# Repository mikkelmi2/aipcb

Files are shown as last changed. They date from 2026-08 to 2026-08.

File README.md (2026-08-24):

# aipcb

**A circuit board described as intent, compiled to KiCad.**

You write what the circuit *is* — in YAML. `aipcb` compiles it into real KiCad
schematics and boards, places, routes, pours, runs KiCad's own ERC and DRC on the
result, and can hand each pair to a field solver. Every problem points back at the
source line that caused it, and your KiCad edits survive the next build.

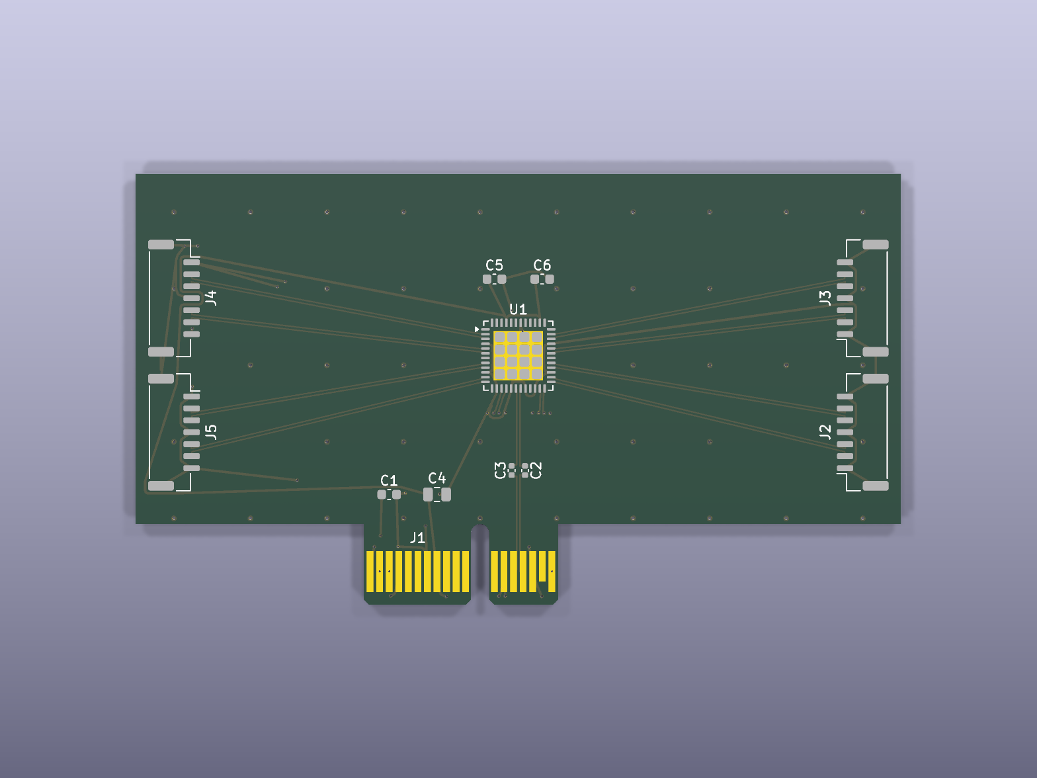
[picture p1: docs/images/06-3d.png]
examples/pcie-sata, rendered by KiCad from aipcb's own fabrication output


That is `examples/pcie-sata`, bundled here — a PCIe x1 card, four-port SATA, eleven
controlled-impedance pairs, four layers. Every image below is generated from it by
[`tools/make_images.py`](tools/make_images.py).

## What fifteen milestones hardened

**Deterministic compilation.** The same YAML gives byte-identical KiCad files —
rebuild unchanged and the file is not even rewritten. Every UUID is derived from
the source, which is what maps each element back to the line that asked for it.

**Verification you can trust.** ERC and DRC are run by KiCad itself, never
reimplemented, and come back as source-referenced diagnostics. Three invariants
guard the tool that produces them: `check` is a function of its source, no two
nets' copper may overlap, no simulation slice may be built with unbonded copper or
an unreachable reference plane. Each was learnt from a real defect, and
[`docs/reports/`](docs/reports/) tells the stories.

**Schematic generation.** Sheets drawn by convention from what the source already
knows — what serves what, which rails go up — proven identical to the source
netlist pin for pin, and ERC-clean.

**Manual layout is first-class.** `preserve` carries your KiCad edits across
rebuilds, `sync-placement` writes parts you moved back into the source,
`routing: manual` marks a net as yours, and the Freerouting bridge checks what
another router sends back.

## Maturity at a glance

| | | |
|---|---|---|
| Source format, compilation, `check`, schematics | **stable** | [`format.md`](docs/format.md) |
| Manual layout — preserve, `sync-placement`, `routing: manual` | **stable** | [`workflows.md`](docs/workflows.md) |
| Part placement | **basic** — shelf-packed clusters, unoptimised on purpose | [`roadmap.md`](docs/roadmap.md#placement) |
| Autorouting | **beta** — finishes this corpus, has never met a board it did not design | [`topology.md`](docs/topology.md) |
| SI simulation | **beta** — physically valid on ten of eleven links | [`m13.md`](docs/reports/m13.md) |
| Freerouting bridge | **new** — landed in M14e | [`external-routers.md`](docs/external-routers.md) |

## What beta means here

**The autorouter** finishes the corpus: `examples/pcie-sata` comes back **90 of 90
connections routed, 12 of 12 pairs coupled, 0 errors from KiCad's own DRC**, on
four layers. What it has not done is meet a board somebody else designed. The label
costs little: it **fails loudly**, naming each connection it could not finish
rather than leaving the board quietly short, and it is **optional** —
`routing: manual` and the Freerouting bridge take it out of the loop.

**SI simulation** extracts ten of the eleven flagship links physically; the
eleventh is reported unusable rather than plotted. It validates the layout you
declared, not the board a fabricator presses: it finds a pair routed too narrow, it
does not replace a test coupon, and it certifies compliance with nothing.

*Beta is a measurement, not a mood:* routing graduates once it has routed five
externally-contributed boards, passed a harder congestion stress example, and been
benchmarked against board size. The third of those is **done** — `aipcb bench`
records the whole corpus and CI diffs a subset on every change; routing cost grows
close to linearly in connections × triangulation size, and the numbers are in
[the M17 report](docs/reports/m17.md). The other two need a board this project did
not design. [The conditions in full](docs/roadmap.md#maturity-and-graduation).

## Source to fabrication, in six steps

### 1. Declare intent, not geometry

The width is *derived* from the impedance and the stackup — you never compute it:

```yaml
net_classes:
  pcie_tx:
    impedance_diff_ohm: 85    # the requirement; the trace width follows
    diff_pair_gap_mm: 0.15    # a manufacturing choice, so an input
    max_skew_mm: 0.127        # PCIe CEM r3.0 §4.7.7, for an add-in card
    reference: In1.Cu         # the plane the return current uses
```

### 2. It compiles to a schematic

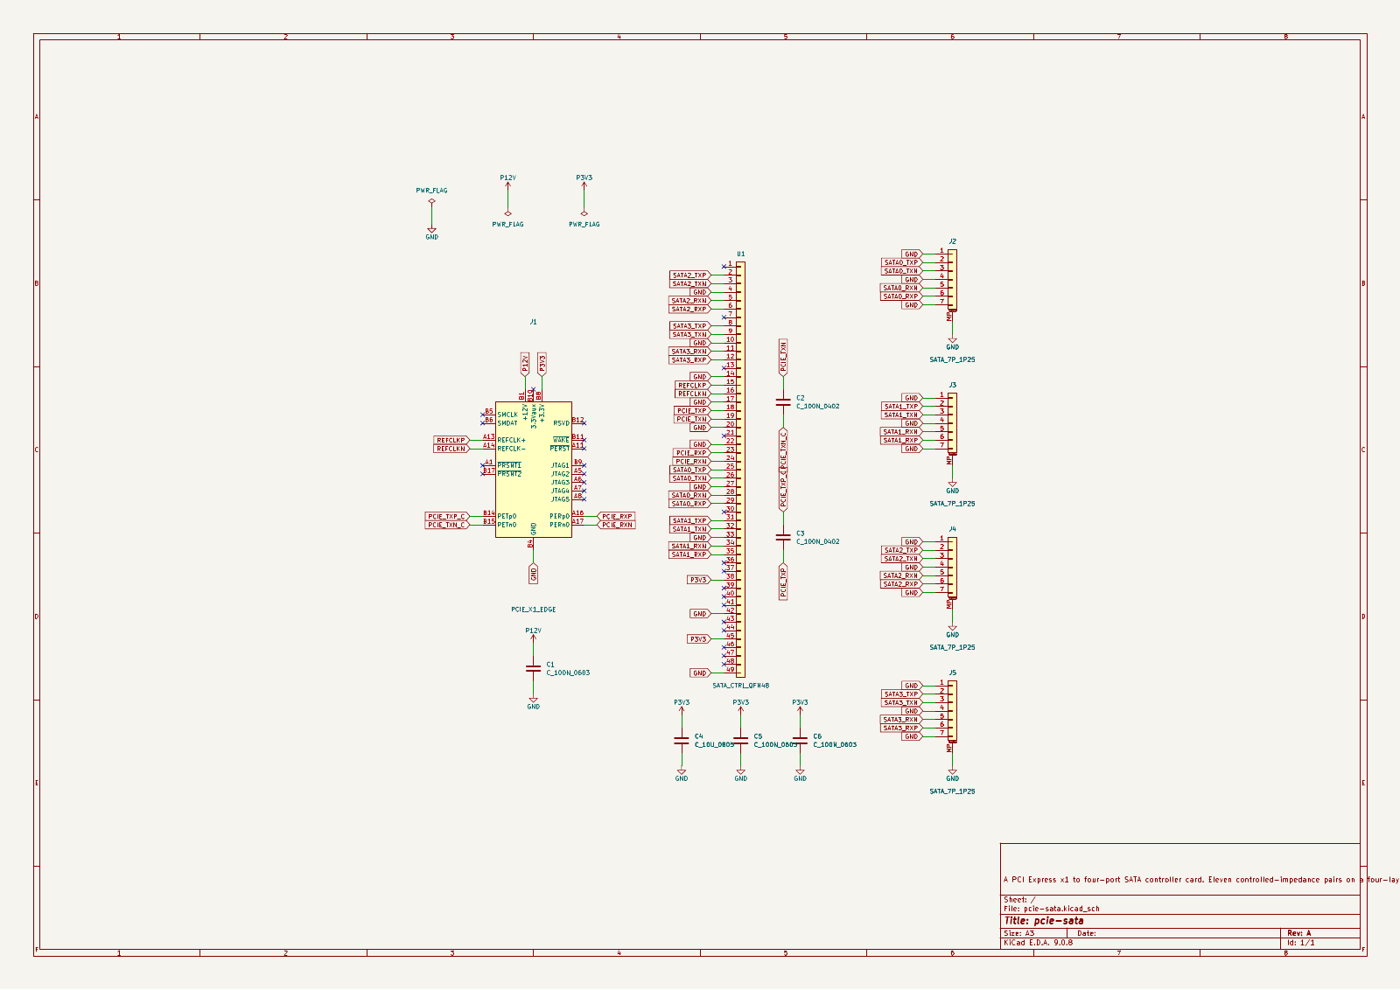
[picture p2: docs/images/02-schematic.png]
The pcie-sata schematic, rendered to A3


### 3. Parts are placed

Mechanically-fixed parts anchor the board, everything else is placed relative to
what it serves, and the outline is checked against the card-edge footprint's own
`Edge.Cuts` rather than drawn twice.

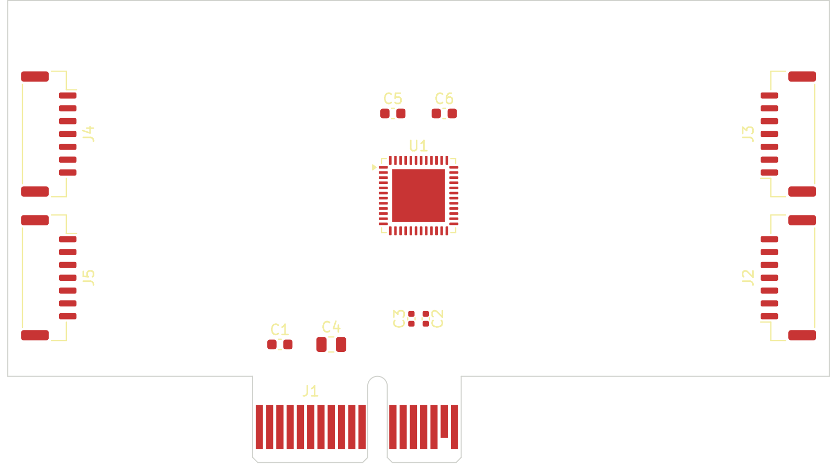
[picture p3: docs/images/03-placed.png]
The placed board, before any copper


### 4. And routed

A topological router negotiating congestion across four layers. Coupled pairs route
as one object — through the AC-coupling capacitors, across layer changes, at the
derived width.

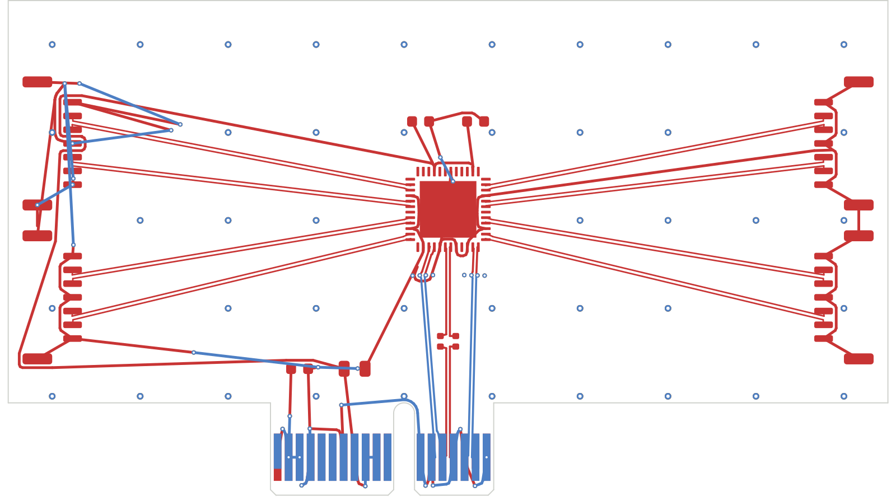
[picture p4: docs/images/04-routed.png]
The routed board, all eleven pairs coupled


### 5. The pairs are simulated

`aipcb simulate` slices each pair out of the routed board with its reference plane,
meshes it, runs openEMS.

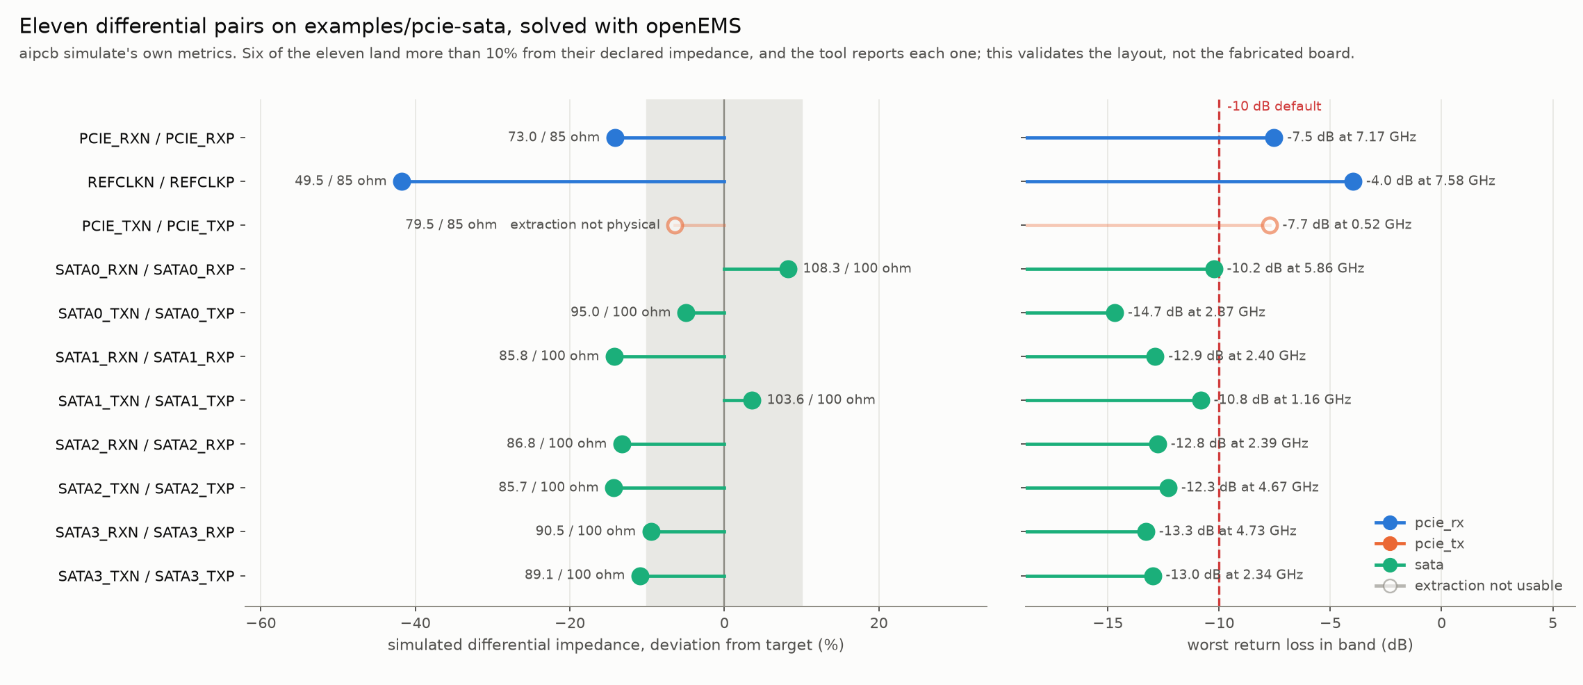
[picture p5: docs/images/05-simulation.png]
Simulated differential impedance and worst return loss, for each of the eleven pairs


The honest version of that picture: **six of the eleven pairs come back more than
10% from the impedance they declared**. That is the step doing its job: the
closed-form width says one thing, the field solver says how wrong it was.

### 6. And exported for fabrication — or for assembly

`aipcb export` writes Gerbers, drill files, a BOM and a placement file — the render
at the top of this page is KiCad's, from that output. `--assembly` adds what an
*assembler* needs on top of what a fabricator does: a bill of materials and a
centroid file in JLCPCB's or PCBWay's own columns, and a placement overlay drawn
from the centroid file itself, so the rotations can be looked at before anything is
ordered.

## You do the layout, if you want

| Mode | You do | aipcb does |
|---|---|---|
| **Full auto** | nothing | places, routes, pours, checks |
| **Hybrid** | draw the nets you care about, in KiCad | routes the rest *around* your copper, never through it, and checks all of it identically |
| **Fully manual** | all the copper | schematic, placement, pours, ERC/DRC, high-speed checks, export |

Hybrid is the one most people want. Mark a net or a whole class as yours:

```yaml
nets:
  PCIE_TXP: { class: pcie_tx, routing: manual }   # this one is mine
```

`aipcb check --json` then reports every net as `manual-routed`, `manual-pending`,
`auto-routed` or `handed-over`. `manual-pending` is the one that matters: a board
whose critical pairs are declared-and-not-yet-drawn looks finished to anything
counting unrouted connections, and this names it. Or hand the board to another
router — [Freerouting, headlessly](docs/external-routers.md).

## Quickstart

Python 3.12+ and **KiCad 9**, the backend rather than an optional extra: compiling
reads its stock libraries, and check, render and export shell out to `kicad-cli`.

```bash
git clone https://github.com/mikkelmi2/aipcb && cd aipcb
python3 -m venv .venv && .venv/bin/pip install -e .
.venv/bin/aipcb validate examples/usb-port/design.yaml
```

About 7 seconds on a warm pip cache, and out comes `ok: no problems found` with a
one-line summary. Now build it and open the result in KiCad:

```bash
.venv/bin/aipcb build examples/usb-port/design.yaml
kicad examples/usb-port/usb-port.kicad_pro
```

Then break it on purpose — change `diff_pair: USB_DP` to `USB_DPP` under
`nets: USB_DM:` — and validate again. Located, coded diagnostics rather than a
stack trace is what makes the loop work:

```
examples/usb-port/design.yaml:53:3: error[asymmetric-diff-pair]: net 'USB_DP'
names 'USB_DM' as its differential partner, but 'USB_DM' names USB_DPP
  at: nets.USB_DM.diff_pair
  hint: set `diff_pair: USB_DP` on 'USB_DM'
[... and error[unknown-diff-pair] for the net 'USB_DPP' that does not exist]

2 errors
```

`--json` gives the same thing machine-readably. [`docs/format.md`](docs/format.md)
is the reference for every key; [`docs/workflows.md`](docs/workflows.md) is how the
loop is used.

## What it does not do

**Not built.** Dense BGA escape, DDR fly-by topologies, HDI (blind and buried
vias), six or more layers, multi-sheet schematics, buses. Not "coming soon" —
absent, and a board needing them hands over rather than guesses. The class shown to
finish is the one above: small, high-speed-critical, two or four layers, and
[`docs/roadmap.md`](docs/roadmap.md) says which of the rest are wanted.

**No board from this repository has been fabricated yet.** When one has, this
paragraph will say so with pictures.

## Documentation

[`docs/README.md`](docs/README.md) is the map, and repeats the tiers above.

**This project was built milestone by milestone by AI agents, and the whole
engineering record is in the repository** — every specification, thirteen decision
records, and a delivery report per milestone measuring what actually landed. Start
at [`docs/reports/`](docs/reports/): written for someone who was not there, and
candid about what did not work.

Contributions are welcome — [`CONTRIBUTING.md`](CONTRIBUTING.md) says how. A board
this did not design is the most useful thing you can bring.

Apache-2.0. See [`LICENSE`](LICENSE) and [`NOTICE`](NOTICE).

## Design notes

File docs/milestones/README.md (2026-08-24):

# Milestones

The milestone specifications this project is built from, in execution order, each
paired with its delivery report in [`docs/reports/`](../reports/). A milestone file
is the *prompt* — what was asked for; the report is what was actually delivered,
with the numbers.

> **These files describe planned or historical work.** They are only relevant when a
> milestone is explicitly being executed. If you are doing ordinary development
> work, do not read a future milestone file as a description of existing
> functionality — nothing beyond the executed rows below is built. For what the project *does*
> today, read [`README.md`](../../README.md), [`docs/format.md`](../format.md) and
> the ADRs in [`docs/decisions/`](../decisions/).

| File | Milestones | Status |
|---|---|---|
| [`m1-m7-base.md`](m1-m7-base.md) | M1–M7 — source format, KiCad emission, check loop, query layer, incremental builds, topological routing | executed |
| [`m8-multilayer.md`](m8-multilayer.md) | M8 — layered triangulations, negotiated congestion, differential pairs | executed |
| [`m9-mech-placement.md`](m9-mech-placement.md) | M9 — board outline, mechanical placement, fanout, honest failure | executed |
| [`m10-pours.md`](m10-pours.md) | M10 — copper pours, stitching vias, plane integrity | **blocked** — see [`m10.md`](../reports/m10.md) |
| [`m11-highspeed.md`](m11-highspeed.md) | M11 — controlled impedance, edge connectors, via transitions | pending |
| [`m12-simulation.md`](m12-simulation.md) | M12 — SI simulation integration (openEMS/gerber2ems) | pending |
| [`orchestrator-m10-m12.md`](orchestrator-m10-m12.md) | runs M10 → M11 → M12 unattended, with gates between them | pending |
| M13 | routing correctness, the impedance model, the skew verdict | executed — [`m13.md`](../reports/m13.md) |
| M14 | readable schematics, optional routing, the external-router bridge | executed — [`m14.md`](../reports/m14.md) |
| [`m15-public.md`](m15-public.md) | M15 — hygiene sweep, licence package, the public README, contributor surface, CI | executed — [`m15.md`](../reports/m15.md) |
| M16 | toporouter lessons, part 1 — the capacity check's honesty, the exposure guards, the benchmark harness | executed — [`m16.md`](../reports/m16.md) |
| [`m17-measured-improvements.md`](m17-measured-improvements.md) | M17 — router improvements, part 2: via minimisation, retrace elimination, stretcher performance | executed — [`m17.md`](../reports/m17.md) |
| [`m18-literature-survey.md`](m18-literature-survey.md) | M18 — the routing literature survey (documentation only) | executed — [`m18.md`](../reports/m18.md) |
| [`m19-incremental-geometry.md`](m19-incremental-geometry.md) | M19 — router improvements, part 3: the congestion stress board, and the geometry that gets rebuilt | executed — [`m19.md`](../reports/m19.md). M19s and M19a landed, **M19b was rejected on its own numbers**, M19c's gate is open and sequenced after the fab round, M19d published. The review that turned M18's draft into this is [`m19-review.md`](../reports/m19-review.md) |
| [`m20-placement-quality.md`](m20-placement-quality.md) | M20 — placement quality: rotation, routability-estimated packing, and the zero-router-change experiment | **approved** 2026-08-24 — nothing started; sequenced after the `pcie-sata` fab round |
| [`m21-assembly-outputs.md`](m21-assembly-outputs.md) | M21 — assembly outputs: BOM and pick-and-place export, for an assembled order | executed — [`m21.md`](../reports/m21.md). The files are built and reviewed; **the acceptance criterion is not met and the reason is the design rather than the tooling** — `examples/pcie-sata`'s controller is a stand-in with an invented pinout and cannot be given a part number |

**Drafting a chain of candidates?** Budgets re-anchor after every landed one — see
[CLAUDE.md](../../CLAUDE.md#budgets-re-anchor-after-every-landed-candidate). A budget
quoted as a percentage of a corpus the same milestone is allowed to change, or priced
off a profile an earlier candidate has already invalidated, is how M19 lost two
candidates that had both done real work.

The delivery report requirement was introduced with M10, so the earlier
milestones ran without one. [`m8.md`](../reports/m8.md) was reconstructed after the
fact from the repository's own history and says so at the top;
[`m9.md`](../reports/m9.md) was written from that milestone's own measurements
immediately after it landed. There is no report for M1–M7.

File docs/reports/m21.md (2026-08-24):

# M21 — assembly outputs: BOM and pick-and-place

The fab round wanted two files an assembler accepts. They exist now, in three
formats, with the research behind each column recorded in
[ADR 0015](../decisions/0015-assembly-outputs.md) and a placement overlay to check
them against.

**And the milestone's own acceptance criterion is not met, for a reason that is not
about the tooling.** `examples/pcie-sata` cannot produce a package with zero
missing-part-number warnings, because seven of its eleven placed parts have no
manufacturer part number and one of them cannot be given one: the SATA controller is
a stand-in with an invented pinout. §6 is that finding in full, and it is the part of
this report worth reading first if the next session is the order.

Measured on 2026-08-24, KiCad 9.0.8, on the development machine.

---

## The scoreboard

| | Asked for | Delivered |
|---|---|---|
| **research** | current JLCPCB and PCBWay requirements, in an ADR with sources | [ADR 0015](../decisions/0015-assembly-outputs.md) §2, both fabs, fetched from their own documentation |
| **M21a** procurement fields | `mpn`, `manufacturer`, `supplier_refs`, `assembly`, backward compatible | done; `assembly` **measured rather than defaulted**, and a fourth value added — §2 |
| **M21b** BOM export | `--bom [--format …]`, grouped, deterministic | done, three formats |
| **M21c** CPL export | `--cpl [--format …]`, rotation mapped, overlay, back-side guard | done; **no rotation-correction table ships, deliberately** — §4 |
| **M21d** the bundle | `--assembly`, zipped, committed acceptance artifact | done; artifact at `tests/golden/pcie-sata/assembly/`, checklist in §5 |
| **acceptance** | pcie-sata exports with zero missing-mpn warnings | **not met** — seven parts block it, §6 |

---

## 1. The audit: what already existed, and why none of it was an assembly file

M21's brief carried a correction — `aipcb export` advertises "a BOM and a placement
file", so this might be hardening rather than building. It was worth checking and the
answer was no. What shipped before M21:

* **`bom.csv`**, from `kicad-cli sch export bom`, columns
  `Reference,Value,Footprint,QUANTITY,Description`. No part number, no manufacturer,
  no fab id — because none of those was ever written into the schematic. The
  `Supplier` model has carried `manufacturer` and `mpn` since the beginning and
  **only `datasheet` was ever emitted anywhere**; the other two were dead fields.
* **`pcie-sata-all-pos.csv`**, from `kicad-cli pcb export pos`, columns
  `Ref,Val,Package,PosX,PosY,Rot,Side`, sides spelled `top`/`bottom`, rotations
  signed.
* Designators compressed to ranges (`J2-J5`) by KiCad's grouping — and neither fab
  documents range notation, while JLCPCB matches designators between the two files
  literally.

Both files are correct KiCad output. Neither is a file an assembler takes. They are
kept exactly as they were — byte-identical, still in the fabrication package — and
the assembly files are additive and off unless asked for.

The full gap table is [ADR 0015](../decisions/0015-assembly-outputs.md) §1.

---

## 2. M21a — the schema, and the one place the brief was not followed

`mpn`, `manufacturer` and `supplier_refs` are as specified. `assembly` is where this
deviates, and it is worth stating plainly because it was a deliberate refusal of the
brief's default.

> **Brief:** `assembly: smt | tht | dnp | none` (default smt)
> **Built:** the same four values, plus a fifth state — *unset* — which is
> **measured off the footprint** rather than defaulted.

The reason is a measurement on this repository's own corpus. Four bundled examples
are built around through-hole parts: the breakout headers in `congestion`, the DIP-8
in `mcu-4layer` whose two rows of pins are the obstacle that board exists to route
around, the pin headers in `backplane`, the power header in `ldo-supply`. PCBWay's
centroid file is documented as **surface-mount only**. A default of `smt` would have
put every one of those into a file that must not contain them, and it would have done
it silently, in exactly the file whose job is to be checked.

So an undeclared `assembly` is read off the footprint KiCad actually placed — its
`(attr …)` flags, then its pad types — and a declaration always wins. Verified live:

```
mcu-4layer, generic BOM        →  J2 (PinHeader_1x06)  tht
                                  U1 (DIP-8_W7.62mm)   tht
mcu-4layer, PCBWay centroid    →  J2, U1 absent; C1-C3, J1, R1-R3, U2 present
```

**A fourth value the brief did not have, which the corpus needed: `none`.** A
card-edge finger field and a mounting hole are on the board, are on a net, and are
neither bought nor placed. Before it existed, `examples/pcie-sata`'s gold fingers
appeared on the bill of materials as a line no assembler could source, and
`examples/enclosure`'s two M3 holes with them. `PCIE_X1_EDGE` and `MOUNT_M3_PAD` now
declare `assembly: none` and are absent from both files.

**Backward compatibility** is not asserted, it is exercised: `supplier: {mpn: …}`
predates this milestone and `ATTINY85_DIP8` and `AMS1117_3V3` still use it.
`Part.procurement()` folds the two spellings, declaring both with different values is
an error, and `mcu-4layer` exports with those two part numbers filled in from the old
spelling. Every one of the twelve examples exports.

---

## 3. M21b and M21c — the files

`aipcb export --bom --cpl --assembly --format jlcpcb|pcbway|generic` (repeatable).
Columns and per-fab rules come from each fab's published requirements; sources in
ADR 0015 §2. Three rules are worth repeating here because they are decisions rather
than transcription:

* **PCBWay's centroid holds surface-mount parts only** — their words. A format is
  therefore not a rename, it carries rules.
* **Designators are listed, never ranged.** `J2,J3,J4,J5`, not `J2-J5`.
* **DNP is said in words**, in the BOM's `Comment` column, because neither fab
  documents a machine-readable way to say it, and the part never reaches the
  centroid. A silent DNP is a fitted part.
* **JLCPCB's documented limits are checked too**, not only its column names: a BOM
  line carrying more than 200 designators is a rejected upload, so it warns and
  names the line. No bundled example reaches it — `backplane`'s sixteen terminator
  resistors are the longest line in the corpus.

**The coordinates are not computed twice.** The centroid is a transcription of the
placement CSV `kicad-cli` already writes for the Gerber package, which is exported
with the same `--use-drill-file-origin`. Measured on `pcie-sata`: `aux_axis_origin`
`(100, 145)`, `U1` at `(140, 119)` in KiCad's frame, `(40, 26)` in the file — origin
subtracted, Y inverted. A test asserts every centroid coordinate equals the placement
file's, so the assembler's file and the fabricator's are one measurement rather than
two that agree today.

**The bill is driven by the netlist, not by the placement file** — a bug found while
building, and worth recording. Deriving the BOM from placement rows meant that any
footprint KiCad excludes from position files silently vanished from the order. That
is right for a card edge and catastrophic for a battery holder, and only the design
knows which is which. Parts with no placement row are now on the bill and off the
centroid.

---

## 4. Rotation — the convention is implemented, the correction is not

This is the trap the brief named, and the answer is narrower than "implement the
mapping".

**The convention needs no transform.** Both fabs document degrees, counter-clockwise
positive. JLCPCB: *"The rotation of the component given in degrees. Positive values
are counter clockwise."* KiCad writes degrees, counter-clockwise positive. The only
difference is range — KiCad signs them, the fabs' samples run 0–360 — so the value is
folded into `[0, 360)`. **No part turns.** `-90` becomes `270`, which is the same
orientation said differently, and eight parametrised cases pin it.

**The correction is a different thing and no table ships.** What breaks boards is not
the convention but the zero reference: a fab whose parts library holds a package at a
different orientation from the KiCad footprint needs a per-package offset. Three
things were established about it:

1. **Neither fab publishes it.** JLCPCB documents the convention and not the offsets.
   There is no authoritative table to verify against — and M21's guardrail says the
   mapping must be verified against the fab's documented convention rather than
   inferred.
2. **It is not algorithmic.** The community tooling that solves this — KiBot's
   `rot_footprint`, `kicad-jlcpcb-tools`' rotation database — is a hand-maintained
   lookup of regular expressions over footprint names.
3. **It is not even a function of the footprint.** KiBot's own documentation:
   *"you can have two components with the same footprint and different rotations in
   the same project."*

A table keyed by footprint is a heuristic by construction, and a wrong offset looks
exactly like a right one until the board comes back. Copying one out of a GPL project
would also be the same act as copying its code.

**So the verification is a picture.** `--assembly` renders a placement overlay per
populated side, drawn from the centroid file's own rows — not from the board, because
the board is not what gets sent. Every part where the file puts it, turned the way the
file turns it, with a dot marking where pin one lands after that rotation, and the
bottom side mirrored as it is inspected in the real world.

the placement overlay

---

## 5. M21d — the acceptance artifact, and the checklist against it

`tests/golden/pcie-sata/assembly/` holds the package: the JLCPCB BOM and centroid,
the complete generic pair, and the top-side overlay. `python -m tests.regenerate_golden`
rewrites it and a test compares against it, so a change to a column, a part or a
rotation shows up as a diff — the diff an assembler would have received.

**The manual review, once, line by line:**

| Check | Result |
|---|---|
| every placed part has a part number | **no** — 7 of 11: `C1, C2, C3, C4, C5, C6, U1`. §6 |
| designators on the centroid all appear on the bill | yes — JLCPCB rejects a mismatch, and a test asserts the containment |
| designator case consistent between the files | yes — one source, one spelling |
| units millimetres, `Layer` = `Top`/`Bottom` | yes |
| rotations within [0, 360) | yes — `0`, `90`, `270` only on this board |
| rotations eyeballed against the overlay | yes — `J2`/`J3` on the east edge at 90°, `J4`/`J5` on the west at 270°, facing inward; `C2`/`C3` at 270°/90° either side of the transmit pair; `U1` at 0°. All agree with the routed board plot |
| non-components off both files | yes — `J1`, the card-edge finger field, appears on neither |
| DNP handling | **not exercised by this board** — it has no DNP parts. Unit tests cover it, and §5.1 exercises it end to end on a derived design |
| polarity | **not exercised by this board** — every part on it is non-polarised, so the overlay's main value, catching a backwards diode, is untested against a real design |
| byte-stable across runs | yes — asserted by a test over every file in the package |

Two entries in that table are honest gaps rather than passes, and they are why the
overlay is documented as the thing to look at rather than a formality: the first
design with a diode or an electrolytic is the one that tests it.

### 5.1 DNP, exercised on a real design rather than only in fixtures

No bundled example marks a part do-not-populate, so the acceptance clause "DNP flows
correctly through both files" was checked against a copy of `ldo-supply` with
`dnp: true` added to `J2` — one of its two identical 2-pin power headers, chosen
because it makes the harder claim as well as the easy one:

```
BOM   PWR_IN,J1,Connector_PinHeader_2.54mm:PinHeader_1x02_P2.54mm_Vertical,
      PWR_IN (DNP - DO NOT POPULATE),J2,Connector_PinHeader_2.54mm:PinHeader_1x02_P2.54mm_Vertical,
CPL   C1 C2 C3 C4 J1 U1                     ← J2 absent
```

`J2` is marked on the bill and off the centroid, which is the clause. **And `J1` and
`J2` did not merge**, though they are the same part with the same footprint and the
same value — which is the defect a unit test caught while this was being built: with
the part number alone as the grouping key, a do-not-populate instance and a fitted
one became one line, and that line was marked whichever it met first. Half the
board's headers would have been fitted or not according to alphabetical order.

---

## 6. What would block a real order

**Seven of eleven placed parts on `examples/pcie-sata` have no manufacturer part
number.** The tool names them rather than failing silently:

```
warning[assembly-missing-mpn]: 7 placed parts have no manufacturer part number:
  C1, C2, C3, C4, C5, C6, U1
```

They divide into two cases and only one of them is data entry.

**The six capacitors are a procurement decision nobody has made.** The library
specifies each of them completely enough to buy — "100 nF X7R ceramic capacitor,
0603, 50 V" — but choosing *which manufacturer's* 100 nF, and which LCSC code, is a
decision with a stock level and a price attached. This milestone did not make it up.
An invented LCSC code is not a missing part, it is **the wrong component soldered to
the board**, and that failure is silent until the board does not work. The one part
number added here, JST's `SM07B-GHS-TB` on the SATA connectors, was added because
KiCad's own footprint is a binding to exactly that part — the part number is in the
footprint's name — and not because it was looked up.

**`U1` cannot be given a part number at all, and this is the finding.**
`examples/library/highspeed.yaml` says so in its own header, and the audit for this
milestone is what made it matter:

* the symbol is a **borrowed 49-pin generic connector**, chosen because KiCad ships
  no symbol for an ASM1064-class bridge;
* the **pinout is this board's own invention** — the signal assignments are plausible
  and they are not any real part's;
* the **power architecture is explicitly scenery**: the library says a real bridge of
  this function has a core rail, separate analog and PLL supplies and an I/O supply,
  and carries 15–25 capacitors. This board declares two supply pins on one 3.3 V rail
  and carries six.

So there is no manufacturer part whose pins are wired the way this design wires them.
A part number written there would be a number an assembler could order and a
component that could not work — and, worse, a board that assembles cleanly and is
dead.

**What this means for the fab round, stated plainly.** M21's premise was that the
assembly files were the last tooling blocker before ordering `pcie-sata` assembled.
The tooling blocker is gone. **The blocker that remains is the design**: `pcie-sata`
is a routing demonstration with a stand-in controller, and it is not a board that can
be populated and work, whatever files are generated for it. That is a decision for
the owner and not something this milestone should have quietly resolved by inventing
data. Three ways forward, in the order they seem sensible:

1. **Order it bare.** Every fabrication file has been correct since M10 and the
   assembly files are not needed. The board demonstrates routing, impedance and
   pours, and none of that requires it to be populated.
2. **Give the flagship a real controller** — a real MPN, its real pinout, its real
   power tree — which is a design milestone with a schematic review in it, and would
   also give the SI work a part whose reference design exists.
3. **Assemble a different board.** `ldo-supply` and `mcu-4layer` are made of real,
   orderable parts and need only their part numbers filled in; both already carry
   two.

---

## 7. What is not built

* **Supplier API integration** — out of scope by the brief, and §6 is the argument
  for putting it on the roadmap: the thing that blocks an order is a part number
  nobody has looked up, and looking one up is exactly what an API does.
* **Panelization** — still fab-level, still out.
* **Two-sided assembly** — refused rather than approximated. `side: back` validates,
  warns and places on the front (M9), so an assembly export on a board with a
  back-side part errors with `assembly-back-side-unsupported` and names the parts.
  The guard stays until `side: back` is implemented.
* **Any router or placement work.** None was touched; every board hash is unchanged.

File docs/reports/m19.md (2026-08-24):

# M19 — router improvements, part 3: the stress board, and the geometry that gets rebuilt

M18 found that the function three milestones had called the hot spot costs 0.039
profiled seconds, and that what the `tighten` *stage* actually spends its time on is
building — and discarding — the free space, the triangulation and the via sites that
tightening is done against. This milestone acts on that, in the order the survey
recommended and the owner approved: build the board the work should be measured on,
then take the two cheap candidates, then decide whether the expensive one is still
worth its risk.

Everything below was measured on 2026-08-24 on the development machine (16 cores,
30 GB RAM, Linux 7.0.0-29-generic), CPython 3.14.4, Shapely 2.1.2 / GEOS 3.13.1,
KiCad 9.0.8 — the same machine and the same versions the M16, M17 and M18 figures
were taken on, which is the only reason the wall-clock comparisons mean anything.

---

## The scoreboard

| Candidate | Budget, stated before | Measured | Verdict |
|---|---|---|---|
| **M19s** the congestion stress board | more nets than channels on ≥ 1 cut, from the tool; routes or hands over cleanly; byte-stable; no runtime budget | 168 connections, **110 routed / 58 handed over**; the capacity arbiter fires **132 times**, worst cut 3.77 mm against 4.95 mm of demand; **5 negotiation iterations, not converged**; byte-stable; 137.3 s | **landed** |
| **M19a** vectorise the point-location tail | ≥ **10 %** corpus `router_seconds`, **every board hash byte-identical** | **−2.9 %** corpus, −8.3 % on the eleven original boards, −20.8 % on the board it helps most; **every hash byte-identical**; tie-break tested | **misses its budget — kept, §2.3 flags the call** |
| **M19b** bound the private repair field | ≥ **25 %** further, completion and copper unchanged | **−1.0 %** corpus, −9.7 % on the eleven; completion unchanged; **copper +12.5 mm on `pcie-sata`** | **rejected**, reverted, numbers in §3 and in the survey note §5 |
| **M19c** incremental free-space mesh | conditional on M19a + M19b landing ≤ half the corpus routing time | gate **opens** (2.9 % landed), and the stress board's profile says **64 % of its routing time is `triangulate_free`** | **not started** — the fab round comes first, §4.2 |
| **M19d** re-fit the extrapolation | publish the new exponents against M16's and M17's | eleven boards **1.67 / 2.55 / 1.09**, unmoved again; twelve boards **1.87 / 2.00 / 1.03**; 900 connections **9.3 → 22.5 min** | **published** |

---

## 0. Before writing code — the profile re-taken at this HEAD

[CLAUDE.md](../../CLAUDE.md)'s rule, and the milestone's own "Before writing code"
section, both demand that M18's table be re-measured rather than assumed. It was, at
this milestone's HEAD (`c6c67b5`, whose `src/` is byte-identical to the baseline
commit `3b59a52`), from a scratch script outside the repository. No timer went into
`src/`.

### 0.1 The table reproduces

| | M18 (`4a41546`) | M19 (`c6c67b5`) |
|---|---:|---:|
| `pcie-sata` unprofiled wall | 19.3 s | **19.314 s** |
| `pcie-sata` profiled wall | 37.4 s | **30.625 s** |
| `_retry` → `_repair` cumulative | 16.30 s | **16.340 s** |
| `field.py::_via_sites` | 12.35 s | **12.367 s** |
| `geometry.py::geometry_for` | 10.71 s | **10.687 s** |
| `triangulate.py::locate_many` (tottime) | 2.80 s | **2.808 s** |
| `shapely::constrained_delaunay_triangles` | 4.30 s | **4.309 s** |
| `triangulate.py::_inside` calls | 3 140 252 | **3 140 252** |
| `triangulate.py::_sign` calls | 9 426 354 | **9 426 354** |
| `funnel.py::tighten` | 0.039 s | **0.039 s** |

The one number that moved is the profiled wall clock, 37.4 s → 30.6 s, which is the
instrument and not the router: the call counts are identical to the unit and every
cumulative figure agrees to three decimal places. **M18's profile stands.**

### 0.2 The split M19c's value depends on

The milestone asks for `geometry_for`'s cost to be split between the GEOS set
operations and the triangulation, because *"an incremental mesh replaces only the
second unless the set operations go too"*. Measured by wrapping the real functions
from outside, in a separately-timed third run so the wrappers never contaminate the
unprofiled figure:

| `pcie-sata`, wall seconds under wrappers | seconds | calls |
|---|---:|---:|
| `geometry_for` total | 7.527 | 176 |
| ├ `free_space` — the GEOS set operations | **1.767** | 244 |
| │  └ of which `union_all` | 1.255 | 244 |
| └ `triangulate_free` — the triangulation | **6.900** | 244 |
| &nbsp;&nbsp;&nbsp;└ of which `constrained_delaunay_triangles` | 4.294 | 244 |

(`free_space` and `triangulate_free` are called 244 times against `geometry_for`'s
176 because `build_field` calls them too; the split is over all of them, which is
the number an incremental mesh would have to displace.)

**The answer is roughly 20 : 80.** Of the geometry construction, the set operations
are 1.77 s and the triangulation 6.90 s, of a 16.6 s instrumented run. So an
incremental mesh addresses the larger share — but the `free` polygon itself cannot
go, because `_via_clears` and `_covered` ask it distance-to-boundary questions a
triangulation answers badly. **L1's ceiling on this board is therefore the 6.9 s of
`triangulate_free`, not the 8.7 s of both**, and 4.3 s of that 6.9 s is inside GEOS
already. That figure is what §4 weighs the gate against.

The same measurement on `mcu-4layer`: `geometry_for` 1.764 s, `free_space` 0.476 s,
`triangulate_free` 2.247 s, `constrained_delaunay_triangles` 1.418 s, of a 5.2 s
instrumented run. Same shape, same ratio.

---

## 1. M19s — the congestion stress board

### 1.1 What it is

[`examples/backplane`](../../examples/backplane/design.yaml) is a six-slot passive
backplane for a card cage: a 20-way ribbon from the host at the west end, six card
positions on a 22 mm pitch, sixteen pull-ups terminating the bus at the east end, on
a four-layer stackup with a ground plane on In1 and a power plane on In2. 30
components, 18 nets, 168 connections attempted, 190 × 56 mm.

The difficulty is mechanical and it is arithmetic. The cage's card guides sit
between adjacent card positions, they are bolted through the board, and nothing may
pass under one — so each guide leaves a single **4.0 mm channel** across the middle
of the board, and everything on the bus has to use it, seven times over.

* Sixteen signals at 0.25 mm wide with 0.2 mm clearance want **0.45 mm** of any cut
  they cross. VCC and GND want **0.6 mm** each. **Demand at each channel: 8.4 mm.**
* The channel is 4.0 mm. With the guide's own clearance off both sides, the shared
  field scores the cut across it at about **3.8 mm per signal layer — 7.6 mm** across
  the two of them.

Eight point four against seven point six, seven times. It does not fit, and it is
not meant to.

### 1.2 More nets than channels, from the tool

The milestone asks for this to be shown by the capacity model rather than asserted
in prose. The router's own arbiter — `_blocking_cuts` in
[`plan.py`](../../src/aipcb/route/plan.py), charging the same cuts against the same
`LayerField` capacities that
[`check_capacity`](../../src/aipcb/route/check.py) charges declared sketches
against — reports it on every handed-over connection, under `blocked_at` in
`aipcb route all --json`:

```json
{"layer": "B.Cu", "at": [145.0, 128.0], "width_mm": 3.767, "demand_mm": 4.95,
 "over_subscribed": true,
 "nets": ["D1","D10","D11","D2","D3","D7","D8","D9","IRQ","RESET","STROBE"]}
```

**Eleven nets wanting 4.95 mm of a corridor that is 3.767 mm wide.** Across the run
the arbiter marks a cut over-subscribed **132 times**, and `aipcb bench` counts
**130 over-subscribed cuts** on the finished board. Both are the same capacity model
`check_capacity` implements; the difference is only that the arbiter charges the
router's own legs and `check_capacity` charges sketches from `layout.routes`, of
which this design deliberately declares none — declaring them would take the nets
out of the negotiation, which is the one thing this board exists to exercise.

**This is the first time the capacity arbiter has ever refused anything.** M17a
built it against M16a's special-cut model and found *not one* span on the whole
corpus rejected on capacity; length was binding everywhere. It is not binding here.

### 1.3 The honest outcome: it hands over, and says why

| | |
|---|---:|
| connections attempted | 168 |
| routed | **110** (65.5 %) |
| handed over | **58** |
| negotiation iterations | **5** |
| converged | **no** |
| crossings / self-crossings | 0 / 0 |
| copper | 2 690.150 mm |
| vias | 33 |
| DRC | clean on everything it did route |

Every one of the 58 is a `route-handed-over` warning naming the connection, the cut
that stopped it, that cut's width, the demand on it and the nets contending for it.
Nothing is silently dropped.

**Which nets lose is the interesting part, and it is what the design predicted.**
`CLK` is `rip_up: protected` at priority 90; it is routed end to end. Four of the
fifteen ordinary bus lines — `D0`, `D9`, `RESET`, `STROBE` — complete not one hop of
seven. The protection did exactly what the class docstring says it does, on the only
board in this repository with enough pressure to make it matter.

`backplane` is registered in `tests/conftest.py`'s `UNROUTABLE_EXAMPLES` alongside
`overconstrained`, with the reason written out there: it was built to be over
capacity, and a version of it that routed cleanly would have failed at its job.
Everything it *does* route is still DRC-clean, and
`test_routing_is_byte_stable`'s guarantee holds — two consecutive runs produce the
identical board, SHA-256 `ebc7d8a5…`.

### 1.4 The anchor point, published as a miss

M17d fitted `router_seconds` against connections attempted over the eleven boards
and extrapolated 11.3 minutes for a 900-connection board. The whole reason to build
a board at the top of the range is to find out whether that fit means anything out
there. Running M17d's method verbatim over the *eleven original boards* and asking
it to predict this one:

> **Predicted 38.6 s for 168 connections. Measured 137.3 s. A factor of 3.6.**

The fit under-predicts, badly, and the direction is worth naming: **the eleven-board
corpus contained no board that failed to converge in one negotiation iteration**, so
the fit had no way to see the cost of the other four. A power law in connections
alone cannot model a board that routes its connections five times over. §5 re-fits
with this point included and reports what it does to the exponent.

### 1.5 The corpus grows from eleven boards to twelve

The baseline is refreshed in its own commit, per
[`bench/results/README.md`](../../bench/results/README.md)'s rule. Both sets of
totals, so the step is visible and is not mistaken for a regression:

| | eleven boards (`3b59a52`) | twelve boards (`be400c8`) | of which `backplane` |
|---|---:|---:|---:|
| connections attempted | 278 | 446 | 168 |
| routed | 275 | 385 | 110 |
| copper | 3 897.150 mm | 6 587.300 mm | 2 690.150 mm |
| vias | 81 | 114 | 33 |
| layer changes | 86 | 120 | 34 |
| corpus `router_seconds` | 29.476 | **167.036** | 137.342 |

**The eleven original boards are byte-identical.** `bench --compare` against the old
baseline reports exactly one line — `backplane: not in the baseline` — and no change
to any other board's hash, copper, vias or completion. The new board is 82 % of the
corpus's routing time, which is what a stress board is for and is why **every
percentage in §2 and §3 below is quoted against 167.036 s, not against 29.476 s.**

### 1.6 The multi-sheet linkage, noted and not built

[Multi-sheet schematic output is blocked on a design, not on machinery](../roadmap.md#schematics):
M14a was not built because the largest bundled example had 12 components and the
median 7. `backplane` has 30 components in eight blocks — `slot1` … `slot6` are six
instances of one `bus_slot` module, `term` is a `bus_termination`, and the host
connector and cage supply are the top level. **That is one sheet per block the day
the feature exists, and nothing in the source has to change for it.** This milestone
does not build multi-sheet output and must not; the design it was waiting for now
exists, which is the whole of the note.

---

## 2. M19a — the point-location tail, vectorised

### 2.1 What changed

`Triangulation.locate_many` batched the R-tree query at M17c and then ran a scalar
Python loop over the candidates it came back with, calling `_inside` — three
`_sign` calls each — once per candidate. M18 counted them: **`_inside` 3 140 252
times and `_sign` 9 426 354 times** on one board.

The three orientations are now computed over whole numpy arrays. The arithmetic is
the same three products subtracted the same way, in the same order, on the same
float64 values, so the signs are bit-identical to the scalar version's and the
verdict is the same verdict; what goes is the interpreter overhead of nine million
two-line function calls.

**The tie-break is the whole risk and it was written to, not hoped for.** Candidates
are tried in ascending triangle index so that a point on a shared edge lands in the
lower-numbered triangle, and a boolean mask does not reproduce that: it says which
candidates contain the point, not which of them has the lowest index. It is a stable
`lexsort` by (point, triangle) and a take-the-first-of-each-run.

`tests/test_routing.py::TestPointLocation` tests it explicitly: a point exactly on
the shared diagonal of two triangles; the same two triangles with their indices
swapped, which must answer the other way; both shared vertices; a point 1e-15 either
side of the diagonal; and — the case that would catch a subtler error — `locate_many`
against the scalar loop it replaced, over every incentre, edge midpoint and vertex of
`mcu-4layer`'s real triangulation. A scratch run outside the repository put 25 500
probes over six jittered meshes through both implementations and `locate`: no
mismatches.

### 2.2 What it bought

| `pcie-sata`, profiled | before | after |
|---|---:|---:|
| `triangulate.py::locate_many` cumulative | 7.976 s | *out of the top sixteen* |
| `triangulate.py::_inside` | 3.588 s / 3 140 252 calls | — |
| `triangulate.py::_sign` | 1.076 s / 9 426 354 calls | — |
| `field.py::_via_sites` | 12.367 s | **5.222 s** |
| `plan.py::_repair` | 16.340 s | **9.759 s** |
| wall clock, unprofiled | 19.314 s | **18.024 s** |

And on the corpus, against the twelve-board baseline at `be400c8`:

| board | baseline | M19a | change | hash |
|---|---:|---:|---:|---|
| backplane | 137.342 | 134.880 | −1.8 % | unchanged |
| congestion | 0.116 | 0.113 | −2.8 % | unchanged |
| diff-pair | 0.288 | 0.265 | −8.0 % | unchanged |
| enclosure | 2.089 | 1.972 | −5.6 % | unchanged |
| ldo-supply | 0.227 | 0.218 | −4.1 % | unchanged |
| led-blinker | 0.373 | 0.507 | **+35.9 %** | unchanged |
| mcu-4layer | 5.101 | 4.526 | **−11.3 %** | unchanged |
| overconstrained | 0.087 | 0.083 | −4.6 % | unchanged |
| pcie-sata | 16.381 | 15.085 | −7.9 % | unchanged |
| qfn-fanout | 3.039 | 2.868 | −5.6 % | unchanged |
| routing-demo | 0.287 | 0.253 | −12.0 % | unchanged |
| usb-port | 1.704 | 1.349 | **−20.8 %** | unchanged |
| **corpus, twelve boards** | **167.036** | **162.120** | **−2.9 %** | |
| **the eleven original boards** | **29.695** | **27.239** | **−8.3 %** | |

(The committed baseline was then re-measured at M19a's own commit and records
161.798 s. The 162.120 s above is the comparison run; the gap between the two is a
third of a per cent of one board's wall clock, which is why the corpus figures here
are quoted to one decimal place of percentage and no further.)

**Every board hash is byte-identical**, which was the hard requirement and the
criterion the milestone said not to argue with. Copper, vias, layer changes and
completion are identical to the digit.

**`led-blinker`'s +35.9 % is real, reproducible and not understood.** Measured on
its own it is 0.347–0.352 s, faster than its 0.373 s baseline; measured immediately
after `backplane` it is 0.347 s; measured inside the full twelve-board run it is
0.503–0.507 s, twice. So it is not run-to-run noise and it is not the board that
precedes it — it is something about the accumulated state of a whole corpus run, and
the one thing M19a adds to that state is an `(n, 3, 2)` array cached on every
`Triangulation` for as long as the triangulation lives. It is 0.13 s on a 162-second
corpus and the board's output is unchanged, so it is recorded here rather than
chased.

### 2.3 It misses its budget, and the reason is the corpus and not the change

**Asked: ≥ 10 % of corpus `router_seconds`. Delivered: 2.9 %.** On the eleven boards
the budget was drafted against, 8.3 % — still short. There is no denominator on
which this candidate clears 10 %.

The reason is visible in the per-board column the milestone asked for. `backplane`
is 82 % of the corpus and improves by 1.8 %, because **point location was never its
cost**: §4.1 has its profile, and 64 % of its routing time is `triangulate_free`.
The boards where point location *was* the cost improve by 8–21 %. M19s landing
first — which the owner's review moved it to the front to achieve — is what put a
board in the corpus whose bottleneck is somewhere else.

Under the [rejection rule](../milestones/m19-incremental-geometry.md#rejection-rule)
a candidate that misses its budget is rejected and its numbers are written into the
survey note's §5, which they have been. **The code is kept, and that is an owner
decision rather than a rule-following one, so it is flagged here rather than
buried.** The case for keeping it: it is forty lines inside one function, it is
strictly faster on eleven of twelve boards and within noise on the twelfth, its
output is byte-identical everywhere, and it removes 12.6 million Python-level calls
from a single predicate. The case against is the rule as written. §6 puts the
question to the owner.

> **Owner decision, 2026-08-24: kept, and the precedent is fenced here so that it
> cannot widen.** The exception applies only to a candidate that is *cost-free on
> every board* — byte-identical output, no runtime regression anywhere — and whose
> miss is attributable to the corpus being re-weighted underneath it rather than to
> its own numbers. **A candidate carrying any runtime cost gets no equivalent
> grace**, whatever else it can show: the rejection rule exists to stop
> runtime-costing quality techniques landing unpaid, and M19a is the opposite case.
> For everything else the rule stands exactly as written, and §3 is what it looks
> like applied.

---

## 3. M19b — bound the private repair field: **rejected**

### 3.1 What was built

`_repair` builds an entire whole-board `LayeredField` for one connection, sixteen
times on `pcie-sata`. Two versions were built and measured.

**The first bounded the free space itself** — clipping the board to the two pads'
bounding box inflated by a fraction of the board's diagonal, with a ladder of
widening attempts ending in the whole board, so that completion could not change by
construction. It is the version the milestone describes.

**The second bounded only the via sites**, keeping the free space and the
triangulation whole-board and re-deriving *only* the candidate site set when the
first attempt failed. This is strictly better on every axis that matters: the
expensive half of the field is paid for once whatever happens; reachability,
components and cut capacities stay whole-board, so a bounded attempt cannot decide a
pad is unreachable when it is not; and the sites it offers are a strict subset of
the whole board's, at the same positions.

The second version needed one clause the milestone does not anticipate, and it is
worth recording because the failure mode is the opposite of the expected one.
**A box that excludes the via a connection wanted does not make the search fail — it
makes it succeed with something absurd.** On `pcie-sata`, `GND/J5.1>J5.MP` went from
29.96 mm with two vias to **158.03 mm with none**: denied the pocket it wanted to hop
through, the search walked the long way round the board on one layer, and because it
*succeeded* nothing ever widened the box. The fix is that a bounded answer is
accepted only if it stays inside the box it was found in; one that wanders outside
is evidence that the bound shaped it, and the bound is lifted. That took
`pcie-sata`'s copper from +124.1 mm to +12.5 mm.

### 3.2 What it measured

Against the twelve-board baseline, with M19a already in:

| | baseline | M19a | M19b (sites, guarded) | vs M19a |
|---|---:|---:|---:|---:|
| backplane | 137.342 | 134.520 | 135.577 | +0.8 % |
| enclosure | 2.089 | 1.959 | 1.786 | −8.8 % |
| mcu-4layer | 5.101 | 4.515 | 4.030 | −10.7 % |
| pcie-sata | 16.381 | 14.999 | 13.199 | **−12.0 %** |
| qfn-fanout | 3.039 | 2.853 | 2.963 | +3.9 % |
| usb-port | 1.704 | 1.340 | 1.214 | −9.4 % |
| **corpus, twelve boards** | 167.036 | 161.618 | **160.049** | **−1.0 %** |
| **the eleven original boards** | 29.695 | 27.098 | **24.471** | **−9.7 %** |

Completion unchanged (385/446). Copper **+12.468 mm**, all of it on `pcie-sata`
(1 077.807 → 1 090.275 mm, +1.16 %), in one connection: `GND/U1.17>U1.49` goes from
3.52 mm with no vias to 15.99 mm with two. Ten of twelve board hashes hold;
`enclosure` and `pcie-sata` move.

The free-space-bounding version is worse and is recorded for completeness: corpus
+9.6 % against M19a — because on a board where most repairs *fail*, a ladder that
cannot lose a route pays for the whole-board field anyway and pays for the bounded
one on top. It also lost three connections on `backplane`, since a bounded repair
that succeeds differently changes the board for everything after it.

### 3.3 Why it is rejected

**Asked: ≥ 25 % further, at unchanged completion and unchanged copper.
Delivered: 1.0 % on the corpus, 9.7 % on the eleven boards, and copper moved.**

Three findings, in the order they matter:

1. **M19a and M19b were sized independently against the same profile, and they
   overlap.** *(This is now a standing rule —
   [CLAUDE.md, "Budgets re-anchor after every landed candidate"](../../CLAUDE.md#budgets-re-anchor-after-every-landed-candidate)
   — and it was applied retroactively in reading both results here: M19a is reported
   against the twelve-board corpus it actually ran on as well as the eleven-board one
   its budget was drafted against, and M19b's shortfall is attributed to the profile
   M19a left behind rather than to a failure of the technique.)* M19b's 25 % was
   priced off `_repair` at 16.30 s of 29.8 s profiled, of
   which `_via_sites` was 12.35 s. M19a took `_via_sites` to 5.22 s *before* M19b
   ran. Most of M19b's prize had already been collected by the candidate scheduled
   ahead of it. Additive budgets against one profile is the mistake, and it is worth
   carrying forward: **the second candidate's budget should be re-priced from the
   profile the first one leaves behind, not from the one that ranked them.**
2. **The corpus's cost has moved somewhere M19b does not reach.** `backplane` spends
   22.9 s of 199 profiled in `_via_sites` and **127.6 s in `triangulate_free`**.
   Bounding via sites cannot touch that, and bounding the triangulation makes it
   worse for the reason in §3.2.
3. **It moves copper, and that is what disqualifies it now rather than merely
   failing it.** The [sequencing rule](../milestones/m19-incremental-geometry.md#sequencing-and-the-fab-round)
   put M19b before the fab round *because* it "keeps completion and copper by
   construction". It does not. A candidate that moves `pcie-sata`'s copper belongs
   after the board is ordered, alongside M19c and M20 — which is where the same rule
   sends everything else that moves copper.

The code is reverted rather than left in the tree. The design is recorded above and
the numbers in the survey note's §5, so that the next person to propose bounding the
repair field meets this measurement rather than re-deriving it. **If it is revived,
revive the site-bounding version with the stays-inside-the-box guard, after the fab
round, and re-price it against the profile of the day.**

---

## 4. M19c — the gate: **open on the measurement, closed on the sequencing**

### 4.1 The evidence the gate did not have

The gate says: *do not start it if M19a and M19b together land more than half of the
corpus routing time.* They land **2.9 %** — M19a alone, since M19b is rejected.
**On its stated criterion the gate opens, and it opens wider than the survey
expected**, because the board M19s built has a profile the survey never saw.

`examples/backplane`, profiled at this HEAD (199.0 s profiled, 136.5 s unprofiled,
135.6 s under wrappers):

| | cumulative | tottime | calls |
|---|---:|---:|---:|
| `triangulate.py::triangulate_free` | **127.630 s** | 5.908 | 703 |
| `plan.py::_repair` | 123.953 s | 0.053 | 94 |
| `field.py::build_field` | 105.137 s | 0.458 | 95 |
| `geometry.py::geometry_for` | 71.569 s | 0.122 | 323 |
| `shapely::constrained_delaunay_triangles` | **53.508 s** | 53.508 | 703 |
| `field.py::_via_sites` | 22.916 s | 1.805 | 95 |
| `triangulate.py::free_space` | 21.199 s | 0.152 | 703 |
| `shapely::union_all` | 12.984 s | 12.966 | 765 |
| `triangulate.py::_link` | 12.485 s | 6.257 | 703 |
| `graph.py::search_path` (the whole multilayer A\*) | 13.876 s | 3.218 | 578 |

And the §0.2 split, on this board, in instrumented wall seconds of a 135.6 s run:

| | seconds | calls |
|---|---:|---:|
| `triangulate_free` | **87.073** | 703 |
| └ of which `constrained_delaunay_triangles` | 53.474 | 703 |
| `free_space` (the GEOS set operations) | 17.092 | 703 |
| └ of which `union_all` | 12.901 | 703 |

**Sixty-four per cent of the stress board's routing time is rebuilding the
triangulation, and thirty-nine per cent is one GEOS call inside it.** That is
exactly and only what an incremental mesh replaces. On `pcie-sata` the same split is
6.90 s of 16.6 s; on the board that now dominates the corpus it is 87.1 s of 135.6 s.
**L1's prize is larger than the survey priced it, and the reason it is larger is that
the corpus finally contains a board big enough to show it.**

The 20 : 80 ratio from §0.2 holds here too and matters the same way: the GEOS set
operations are 17.1 s and do not go away — `_via_clears` and `_covered` ask the free
polygon distance-to-boundary questions a mesh answers badly — so the ceiling is the
87 s, not the 104 s of both.

### 4.2 Why it is not started here anyway

The [sequencing the owner settled](../milestones/m19-incremental-geometry.md#sequencing-and-the-fab-round)
is not conditional on the gate:

> 1. **M19s, M19a, M19b** — this milestone's hash-preserving work.
> 2. **A BOM/CPL export milestone, then the fab round.** The board gets ordered.
> 3. **M19c, and any placement implementation from M20, after the board is ordered.**

Step 2 has not happened. M19c can move copper on `pcie-sata` and the rule exists so
that the copper measured and the copper produced are the same copper. **So the gate
is recorded as open and M19c is not started**, which is the same answer the
sequencing gave before the measurement and is now supported by it.

**And the larger prize strengthens the sequencing rather than pressing against it.**
The expected value of M19c went *up* between the survey and this measurement — from
"at most ~10 s of 30 on `pcie-sata`" to 87 s of 136 on the board that now dominates
the corpus. A prize that grew is a prize that keeps: waiting for the fab round costs
it nothing, and the board in flight is the one thing that cannot be re-run.
Confirmed by the owner on 2026-08-24.

Two things are worth carrying into the milestone that does build it, beyond what the
prompt already says:

* **Re-price it against `backplane`, not against `pcie-sata`.** A 30 % corpus budget
  now means roughly 48 s, and essentially all of it has to come off one board. That
  is a *more* achievable budget than the survey's framing suggested, not a less
  achievable one.
* **The deletion half is not optional here either.** M18 measured 84 obstacle
  disappearances on `pcie-sata`'s F.Cu alone; `backplane` rebuilds 703 triangulations
  against 244, over a repair pass that runs 94 times and fails 58 of them, so the
  sequence of obstacle sets is at least as non-monotone. Either constraint removal
  exists or the rebuild is the documented fallback, and which one must be stated up
  front.

Neither of M19c's two hard conditions — property-based testing of the hand-owned
predicate against shapely including the degenerate classes, and a kill-switch config
with the rebuild path retained and the predicate opt-in — has been touched, because
the candidate has not been started. `hypothesis` is still not a dependency.

---

## 5. M19d — the extrapolation, re-fitted twice

M17d's method verbatim: **log-log least squares of `router_seconds` against
connections attempted, against total cuts, and against connections × cuts.** Run
from a scratch script outside the repository over committed results files, so the
next re-fit is comparable to this one and not to a remembered number.

**Over the eleven original boards**, which is the line-for-line comparison with M16
and M17:

| Model | M16 | M17 | **M19** |
|---|---:|---:|---:|
| routing seconds vs **connections** | 1.72 (R² 0.94) | 1.70 (0.94) | **1.67 (0.95)** |
| routing seconds vs total cuts | 2.61 (0.82) | 2.57 (0.81) | **2.55 (0.84)** |
| routing seconds vs **connections × cuts** | **1.12 (0.97)** | **1.10 (0.96)** | **1.09 (0.97)** |
| 900 connections, extrapolated | 23.7 min | 11.3 min | **9.3 min** |

**The exponents did not move. Again.** M17c removed constant factors and left the
shape where it was; M19a removed more constant factors and left it where it was.
Routing cost on these eleven boards is still very close to linear in connections
times triangulation size, which is what "tighten every connection against a
triangulation of the whole board" predicts, and three milestones of constant-factor
work have not touched that. **That is the finding M19c exists to change**, because
changing rebuild-per-connection into update-per-connection is a change to the shape
and not to the constant.

**Over all twelve boards**, which is the better fit and the one to carry forward:

| Model | eleven boards | **twelve boards** |
|---|---:|---:|
| routing seconds vs **connections** | 1.67 (R² 0.95) | **1.87 (0.95)** |
| routing seconds vs total cuts | 2.55 (0.84) | **2.00 (0.88)** |
| routing seconds vs **connections × cuts** | 1.09 (0.97) | **1.03 (0.98)** |
| 900 connections, extrapolated | 9.3 min | **22.5 min** |

Three things fall out of the twelfth point, and they are why the milestone asked for
the fit to be published twice.

1. **The eleven-board fit under-predicts the new board by a factor of 3.9.** It
   expects 34.1 s for 168 connections; the board takes 134.7 s. An extrapolation
   from eleven boards spanning 4 to 90 connections had no way to know that.
2. **The connection exponent rises from 1.67 to 1.87 and the capability-ladder
   number more than doubles, from 9.3 to 22.5 minutes.** The honest reading is not
   that the router got slower — nothing about the eleven boards changed — but that
   the old number was fitted entirely below the range it was being used to predict.
   **22.5 minutes is the figure to carry forward**, and it is still an extrapolation
   from a corpus whose largest board is 168 connections. **Carry the caveat with the
   number, every time it is cited: it is fitted through exactly one board above the
   example class, and it is provisional until the curve has more points in the gap
   between 90 and 900 connections.** The old figure acquired a confidence it had not
   earned by being repeated without one; this one should not.
3. **The connections × cuts model gets *better*, not worse: R² 0.97 → 0.98, exponent
   1.09 → 1.03.** The twelfth board is the one point most able to break that model
   and it does not break it. Connections times triangulation size remains the thing
   routing cost is close to linear in, and the new board is expensive for exactly
   that reason: 168 connections against 11 776 cuts, re-triangulated 703 times.

One caveat on the connection fit, stated because it is the difference between a
number and a stopwatch reading: **`backplane` does not converge in one negotiation
iteration and every one of the eleven original boards effectively does.** It routes
its connections five times over. A power law in connections alone cannot see that,
so some of the exponent's rise from 1.67 to 1.87 is the corpus acquiring a second
kind of board rather than a bigger one. The connections × cuts fit, which is the
better model on both corpora, is much less disturbed by it.

---

## 6. What this leaves the owner

Three decisions, and one of them is not urgent.

**1. M19a missed its budget and the code is in the tree.** §2.3 makes the case both
ways. The rejection rule as written says reject; the change is forty lines, is
byte-identical on every board, and is faster on eleven of twelve. Reverting it is a
one-commit operation if the rule is to be applied literally, and the tie-break tests
are worth keeping either way. **This report keeps it and says so out loud rather
than quietly re-reading the rule.**

**2. The budgets in part 3 were priced additively off one profile, and that is why
two candidates missed.** M19b's 25 % was priced off a `_via_sites` that M19a had
already made less than half the size. Whatever milestone builds M19c should re-take
the profile and re-price *after* the candidate before it lands, not before it starts.
§3.3 finding 1.

**3. M19c's prize is bigger than the survey thought, and its budget should be
re-stated against `backplane`.** §4.1. Thirty per cent of the corpus is now about
48 seconds and nearly all of it lives in one function on one board. Nothing about
the risk assessment changes — it is still a hand-owned predicate against ADR 0006
and against the toporouter's cause of death, still conditional on the two hard
conditions the owner added, and still after the fab round.

And one thing that is not a decision: **`examples/backplane` is now the corpus's
centre of gravity, at 83 % of its routing time.** Every future runtime measurement is
mostly a measurement of that board, which is what a stress board is for and is also
a reason to keep quoting per-board numbers next to the corpus percentage. The
milestone asked for that and it is what caught both misses.

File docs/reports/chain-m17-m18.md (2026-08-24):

# Chain report — M17 → M18

An unattended run of two prepared milestones, 2026-08-24, in the pattern the M10–M12
chain established: a fresh subagent per milestone with no conversational memory, the
repository as the only thing carried between them, and every gate re-run by the
orchestrator rather than taken from the subagent's word. The
[orchestrator log](orchestrator-log.md#orchestrator-log--m17--m18) has the gate
detail; this is the summary.

Starting point `6b6a963`, ending point `7baf3f9` plus this report. Nothing halted.

**Both milestones passed every gate. The chain ends after M18 by design** — M18's
second deliverable is a *draft* milestone, and implementing unreviewed research
candidates is exactly the improvisation this project does not do. What the owner
needs to review is at the bottom.

---

## M17 — the measured candidates

Three candidates landed, none rejected. **Corpus routing time fell from 61.863 s to
29.476 s (−52 %)**, and it did so with **ten of eleven board hashes byte-identical to
M16** — the speed cost nothing in what the router decided. On the two slowest boards
the tightening stage fell **−55.6 %** (`pcie-sata`, 33.883 → 15.035 s) and **−52.5 %**
(`mcu-4layer`, 8.553 → 4.063 s) against a budget of ≥ 25 %. The via pass gave back
**4 vias and 30.285 mm of copper** for **+1.7 %** runtime against a +10 % budget, and
the E2 retrace on `pcie-sata` — the defect M16's own guard found on the day it
landed — is **gone**, verified here by routing the board through the CLI and
confirming `route-doubles-back` is absent from its fourteen diagnostic codes, for
**+1.3 %** against a +5 % budget. The guard stayed in the suite, inverted to assert
zero rather than deleted. The new capability-ladder number is **11.3 minutes for a
900-connection board**, down from 23.7 — and the honest note attached to it is that
the previously cited "≈ 31 min" does not reproduce from the committed baseline by
M16's own stated method, so the comparison published is the pair that does.

Two findings outlived the numbers. **M16's "37 of 90 layer changes made where no
corridor was half full" overstated the opportunity by an order of magnitude**: of 55
candidate spans corpus-wide, 2 collapsed — 21 rejected because the on-layer route is
*longer*, 32 because the free space is split, and **zero on capacity**. This router's
vias are, with four exceptions, load bearing, and the capacity arbiter built to
adjudicate them **never fired**, which the report states rather than dressing up as a
win. And the profile that produced the −52 % found the time was not where the stage
name said: two thirds of "tightening" was the congestion field being rebuilt per
repaired connection, 1.9 M Shapely `Point` constructions on one board. **No algorithm
changed** — the log-log exponents moved 1.72 → 1.70 and 1.12 → 1.10, which is the
evidence that M17 did not answer the question M18 was for.

*Deviations flagged:* M17a and M17b turned out to be **one mechanism** (every retrace
in the corpus *is* a via pair returning to its own layer), so no separate trimmer was
written; the controlled-impedance exclusion is **by class**, since the corpus cannot
verify it and the test hands the guard a synthetic candidate to refuse; one board
hash moved and no golden did. The orchestrator corrected one scoreboard cell that
read +1.6 % where the report's own §2.4 derives +1.3 % — inside budget either way,
but two statements of one measurement disagreeing is the failure mode these reports
exist to prevent.

## M18 — the literature survey

Research only: `git diff` over `src/`, `tests/` and `examples/` across its three
commits is **empty**, and 1 885 lines landed under `docs/`.

**The survey's headline is that the question three milestones have been asking was
aimed at the wrong function.** `funnel.py::tighten` — the tightening algorithm
itself, the thing the part-2 plan called the hot spot — costs **0.039 profiled
seconds of a 37.4-second route, 0.13 %**. This orchestrator reproduced that from a
freshly written profile script and got it to the millisecond. The `tighten` *stage*
genuinely is 93 % of routing and M16 was not wrong; almost none of that stage is
tightening. It is building the free space, the triangulation and the via sites that
tightening happens against, and discarding them for the next connection. On
`pcie-sata`'s F.Cu a thousand-triangle triangulation is rebuilt **137 times because a
median of two obstacles out of five hundred changed**.

So **M17c's open question is answered (b)** — but with the noun corrected. There is
nothing worth making incremental about tightening; what must stop being rebuilt is
the geometry. **(a) algorithm replacement is rejected on measurement**:
Hershberger–Snoeyink is worst-case optimal for this problem, it is what `funnel.py`
already implements, and it costs 0.13 %. **(c) a compiled kernel is rejected as
posed** — the largest single cost is already C — while one narrow piece of it
survives, because `_inside` runs 3 140 252 times and `_sign` 9 426 354 times in a
scalar Python loop that M17c stopped one function short of. Constant-factor work is
**not** exhausted, which is the opposite of what this chain expected to hear.

**Dayan's 1997 thesis was obtained in full, 161 pages** — the toporouter note's
largest gap, closed. Not by access: every live route is still shut, and it came from
a 2017 Internet Archive snapshot of a PDF the live site no longer serves. The note
says plainly that the second attempt succeeded by archaeology and that the copy could
vanish again. Reading it made the project's own backlog **smaller**: candidate C3's
detour pass, carried at 7–16 % on a second-hand two-board figure, is re-priced to
**~3.4 %** by Dayan's own ROAR measurement over ten bins and 427 branches — while
gaining the one structural argument it lacked, his §6.1 proof that some topologies
are unreachable by *any* net ordering. C5 lost ground twice over.

*Gaps, marked as gaps.* Six sources stayed closed and none is summarised from its
title. **NCTU-GR**, whose two-stage cost function is exactly what §2 set out to mine,
was unreachable — so §2 names what it could not get instead of padding. **No
algorithmic account of TopoR exists in any language that could be found**, and the
vendor claim that does exist ("25–40 % less wire length, 2–3× fewer vias") is filed
as a claim carrying no benchmark, baseline or method. §2 is also honestly blocked at
the other end: every negotiated-congestion candidate needs a board that does not
converge in one iteration, and **no such board exists in this corpus**.

---

## What the owner needs to review

> **Reviewed 2026-08-24. Everything in this section is answered**, and the answers
> — with what changed between draft and milestone and why — are in
> [`m19-review.md`](m19-review.md). The draft became
> [`m19-incremental-geometry.md`](../milestones/m19-incremental-geometry.md) and
> [`m20-placement-quality.md`](../milestones/m20-placement-quality.md). This section
> is left as the chain wrote it, because what the chain handed over is part of its
> record.

**The deliverable of this chain is a decision, not a merge.**
`docs/milestones/m19-DRAFT.md` is a draft and is marked as one in its filename, its
title and its first paragraph. It proposes, in order:
**M19a** vectorise the point-location tail (−10 % corpus routing, all eleven hashes
byte-identical), **M19b** bound the private repair field (−25 % further), **M19c** an
incremental free-space mesh (−30 % further, **conditional**), **M19d** re-fit the
extrapolation and see whether the exponents finally move.

Five decisions, and the first is the one that matters:

1. **Is M19c in or out?** It is the only item in this project's history that would
   partially reverse an ADR and put a **hand-owned geometric predicate into the
   router** — the exact failure mode that killed the gEDA toporouter this project
   wrote an autopsy of. The survey recommends gating it on M19a's and M19b's measured
   results rather than deciding now. The measurement that makes it arguable at all
   (137 rebuilds for a median of two changed obstacles) comes with two caveats a
   candidate must survive: the obstacle sequence is **not monotone**, so
   insertion-only incrementality is insufficient, and the geometry differs per rule
   pair, so it is six maintained structures per layer rather than one.
2. **Does the congestion stress board come first?** Every §2 candidate is blocked on
   it and it is already a graduation condition. If it goes first, M19 shrinks to
   M19a/M19b.
3. **Does the `pcie-sata` fab round gate this?** M19a is hash-preserving by its own
   acceptance criterion and is arguably exempt; M19b and M19c are not.
4. **Does C3 survive its re-pricing?** ~3.4 % copper for a +30 % runtime budget, now
   measured from a primary source instead of estimated from a secondary one.
5. **Is a second attempt worth making on the three closed sources?** Only Lu's 1991
   thesis would change M19c's design, and only marginally.

Three smaller items M17 left open, none of which blocked M18:

- `ROUTER_STAGES` gained `reclaim` and `route all --json` gained
  `routing.reclaimed` — deliberate **public interface additions** that want
  confirming as permanent.
- `docs/images/*` are stale by four vias on the flagship board. Left alone:
  regenerating them is large binary churn for an invisible difference, and when to
  spend it is the owner's call.
- **The capacity arbiter has no real-board evidence.** It is built and unit-tested
  and the corpus never gave it a span to reject. If a denser example is ever added,
  it is the first thing to re-measure.

## Verification, by the orchestrator

| Check | Result |
|---|---|
| `pytest -q` | exit 0 — 1 332 tests, 2 `AIPCB_FULL_CORPUS` skips |
| `ruff check .` | clean |
| `mypy --strict src` | clean, 96 source files |
| `bench --compare` vs the M16 baseline | exit 0, no regressions; every landed candidate inside its stated budget |
| E2 on `examples/pcie-sata` | `route-doubles-back` absent from a CLI route run here; guard retained and inverted |
| M18 code diff | empty over `src/`, `tests/`, `examples/` |
| `funnel.py::tighten` = 0.13 % | reproduced from an independently written profile script |

All six commits are pushed to `origin/master`.

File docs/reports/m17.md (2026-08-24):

# M17 — router improvements, part 2: the measured candidates

M16 built the instrument and deliberately spent nothing on quality. This milestone
spends the evidence that instrument produced, and nothing else: three candidates the
baseline had already ranked, each with a runtime budget stated before it was built,
each landed against `bench --compare` on the whole corpus. No literature, no new
ideas — those are [M18](../roadmap.md#m18--the-literature-survey).

Everything below was measured on 2026-08-24 on the development machine (16 cores,
30 GB RAM, Linux 7.0.0-29-generic), CPython 3.14.4, Shapely 2.1.2 / GEOS 3.13.1,
KiCad 9.0.8 — the same machine and the same versions the M16 baseline was taken on,
which is the only reason the wall-clock comparisons below mean anything. Nothing
else was running during a timing run.

---

## The scoreboard

| Candidate | Budget, stated before | Measured | Verdict |
|---|---|---|---|
| **M17a** via minimisation | runtime ≤ **+10%** on the baseline corpus; a measurable via-count reduction | **+1.7%** (the `reclaim` stage costs 1.038 s against a 61.863 s baseline); **4 vias and 30.285 mm of copper** back, on one board | **landed** |
| **M17b** retrace elimination | the E2 case on `pcie-sata` resolves, no example regresses, ≤ **+5%** runtime | E2 **gone** — `route-doubles-back` no longer fires anywhere; +1.3% on that board (0.450 s of `reclaim` against its 35.87 s M16 routing time, §2.4); every other board byte-identical | **landed** |
| **M17c** stretcher performance | **≥ 25%** stretcher-time reduction on the slowest boards, no quality metric regressing | **−55.5%** on `pcie-sata`, **−52.3%** on `mcu-4layer`, −54.3% corpus-wide, **every board's hash unchanged** | **landed** |
| **M17d** update the extrapolation | publish the new number | 900 connections: **23.7 min → 11.3 min**, exponent 1.72 → 1.70 | **published** |

Nothing was rejected. Three measurements came back *negative* and are recorded as
such — in [the postmortem note's new §"Measured results"](../notes/toporouter-postmortem.md#measured-results-as-the-closure-rule-requires),
per the part-2 closure rule — because a negative result nobody writes down gets
proposed again.

---

## Deviations, stated loudly

| Acceptance clause | What happened |
|---|---|
| *"M17a … the special-cuts-corrected capacity check from M16a is the arbiter"* | **Built, wired in, tested — and it never fired.** Not one span on the corpus was rejected on capacity; length is the binding constraint everywhere here. The arbiter is exercised by two unit tests rather than by the corpus, and §1.4 says so rather than claiming a win it did not earn. |
| *"M17a … Controlled-impedance nets: excluded unless their class's rules still hold after collapse (verify, don't assume)"* | **Excluded by class, and the exclusion is the verification.** Re-deriving M11d's standoff and M11e's audit inside a post-pass is a milestone of its own; skipping the class is the fail-safe reading. The corpus alone cannot verify it — no controlled-impedance connection here is even a candidate — so the test builds the guard one to refuse as well. §1.5. |
| *"M17b … Detect and eliminate self-retracing and trivial out-and-back excursions"* | **One mechanism, not two.** Every retrace in the corpus *is* a via pair returning to its own layer, so the fix for M17a is the fix for M17b. The retrace detector is still wired in — it decides whether a collapse is *reported* as a retrace — and no separate trimmer was written, because there was nothing left for one to trim. §2. |
| *"M17c … the 900-connection ≈ 31 min extrapolation"* | **The old number reproduces as 23.7 min, not 31.** M16's own report says "roughly half an hour" without a figure; re-running its stated method (log-log least squares of `router_seconds` against connections, over the same eleven boards) on the committed baseline gives 1 419 s. §4 states the method so the next re-fit is comparable to this one rather than to a remembered number. |
| *"add finer-grained profiling temporarily, remove before commit"* | **Held.** `cProfile` was driven from a scratch script outside the repository; nothing under `src/` gained a timer. `route/timing.py` is unchanged; the one new stage boundary (`reclaim`) is a pipeline stage in `plan.py`, not an instrument inside one. |
| *"rejection documented like the evolution candidate"* (the M18 brief) | **No such candidate exists in this repository.** Nothing in `docs/roadmap.md`, `docs/decisions/` or `docs/notes/` records an "evolution" candidate, rejected or otherwise. The instruction's intent — write the rejection down with its reason so it is not relitigated — is discharged by pointing at the pattern that *does* exist: the roadmap's "Rejected, not deferred" entry on external autorouters, which names the three properties they break. |
| *"byte-stable goldens (or updated with the diff explained)"* | **One board moved and no golden file did.** `examples/pcie-sata`'s board hash changes because four vias and 30 mm of copper came off it; the diff is explained in §1.2 and §2. The other ten boards are byte-identical to M16. |

---

## 1. M17a — the vias the finished board did not need

### 1.1 What was built, and why it is one thing rather than two

`src/aipcb/route/tidy.py`, a post-pass over the routed board, running after
tightening and before the escape settling and the hole merging (both of those reason
about which vias are load bearing, so they should reason about the ones this leaves).

The unit of work is a **span**: legs *i* through *j* of one connection with the same
layer at both ends and vias in between. If that span tightens as a single leg on that
layer, the vias in it were bought and not used. Two shapes of candidate are offered:

* a span in the middle of a connection — the route left a layer and came back;
* the **whole connection**, once per copper layer both its pads can be reached on —
  because a connection whose two pads share a layer never *had* to change layer at
  all. (This is the complement of the baseline's `via_lower_bound`, which counts the
  connections where no such layer exists.)

A span is collapsed only when it is **strictly better on both axes**: at least one
via fewer, and not one micron more copper. There is no threshold to tune and no way
for the pass to make a board worse; the worst case is that nothing moves.

### 1.2 What it found, per board

| Board | spans considered | collapsed | vias removed | copper back | layer changes 16 → 17 | vias 16 → 17 |
|---|---:|---:|---:|---:|---:|---:|
| congestion | 2 | 0 | 0 | — | 1 → 1 | 1 → 1 |
| diff-pair | 0 | 0 | 0 | — | 0 → 0 | 0 → 0 |
| enclosure | 7 | 0 | 0 | — | 7 → 7 | 7 → 7 |
| ldo-supply | 0 | 0 | 0 | — | 0 → 0 | 0 → 0 |
| led-blinker | 1 | 0 | 0 | — | 1 → 1 | 1 → 1 |
| mcu-4layer | 7 | 0 | 0 | — | 5 → 5 | 5 → 5 |
| overconstrained | 0 | 0 | 0 | — | 0 → 0 | 0 → 0 |
| **pcie-sata** | **18** | **2** | **4** | **30.285 mm** | **42 → 38** | **39 → 35** |
| qfn-fanout | 16 | 0 | 0 | — | 30 → 30 | 28 → 28 |
| routing-demo | 0 | 0 | 0 | — | 0 → 0 | 0 → 0 |
| usb-port | 4 | 0 | 0 | — | 4 → 4 | 4 → 4 |
| **total** | **55** | **2** | **4** | **30.285 mm** | **90 → 86** | **85 → 81** |

The two collapses, both on GND:

```
GND U1.17>U1.49 gave back a retrace, 2 vias and 17.116 mm of copper on F.Cu
GND U1.49>U1.42 gave back 2 vias and 13.169 mm of copper on F.Cu
```

Corpus copper: **3 927.435 mm → 3 897.150 mm** (−0.77%). Every board except
`pcie-sata` is byte-identical.

### 1.3 The finding that matters more than the four vias

The baseline's headline was *37 of 90 layer changes were made where no corridor was
half full*, and the roadmap flagged in advance that this was a proxy: half capacity
is a stated convention, and "no pressure anywhere on the connection" is not "no
pressure at the via". **M17a is the sharpening the roadmap asked for, and the proxy
was overstating the opportunity by an order of magnitude.**

Of the 55 candidate spans, 53 are rejected and the reasons are geometry rather than
policy:

| Why a span was rejected | Count |
|---|---:|
| the single-layer route exists and is **longer** — the via bought something | 21 |
| the free space on the target layer is **split in two**: there is no on-layer route at any price | 32 |
| **capacity** — the collapsed leg would over-subscribe a cut | **0** |

So the honest statement about this router's vias is not "a third of them are waste".
It is: **four of ninety are, and the rest are load bearing**, tested against the
geometry rather than against a congestion proxy. That number is also the most useful
thing this milestone can hand [C3, the detour pass](../notes/toporouter-postmortem.md#c3-a-detour-pass--rejected-at-m19),
whose expected yield was 7–16% less copper on historical boards.

### 1.4 The capacity arbiter, and the fact that it never fired

M16a implemented special cuts — the second diagonal of every convex adjacent triangle
pair — and ADR 0014 Decision 2 deliberately left them out of the router's cost model.
This pass runs downstream of every routing decision, so it can have the tighter cut
set for free, and it does: the occupancy it reasons about is built by charging every
finished leg to **both** cut families, and a collapse is refused when it would leave
a cut both fuller than it is now and past what its width carries.

The test is deliberately *relative* rather than absolute. A corridor already
over-subscribed on a built board is the shared approximate field disagreeing with the
exact per-net stretcher that laid the copper — `pcie-sata` reports 43 such cuts while
being DRC-clean and crossing-free — so demanding absolute headroom would refuse every
collapse on precisely the boards that have vias to give back.

**And on this corpus it refused nothing.** Length rejected 21 spans, geometry 32,
capacity 0. The arbiter is exercised by
`TestViaReclaim::test_a_swap_that_would_over_subscribe_a_cut_is_refused` and its
positive twin — a synthetic one-layer field whose cuts are given a third of a
millimetre of capacity — rather than by any real board. That is a gap in the
*evidence*, not in the code, and it is stated here rather than left to be inferred
from a green suite.

### 1.5 Controlled impedance: excluded, and the exclusion is tested

The milestone says *excluded unless their class's rules still hold after collapse
(verify, don't assume — a via removal changes the geometry M11e audited)*. The
fail-safe reading is taken: a connection is skipped when its net class declares a
differential impedance, or when any of its legs is a coupled pair run. Re-deriving
M11d's standoff rule and M11e's audit inside a post-pass is a milestone of its own,
and a pass that got it subtly wrong would move copper the SI report has already
characterised.

`test_a_controlled_impedance_net_is_left_alone` routes `pcie-sata` for real, collects
every net whose class returns `controlled_impedance`, asserts the set is non-empty —
so the test cannot pass vacuously — and asserts no collapse touched any of them.

**And that half of the test passes for the wrong reason, which is worth saying.** On
this corpus the class guard is never *reached*: every controlled-impedance connection
on `pcie-sata` carries either three coupled legs and no via of its own, or one via and
no legs at all — the holes belong to the declared pair transition (M11c), which is
pattern-generated copper this pass does not look at. `skipped_controlled` is therefore
**0** on every example. So the test also builds the guard a candidate it has to
refuse: a synthetic connection on a controlled-impedance net with a 0.02 mm excursion
to B.Cu and straight back on open board, which any ordinary net would give up
instantly. The guard refuses it, and its two vias are still there afterwards.

### 1.6 Determinism, order stability, idempotence

* **Deterministic.** Connections are visited in canonical order (net, then the two
  endpoint names), spans left to right, and every decision is arithmetic over
  geometry that is already fixed. `test_routing_is_byte_stable` and
  `test_stretching_is_deterministic` pass unchanged.
* **Idempotent.** `test_the_via_pass_is_idempotent` routes `pcie-sata`, rebuilds the
  field and the obstacle set, and runs the pass a second time over the connections it
  already collapsed: **zero collapses, zero vias**. Asserted rather than argued,
  because the pass mutates what it is given, so convergence is a property of the code
  and not of the shape of the problem.
* **The pads it re-tightens against are recorded, not guessed.** `RoutedConnection`
  gained an `open_pads` field. A route normally treats even its own net's other pads
  as things to go round; a connection the repair pass rescued was given every pad of
  its own net, because running through one beats not connecting at all. Guessing the
  strict set made eight spans on `pcie-sata` report "the free area is split in two"
  for a route the board is carrying straight through it. With the real set recorded,
  those eight resolve into six honest "longer" answers and two real splits.

---

## 2. M17b — the retrace, and the case that was its acceptance test

### 2.1 The defect, restated

M16b's E2 guard was expected to find nothing on the corpus — "which is the point",
said the note — and found this on `examples/pcie-sata`: GND's `U1.17>U1.49`, joining
two pads 3.519 mm apart, laid **20.635 mm** of copper in three legs.

```
leg 0  F.Cu   9.833 mm   U1.17            -> via#0
leg 1  B.Cu   0.555 mm   via#0            -> via#1
leg 2  F.Cu  10.247 mm   via#1            -> U1.49
```

Legs 0 and 2 run back through the same vertices in reverse. The B.Cu excursion is
half a millimetre. Roughly eight millimetres of copper and two vias buy nothing at
all.

### 2.2 The fix, and why it is not a separate mechanism

A retrace between two legs on one layer *is* a span returning to its own layer. There
is no other way for one connection's copper to meet itself: a single funnel output is
simple by construction, so the only way two pieces of one connection can coincide is
for the route to have left the layer and come back. Every `legs-meet` finding is
therefore a candidate for §1's collapse, and the collapse is what removes it.

So M17b is not a second pass. It is the same pass, plus the M16b detector used as an
*input*: `self_crossings` runs before anything moves, and a span whose layer it names
is reported as a retrace rather than merely as a via nobody needed. That is how the
diagnostic above knows to say "gave back a retrace, 2 vias and 17.116 mm".

**Result on the acceptance case:** `U1.17>U1.49` is now one F.Cu leg of **3.519 mm**
— which is the straight line between the two pads, so there is nothing left to take.
`done.routed.self_crossings` is empty, `route-doubles-back` does not fire on any
example, and the connection is 17.116 mm shorter with two fewer vias.

### 2.3 The guard stays, inverted rather than deleted

* `TestSelfCrossingInvariant::test_the_corpus_carries_exactly_one_known_doubling`
  became `test_the_corpus_carries_no_doubling`. It still routes `pcie-sata` for real,
  and it now asserts the count is **zero** and that no `route-doubles-back`
  diagnostic was emitted. A fix with no guard on it is a fix until somebody changes
  the cost model.
* `tests/test_check_loop.py`'s `KNOWN_ISSUES` **lost** `route-doubles-back` for
  `pcie-sata`. It is removed rather than silenced, and the comment in its place says
  what happened, so the entry cannot be re-added by habit.
* The seven unit tests that pin what the detector considers a finding are untouched.

### 2.4 Budget

The whole `reclaim` stage on `pcie-sata` is **0.450 s** against that board's M16
routing time of 35.87 s: **+1.3%**, against a budget of +5%. No other board's metrics
moved at all, so nothing regressed anywhere.

---

## 3. M17c — where 83–94% of the time lived, and where it actually was

### 3.1 The profile, and the surprise in it

The baseline said tightening dominates: 94% of `pcie-sata`'s routing time in the
`tighten` stage. `cProfile` over one un-instrumented run of that board said something
more specific, and it was not what the stage name implies.

| What | cumulative, of 87 s profiled |
|---|---:|
| `_retry` → `_repair` → `build_field` | **57.5 s** |
| of which `field.py::_via_sites` | **54.7 s** |
| `geometry_for` (free space + CDT, per leg) | 13.9 s |
| `constrained_delaunay_triangles` (247 calls) | 4.4 s |

**Two thirds of the "tightening" time was the field builder, rebuilt from scratch for
each of the sixteen connections the shared field could not place** — and inside it, a
scalar loop. Per candidate via site, per layer, `_via_sites` built a fresh
`shapely.Point`, called `free.covers`, called `triangulation.locate` (which built
another Point and made a Python-level R-tree query), and asked GEOS for
`free.boundary` **again** before measuring a distance to it. On `pcie-sata` that was
1.9 million Point constructions, 1.05 million `covers` calls and 854 000 boundary
derivations.

That is the answer to the milestone's question — *is the stretcher asymptotically
optimal or constant-slow?* — for the part M17c was allowed to touch. It was neither
mysterious nor algorithmic. It was trips across the Python/GEOS boundary.

### 3.2 The three changes

None of them changes an answer; all of them change how many times it is asked.

1. **`_via_sites` is vectorised.** One `shapely.covers` and one `shapely.distance`
   per *layer* over the whole candidate array, against a boundary derived once, plus
   a new `Triangulation.locate_many` that batches the R-tree query for every point at
   once. The tie-break is preserved exactly — candidates are still tried in ascending
   triangle index — so a point on a shared edge still lands where it did.
2. **`inflate` is memoised.** It is a pure function of a hashable polygon and a
   margin, and the router asks for the same answer 45 000 times on `pcie-sata` with
   fewer than a thousand distinct arguments. `lru_cache`, 65 536 entries.
3. **The STRtree over the triangles is built in one call** (`shapely.polygons` on an
   array, not a comprehension of `Polygon(t)`), and **`_realize` builds each layer's
   geometry once per connection instead of once per leg** — a route that goes F.Cu,
   B.Cu, F.Cu was unioning, differencing and triangulating F.Cu's free space twice
   for the same answer.

### 3.3 The measurement

`tighten` seconds, M16 baseline against M17c alone (i.e. before M17a/b landed, so
that the two effects are not mixed):

| Board | M16 | M17c | Δ |
|---|---:|---:|---:|
| **pcie-sata** | 33.883 | **15.083** | **−55.5%** |
| **mcu-4layer** | 8.553 | **4.080** | **−52.3%** |
| enclosure | 4.079 | 1.870 | −54.2% |
| qfn-fanout | 5.013 | 2.459 | −50.9% |
| usb-port | 2.341 | 1.175 | −49.8% |
| overconstrained | 0.141 | 0.067 | −52.5% |
| congestion | 0.099 | 0.066 | −33.5% |
| routing-demo | 0.152 | 0.129 | −15.3% |
| led-blinker | 0.246 | 0.210 | −14.8% |
| diff-pair | 0.217 | 0.185 | −14.7% |
| ldo-supply | 0.188 | 0.163 | −13.0% |
| **corpus `router_seconds`** | **61.863** | **28.290** | **−54.3%** |

The two slowest boards are at −55.5% and −52.3% against a target of −25%. The small
boards move least, which is the expected shape: they have no repairs, so they never
paid for the second, third and sixteenth field.

**And the quality side of the acceptance condition is the strong half:** at this
point **all eleven board hashes were byte-identical to the M16 baseline** — same
copper, same vias, same completion, same crossings, same over-subscription counts.
`bench --compare` reported improvements on runtime and nothing else. A performance
change that moves a single coordinate is a quality change wearing a disguise; this
one moved none.

### 3.4 What was *not* done, and what it hands M18

No algorithm was replaced, as the milestone required. The profile does not scream for
one — it screamed for a batch call, and got it — but it does leave a question the
constant factors have now uncovered:

> With the per-point Shapely traffic gone, the largest single remaining cost is
> `geometry_for`: union the obstacles, difference them from the board, triangulate
> the result — **once per connection per layer**, from scratch, on a free space that
> differs from the previous connection's by one route's worth of copper. Nothing in
> this project knows whether that is avoidable. An incremental CDT would answer it;
> so might a different decomposition.

That is written into [the M18 brief](../roadmap.md#m18--the-literature-survey) as the
question the tightening-theory reading has to answer.

---

## 4. M17d — the extrapolation, re-fitted

Method, stated so the next re-fit is comparable to this one and not to a remembered
number: **log-log least squares of `router_seconds` against connections attempted,
over all eleven bundled examples.** The same three models M16 reported:

| Model | M16 exponent | M16 R² | M17 exponent | M17 R² |
|---|---:|---:|---:|---:|
| routing seconds vs **connections** | 1.72 | 0.94 | **1.70** | **0.94** |
| routing seconds vs total cuts | 2.61 | 0.82 | 2.57 | 0.81 |
| routing seconds vs **connections × cuts** | **1.12** | **0.97** | **1.10** | **0.96** |

**The exponents did not move, and that is the finding.** M17c harvested constant
factors and left the shape of the curve exactly where it was — routing cost is still
close to linear in connections times triangulation size, which is still what "tighten
each connection against a triangulation of the whole board" predicts. Whether that
shape is the right one is M18's question, and this table is the evidence that M17
did not answer it.

**The new capability-ladder number.** Extrapolating the connection fit past the
measured range — and it is an extrapolation, from eleven boards spanning 4 to 90
connections —

> a 900-connection board would take roughly **11.3 minutes** to route
> (675 s), where the same method on the M16 baseline gives **23.7 minutes** (1 419 s).

Both figures are computed from committed results files by the script above. The
extrapolation's own precision is worth naming: three full corpus runs of this code on
this machine put the same number between 675 and 691 s, so it is a *scale*, not a
stopwatch reading — an eleven-to-twelve minute board, not an eleven-point-three
minute one.

One caveat, recorded because a number that quietly changes meaning is worse than a
wrong one: **the M17 milestone brief cites the old figure as "≈ 31 min" and the M16
report says "roughly half an hour"; neither is reproducible from the committed
baseline by the method above, which gives 23.7 min.** The honest comparison is
therefore 23.7 → 11.3 min, both computed here, both from committed results files.
The roadmap's graduation section cites no figure and needed no edit.

---

## 5. The baseline moves, deliberately

`bench/results/baseline.json` is refreshed at this milestone's commit, per
[`bench/results/README.md`](../../bench/results/README.md)'s rule that the baseline
moves deliberately and the report says why the new numbers are better. The old file
stays identifiable in git history at commit `6b6a963` ("bench: the baseline, measured
at M16's own commit"), and this report carries every M16 figure it is compared
against.

**Why the new numbers are better**, metric by metric:

| Metric | M16 | M17 | Why |
|---|---:|---:|---|
| corpus copper | 3 927.435 mm | 3 897.150 mm | 30.285 mm of retraced and doubled copper came off `pcie-sata` (§1.2) |
| vias | 85 | 81 | four holes the finished board did not need (§1.2) |
| layer changes | 90 | 86 | same four |
| self-crossings | 1 | **0** | the E2 finding is fixed (§2) |
| corpus `router_seconds` | 61.863 | 29.476 | §3 |
| completion | 275/278 | 275/278 | unchanged — `overconstrained` still routes one of four by design |
| over-subscribed cuts | 58 | 56 | `pcie-sata` 43 → 41: two fewer routes crossing the corridors the collapse left |
| board hashes | — | ten of eleven unchanged | only `pcie-sata` moved, and §1.2 says by exactly what |

---

## 6. Verification

| | |
|---|---|
| Suite | **1 332 tests: 1 330 passed, 2 skipped, 0 failed.** The two skips are the `AIPCB_FULL_CORPUS` opt-in. Five are new — `TestViaReclaim` — and one existing assertion is inverted rather than deleted (§2.3). |
| `ruff check .` | clean |
| `mypy --strict src` | clean, 96 source files |
| Byte stability | `test_routing_is_byte_stable`, `test_stretching_is_deterministic` pass |
| DRC | `test_routed_board_has_no_drc_violations` passes on every example |
| Golden files | **none moved** |
| Invariants | `check_no_crossings` and `check_no_self_crossings` both empty on every example — the second for the first time |
| `bench --compare bench/results/baseline.json` | improvements only; one reported *change*, `pcie-sata`'s board hash, explained in §1.2 |

Two interface additions, both deliberate rather than incidental:

* `route all --json` gains `routing.reclaimed` — what the via pass took back, what it
  looked at, and what it rejected and why. `TestBetaNotice::ROUTING_KEYS` was extended
  on purpose, which is the established pattern for a schema addition here.
* `aipcb bench` gains a `reclaim` stage in `ROUTER_STAGES`, so the pass's cost is a
  column rather than hidden inside `tighten`. A results file written before this
  milestone simply has no `reclaim` key; `render_stages` derives its columns from the
  data, so old files still render.

---

## 7. What this milestone did not do

**No literature.** The guardrail was explicit and it held: every technique here comes
from a number the M16 baseline already measured. The reading list is
[M18](../roadmap.md#m18--the-literature-survey), which is documentation only.

**No algorithm replacement in the stretcher.** M17c is engineering — batch calls, a
memo table, one duplicated computation removed. The question of whether the funnel
per connection against a whole-board triangulation is the right *shape* is untouched
and is now the first thing M18 has to answer, with §3.4's profile as its input.

**No regenerated README images.** `tools/make_images.py` renders the README's
pipeline pictures from `examples/pcie-sata`, and that board moved — so
`docs/images/04-routed.png` and `docs/images/_check.json` show 42 vias and
1 108.092 mm where the board now has 38 and 1 077.807. They are left alone on
purpose: regenerating means a 3D render and four PNG rebuilds, which is a large
binary diff for a four-via difference nobody can see at README scale, and the images
document the *pipeline* rather than a measurement. The next milestone that changes
what the board looks like visibly should run the tool.

**No detour pass.** C3 keeps its general case and has lost its named customer. The 53
rejected spans in §1.3 are the first real evidence about how much copper is left on
this corpus for a more ambitious post-pass to find, and the answer looks like "less
than the historical 7–16% suggests" — which is worth knowing before spending 30% of
the runtime budget to find out.

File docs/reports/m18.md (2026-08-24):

# M18 — the literature survey

A research-only milestone. **No code moved**: nothing under `src/`, `tests/` or
`examples/` was touched, and `git diff` over those trees across this milestone's
commits is empty.

Deliverables: [`docs/notes/routing-literature.md`](../notes/routing-literature.md)
(the survey), `docs/milestones/m19-DRAFT.md` (a drafted proposal, for the owner's
review, **not** an approved milestone), the roadmap's M18 entry closed with the
candidates in, and this report.

> *Since this report was written, the draft was reviewed and approved. It is now
> [`m19-incremental-geometry.md`](../milestones/m19-incremental-geometry.md) plus
> [`m20-placement-quality.md`](../milestones/m20-placement-quality.md), and
> [`m19-review.md`](m19-review.md) records what changed. §4 below is left as it was
> written — it is the question this milestone asked, and the answers are in the
> review.*

Everything measured below was measured on 2026-08-24 at HEAD `4a41546`, on the
development machine (16 cores, 30 GB RAM, Linux 7.0.0-29-generic), CPython 3.14.4,
Shapely 2.1.2 / GEOS 3.13.1 — the same machine the M16 and M17 baselines were taken
on. Profiling was driven from scratch scripts **outside** the repository, per M17's
precedent; no timer went into `src/`.

---

## 1. What was learned

### 1.1 The headline: the question three milestones have been asking was aimed at the wrong function

M16 measured that 83–94 % of routing time is in the `tighten` stage. Everything
since has reasoned from it — M17c's whole brief, and M18's own. The stage figure is
correct. The inference drawn from it was not.

> **`funnel.py::tighten` costs 0.039 profiled seconds of a 30-second route.**
> 0.13 %. The whole sketch-to-geometry path — `portal_path`, `reduce_crossings`,
> `orient_portals`, `tighten`, `_dedupe`, `stretch_guided` — is under one second.

The `tighten` *stage* is 15.035 s of `pcie-sata`'s 16.196 s of routing, and almost
none of it is tightening. It is building, and then discarding, the free space, the
triangulation and the via sites that tightening is performed against.

### 1.2 The answer to M17c's open question

The brief asked for (a) algorithm replacement with a named algorithm, (b) an
incremental or lazy re-tightening architecture, or (c) a compiled kernel. The answer
is **(b), with a correction to its noun, and with the order of work inverted from
what the framing implied.**

**(a) is rejected, on measurement rather than on argument.** Hershberger &
Snoeyink's paper — obtained in full text from the author's own copy — proves
Theorem 3.2: the Euclidean shortest path homotopic to a given path α is computable
in *O*(*C*<sub>α</sub> + Δ<sub>α</sub>) time, linear in the sleeve. Bespamyatnikh
(2003, also read in full) records that bound as worst-case optimal. That is exactly
what `funnel.py` implements and claims. There is no better algorithm, and §1.1 says
there would be nothing to win if there were.

**(c) is rejected as posed — and the profile says constant-factor work is not
exhausted after all.** "Compile the current algorithm" is the wrong shape: the
largest single cost is `constrained_delaunay_triangles` at 4.30 s, which is GEOS,
which is C already. But the profile found something M17c missed. `locate_many`
batches the R-tree query and then runs a **scalar Python loop**: `_inside` executes
**3 140 252 times** and `_sign` **9 426 354 times** on one board. M17c vectorised
everything around this function and stopped one function short of it.

**(b) is accepted as the structural direction, and four independent sources agree
on it.** Hershberger & Snoeyink's Theorem 3.4 (the funnel can be *maintained*
on-line in the same bound); Shewchuk & Brown 2015 (segment insertion in expected
time linear in the edges crossed); Kallmann, Bieri & Thalmann 2003 (fully dynamic
CDT with insertion *and* removal, measured at roughly 540:1 rebuild-to-update on
their largest data set); and **Dayan's own thesis, §2.2.1**, which says SURF
maintained a per-layer mesh with an incremental CDT, and says why.

**But "incremental re-tightening" is the wrong noun.** Nothing needs to re-tighten;
tightening is free. What needs to stop being rebuilt is the free space, its
triangulation and the via sites — and the largest single cumulative cost in the
profile is not `geometry_for` at all. It is `_repair`, at **16.30 s for sixteen
connections**, building a whole-board field so that one connection can find a
corridor between two pads millimetres apart. That is ordinary engineering with no
new geometry, and it comes before the incremental mesh.

### 1.3 Dayan's 1997 thesis, obtained

The toporouter postmortem's largest gap is closed. **161 pages, in full** — from an
Internet Archive snapshot dated 2017-07-18 of a Semantic Scholar PDF the live site
no longer serves. Every live route is still shut: ProQuest wants an institution,
Semantic Scholar returns an empty page, Google Books has metadata only. The second
attempt succeeded by archaeology rather than by access, and the copy could disappear
again.

Five findings, four of which change something:

1. **The shortest-path algorithm is *O*((*T*+*S*)² log(*T*+*S*)), and the one that
   shipped is not shortest.** SURF used a reduced graph at
   *O*((*T*+*S*) log(*T*+*S*)) that "is guaranteed to find a planar path if one
   exists but the path found may be not a shortest path". This sharpens rather than
   contradicts the postmortem's reading of the proof-versus-heuristic gap.
2. **SURF maintained an incremental CDT per layer** (§2.2.1), explicitly "to improve
   the efficiency of rubber-band updating". This is M17c's open question, answered
   by the original system, in one sentence, in 1997.
3. **C3, the detour pass, is re-priced downward from a primary source.** The roadmap
   cited Blake's 7–16 % on two boards. Dayan measures the same mechanism (his ROAR
   optimiser) on ten two-layer bins and 427 branches: detour **8.84 % → 5.18 %**,
   "the wire length was reduced by about 3.4 %". Combined with M17's finding that 53
   of 55 collapsible spans on this corpus were unimprovable, 3.4 % for a +30 %
   runtime budget no longer looks like a good trade — and that is now the owner's
   call rather than a silent assumption.
4. **C3 gains a structural argument it did not have.** §6.1's *triangle problem*:
   three symmetrical branches whose optimal embedding cannot be produced by routing
   one at a time along shortest paths, **in any order**. A post-pass is therefore
   necessary rather than merely nice.
5. **C5, pairwise-conflict ordering, loses further ground.** Dayan formulates the
   identical mechanism, claims for it only that it beats *shortest-first* (which
   aipcb does not do), and leaves its complexity an open question. And the triangle
   problem says ordering cannot fix what ordering cannot fix.
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

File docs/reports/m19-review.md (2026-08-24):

# M19 review — what the owner changed between draft and milestone

M18's second deliverable was a *draft* milestone with five open decisions at the
bottom, and the [M17→M18 chain](chain-m17-m18.md) halted there by design: the
deliverable of that chain was a decision, not a merge. This is the record of the
review. **No implementation code moved in this session** — `git diff` over `src/`,
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

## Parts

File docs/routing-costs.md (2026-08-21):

# What the router is trying to minimise

Every choice the multilayer router makes comes out of one number: the cost of a
path. This document lists the terms that number is made of, what each one defaults
to, and why.

All of them are in **millimetres of track**, because that is the only unit the
search actually has. "A via costs 5" means "a via is worth taking if it saves more
than 5 mm of copper". Reading them that way is what makes them arguable rather than
magic.

They live in [`aipcb/route/costs.py`](../src/aipcb/route/costs.py) as one frozen
dataclass, `CostModel`, so a board that wants different numbers overrides fields
rather than editing the search.

## The cost of a move

```
cost = length
     + via_cost × n_vias                 # a layer change
     + layer_penalty(layer, net class)   # ∞ for a plane
     + congestion(cut)                   # → very large as a cut fills up
     + direction_penalty                 # soft H/V preference from the stackup
```

The search is an A\* over one graph spanning every signal layer, joined at candidate
via sites; the details are in [ADR 0007](decisions/0007-multilayer.md) and the code
is [`aipcb/route/graph.py`](../src/aipcb/route/graph.py).

## The parameters

| Parameter | Default | What it means |
|---|---|---|
| `via_cost_mm` | 5.0 | What one via is worth in millimetres of track. |
| `non_preferred_layer_mm` | 8.0 | Cost of using a layer the net class did not ask for. |
| `plane_layer_mm` | ∞ | Cost of routing on a layer the stackup gave over to a plane. |
| `direction_penalty_mm_per_mm` | 0.25 | Extra cost per millimetre travelled against a layer's grain. |
| `congestion_present` | 0.8 | How steeply the *first* pass charges for sharing a corridor. |
| `congestion_growth` | 1.9 | How much that rises each negotiation pass. |
| `congestion_history` | 4.0 mm | Added to a cut's price for each pass it stays over-subscribed. |
| `congestion_cap` | 1e6 | The price of a cut that is already full. |
| `rip_up_protected` | ×12 | How much harder a `rip_up: protected` net is to move. |
| `rip_up_never` | ×10⁴ | The same for `rip_up: never`. |
| `iterations` | 12 | Negotiation passes before giving up. |

### `via_cost_mm` — 5.0

A via is a drilled hole, an impedance discontinuity, a stub, and a blocked spot on
every layer it passes through. The brief's range is 3–10 mm. Five sits where a via
is worth taking to escape a fine-pitch part or to cross a busy corridor, and not to
shave a corner off a short run — which is exactly the behaviour the bundled examples
show: `ldo-supply` takes none, `led-blinker` takes one to escape the DIP, and
`usb-port` takes four to get out of the Micro-B's fan-out.

### `non_preferred_layer_mm` — 8.0

Large enough that a class saying `prefer_layers: [F.Cu]` stays on F.Cu wherever
F.Cu works. Small enough that "stay on F.Cu" never becomes "fail rather than move",
which is what an infinite penalty would mean and is almost never what a designer
wants. A class that really does mean *never* says `layer_forbid`.

### `plane_layer_mm` — infinite

Not tuned: chosen. A plane with a signal cut through it is not a plane, and the
reference it gives every other layer is the reason the stackup has one. A net class
opts in by naming the layer in `prefer_layers`, which takes the layer out of the
plane set *for that class* rather than discounting the penalty — so opting in is a
decision, not an accident of arithmetic.

### `direction_penalty_mm_per_mm` — 0.25

Preferred directions (`stackup.preferred_direction`) make a dense board tractable by
keeping crossings on separate layers. A router that obeys them absolutely produces
staircases where a diagonal would do, so the hint is soft: going the wrong way costs
25% more per millimetre, charged on the component of the move that runs across the
grain. A diagonal therefore pays about half of what a right-angle turn does. Layers
the stackup says nothing about pay nothing.

### The congestion terms

These are PathFinder's, and they are the reason the router converges at all.

`congestion` is charged per cut crossed, as a multiplier on the length of the move
into it:

```
occupancy = (already_used + this_net_demand) / capacity
congestion = step_length × present × occupancy       (occupancy ≤ 1)
           = congestion_cap                          (occupancy > 1)
```

with `history` added on top. Three consequences worth knowing:

* **Narrow corridors cost more even when empty.** A cut that barely fits one track
  has occupancy near 1 from the first net that crosses it; a wide one has occupancy
  near zero. So the search spends open space first and saves tight gaps for the
  routes that have no alternative — which is M7's measured `--congestion` behaviour,
  arriving here as a consequence rather than as a separate term.
* **`present` rises each pass** (`congestion_present × congestion_growth^pass`), so
  early passes let nets find their natural paths and later ones force the argument.
* **`history` is permanent.** It is what resolves the second-order congestion two
  nets fall into when each looks free only because the other has just left. Four
  millimetres per pass is comparable to a via, so a corridor that stays contested
  becomes worth going round or under — but only after `present` has had its chance.

`congestion_cap` is large but finite on purpose: the whole point of negotiation is
that a net may sit on a contested cut *for now* and be persuaded off it later.

### The rip-up multipliers

`rip_up` is a net class field. On each over-subscribed cut the net that is hardest
to rip up keeps its place and the rest re-route, where "hardest" is
`priority × multiplier`:

| `rip_up` | multiplier | effect |
|---|---|---|
| `normal` | ×1 | Moves like anything else of its priority. |
| `protected` | ×12 | Disturbed only when the alternative is failing to route something else — about a dozen ordinary nets' worth of resistance. |
| `never` | ×10⁴ | Ripped only as the last thing tried before declaring the board unroutable. |

`never` is not infinite. Reporting "this board cannot be routed" without having
tried is worse than trying; what matters is that the failure report *names* the
`never` net that was holding the corridor, which it does.

### `iterations` — 12

PathFinder converges on realistic boards in far fewer. The limit exists so that a
genuinely over-constrained board fails in seconds with a report rather than
spinning. The negotiation also stops early when three passes in a row fail to reduce
the number of over-subscribed cuts, because a board that has not improved in three
passes is over-subscribed rather than unlucky. Every pass is logged, and
`aipcb route all --json` reports how many ran and whether they converged.

## Priority, and where it comes from

`priority` is a net class field, 0–100. It decides the order nets are routed in and
who keeps a contested corridor. When a class does not state one it gets a default
from its name:

| class | default priority |
|---|---|
| `diff_pair`, `usb` | 80 |
| `high_speed`, `clock` | 75 |
| `analog` | 65 |
| `power` | 60 |
| `ground` | 55 |
| `signal`, anything else | 50 |
| any differential pair, whatever its class | 80 |

These are M7's measured ordering re-expressed as priorities, so the heuristic and
the source field are one mechanism rather than two.

Within a priority, nets are ordered by **difficulty**: the straight-line length
times the demand, divided by the narrowest cut a route leaving either pad has to get
through. A pair escaping a 0.65 mm-pitch receptacle scores enormously and chooses
first; a ground hop between two capacitors in open board scores near nothing and
goes last.

## Two knobs on the command line

```bash
aipcb route all design.yaml --congestion 1.0 --layers F.Cu,B.Cu
```

`--congestion` scales the whole congestion term: `0` routes purely for length and
via cost, ignoring how full a corridor is. It is worth trying on a board that fails
to converge, to see whether congestion or geometry is the problem. `--layers` limits
the run to named copper layers, which is how you ask "would this board route on one
layer?" — and on `examples/congestion` the answer is no.

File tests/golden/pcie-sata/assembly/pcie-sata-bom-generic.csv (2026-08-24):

Designators | Quantity | Value | Footprint | Package | Assembly | Manufacturer | MPN | Supplier Refs | Description
C1,C5,C6 | 3 | 100n | Capacitor_SMD:C_0603_1608Metric | C_0603_1608Metric | smt |  |  |  | 100 nF X7R ceramic capacitor, 0603, 50 V
C2,C3 | 2 | 100n | Capacitor_SMD:C_0402_1005Metric | C_0402_1005Metric | smt |  |  |  | 100 nF X7R ceramic capacitor, 0402, 16 V -- the AC-coupling part for a PCIe transmit pair, small enough that the pair barely notices it.
C4 | 1 | 10u | Capacitor_SMD:C_0805_2012Metric | C_0805_2012Metric | smt |  |  |  | 10 uF X5R ceramic capacitor, 0805, 16 V
J2,J3,J4,J5 | 4 | SATA data | Connector_JST:JST_GH_SM07B-GHS-TB_1x07-1MP_P1.25mm_Horizontal | JST_GH_SM07B-GHS-TB_1x07-1MP_P1.25mm_Horizontal | smt | JST | SM07B-GHS-TB |  | 7-way 1.25 mm side-entry connector standing in for a SATA data receptacle -- same contact count and very nearly the same pitch. Two shell pads, both numbered MP, which is the same shared-pad-number case as a USB receptacle's shield tabs.
U1 | 1 | SATA-CTRL-48 | Package_DFN_QFN:QFN-48-1EP_7x7mm_P0.5mm_EP5.15x5.15mm | QFN-48-1EP_7x7mm_P0.5mm_EP5.15x5.15mm | smt |  |  |  | A PCIe x1 to 4-port SATA bridge controller, ASM1064 class, in a 48-pin QFN with an exposed pad. See the note at the top of this file about the symbol.

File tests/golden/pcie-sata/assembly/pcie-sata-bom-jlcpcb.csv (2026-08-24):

Comment | Designator | Footprint | JLCPCB Part #
100n | C1,C5,C6 | Capacitor_SMD:C_0603_1608Metric
100n | C2,C3 | Capacitor_SMD:C_0402_1005Metric
10u | C4 | Capacitor_SMD:C_0805_2012Metric
SATA data | J2,J3,J4,J5 | Connector_JST:JST_GH_SM07B-GHS-TB_1x07-1MP_P1.25mm_Horizontal
SATA-CTRL-48 | U1 | Package_DFN_QFN:QFN-48-1EP_7x7mm_P0.5mm_EP5.15x5.15mm

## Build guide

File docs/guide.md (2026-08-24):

# The long tour

This was the README until M15, when the front page was cut down to a shop window.
Nothing here was thrown away: this is the full walk through what the tool does,
command by command, with the output it actually produces.

It overlaps [`format.md`](format.md) (which is the *reference* for every key in a
design file) and [`workflows.md`](workflows.md) (which is the *task*-shaped guide).
Read this one if you want a single continuous read-through.

---

## Why

The primary author of this format is an AI agent working in a loop: edit source,
compile, run checks, read structured feedback, fix. That loop needs things a
schematic editor's native format cannot offer.

**Intent is stored, not inferred.** A capacitor is not just a capacitor; it is
`role: decoupling, for: U1` with a `reason:` attached. Nothing has to guess why it
is there — not the placement engine, not the reviewer, not the agent that picks the
design up six months later.

**Feedback is structured and source-referenced.** Every problem comes back as a
diagnostic naming a file, a line, a stable error code, and where possible a fix:

```
examples/usb-port/design.yaml:53:3: error[asymmetric-diff-pair]: net 'USB_DP'
names 'USB_DM' as its differential partner, but 'USB_DM' names USB_DPP
  at: nets.USB_DM.diff_pair
  hint: set `diff_pair: USB_DP` on 'USB_DM'
```

**Output is deterministic.** Every element's UUID is a hash of its path in the
source, never of generation order or time. The same source produces byte-identical
files, so `git diff` shows only what actually changed — and a violation reported by
`kicad-cli` against a UUID maps straight back to the line that owns it. The
guarantee is about **build output**: copper pours are emitted unfilled, and the
fill is a derived artefact regenerated at check and export time by KiCad's own
engine ([the stability policy](format.md#the-stability-policy)).

**Reads can be partial.** `aipcb query` extracts one module, one net class, or a
one-line status per block, so an agent can look at the part of a design it is
working on without paying for the whole thing in context.

**What is checked is separated from what is not.** A net class can state an
impedance and let the stackup derive the trace geometry, and `aipcb check` will
project every controlled-impedance track onto the plane its class declares and
report where the plane under it stops or changes net. That is **rule-based
geometry, not electromagnetic simulation**: it says the return path has somewhere
to go, not that it goes there. A gigabit board that passes every one of those
checks still wants a human and an SI tool before anybody signs it off, and the
report says so in its own output rather than leaving it to be assumed.

## The layer model

| Layer | What it holds | Where it lives |
|---|---|---|
| 1. Semantic schematic | components, nets, intent, hierarchical parameterised modules | `design.yaml`, [`aipcb.model.design`](../src/aipcb/model/design.py) |
| 2. Layout intent | stackup, placement rules, per-class routing rules, routing sketches | `layout:`, [`aipcb.model.layout`](../src/aipcb/model/layout.py) |
| 2. Mechanical | board outline, cutouts, edge clearance, fixed placement, fanout | `board:`, `placement:`, `fanout:`, [`aipcb.model.board`](../src/aipcb/model/board.py) |
| 3. Compiler / sync | elaboration, KiCad emission, check-loop feedback | [`aipcb.elaborate`](../src/aipcb/elaborate.py), `aipcb.kicad` |
| 4. Component database | parts, pinouts, limits, KiCad symbol/footprint bindings | `library/*.yaml`, [`aipcb.model.parts`](../src/aipcb/model/parts.py) |

No layer stores what a lower one can derive. Layer 1 has no coordinates; layer 2
has intent, not geometry.

## Quickstart

Requires **Python 3.12+** and **KiCad 9**. KiCad is the backend, not an optional
extra: compiling a design reads its stock symbol and footprint libraries, and
checking, rendering and exporting shell out to `kicad-cli`. Only `validate`,
`summary`, `query` and `schema` run without it.

> This page said "KiCad 8 or 9 is needed for the check and export commands;
> everything else runs without it" until M15, when running the quickstart in a
> clean container showed that `aipcb build` needs the libraries too. The Python
> floor moved to 3.12 in the same milestone, for a measured reason —
> [ADR 0013](decisions/0013-ci.md) Finding 4.

```bash
git clone <this repo> && cd aipcb
python3 -m venv .venv && .venv/bin/pip install -e '.[dev]'
.venv/bin/aipcb version
```

Validate one of the bundled examples:

```bash
.venv/bin/aipcb validate examples/usb-port/design.yaml
```

```
ok: no problems found
usb-port rev A: 7 components, 7 nets, 20 connections
```

Now break it on purpose — change `diff_pair: USB_DP` to `diff_pair: USB_DPP` under
`nets: USB_DM:` — and run it again. You get a located, coded diagnostic rather than
a stack trace. Add `--json` and you get the same thing in machine-readable form,
which is what the agent loop consumes:

```bash
.venv/bin/aipcb validate examples/usb-port/design.yaml --json
```

### Compiling

```bash
.venv/bin/aipcb build examples/usb-port/design.yaml --out build/
kicad-cli sch erc --severity-all build/usb-port.kicad_sch
kicad-cli pcb drc --severity-all --schematic-parity build/usb-port.kicad_pcb
```

```
Found 0 violations
Found 18 unconnected items
Found 0 schematic parity issues
```

The build writes a `.kicad_sch`, a `.kicad_pcb`, a `.kicad_pro` carrying the net
classes as KiCad design rules, and project-local `sym-lib-table` / `fp-lib-table`
files. Open either file in KiCad and it renders, checks, and plots like any other.

The unconnected items are the ratlines: `aipcb build` stops at footprints and an
outline, and `aipcb route all` is what turns those into copper. Everything else is
clean — in particular *schematic parity*, which is KiCad checking that every
footprint is tied to its symbol and every pad sits on the net the source says it
does.

Footprint placement comes from the design's intent rather than from a layout file.
Components joined by a `group` or `max_distance` constraint, or by a `for:`
reference, are clustered and packed together; the clusters are then shelf-packed
into the board outline. If they do not fit, the diagnostic says what size would:

```
warning[placement-overflow]: the components do not fit inside the board outline:
they need about 33.3 x 35.6 mm, and the outline gives 22.0 x 16.0 mm
```

Connectivity is expressed with net labels on pin stubs rather than routed wires,
and symbols are laid out on a grid grouped by module instance. That is deliberate:
placement is naive, connectivity is exact. The test suite does not take ERC's word
for it either — it exports KiCad's own netlist and asserts it matches the source
net for net, pin for pin.

Rebuild without changing anything and the output is byte-identical, so the file is
not even rewritten.

### The check loop

`aipcb check` builds the design, routes it, runs KiCad's ERC and DRC, and reports
what they found *against the source*:

```bash
.venv/bin/aipcb check examples/usb-port/design.yaml
```

Set an impossible clearance on the `usb` net class and KiCad's complaint comes back
pointing at the line that caused it:

```
examples/usb-port/design.yaml:69:3: error[kicad-clearance]: Clearance violation
(netclass 'usb' clearance 2,5000 mm; actual 0,2500 mm) [pad J1 pad 1, pad J1 pad 2]
  at: components.J1.pins.1
  hint: widen the clearance for this net class under `net_classes:`, or move the
        parts apart with a `keep_apart` constraint
```

The mapping is exact, not heuristic. Every item in a KiCad report carries a UUID,
and every UUID we emit is a hash of a source path, so recovering the owner is a
dictionary lookup — no matching on coordinates, no parsing of description strings.
A test asserts that *every* UUID appearing in a generated file maps back, so the
index cannot silently fall behind the emitters.

A UUID that does not map is reported too, and says what it means: the board
contains something `aipcb` did not generate, so a human added it in KiCad and that
is where the fix belongs. That case becomes load-bearing in M6.

Routing before checking is deliberate: a DRC pass over a board with no copper on it
has checked almost nothing. Connections the router will not deliver legally are
handed over rather than squeezed in, so `--json` carries both a DRC result that means
something and an explicit list of what is not routed. `--no-route` gets the old
behaviour where only the build matters.

### Your edits survive a rebuild

`aipcb build` is incremental. Open the generated board in KiCad, move a connector,
route a pair by hand, pour a zone — then rebuild:

```
info[preserved-edits]: kept manual work from the existing board: 7 hand-placed
footprints; 1 segment, 1 zone
  hint: run `aipcb build --fresh` to regenerate from source instead
```

The rule is one sentence: **the source owns what it declares; everything else
belongs to the person who drew it.** Every generated footprint records a
fingerprint of the source facts that determine it — its part, its connections, its
side, the constraints naming it. If that fingerprint still matches, your position
stands. If the source changed its mind, the source wins and says so:

```
info[placement-regenerated]: 1 footprint moved because the source changed: R1
```

Editing a `reason:` does not count as changing your mind, so improving a comment
never shoves a hand-placed part back onto the grid.

Copper belonging to a net the design no longer has *is* removed, with a warning —
an orphaned track is a short waiting to happen. And a board file that cannot be
parsed is never silently overwritten; it might be hours of somebody's routing.

### Fabrication output

```bash
.venv/bin/aipcb export examples/usb-port/design.yaml --out fab/
```

```
exported 16 files to fab/ (fill (1/1 zones), gerbers, drill, position, bom)
```

Gerbers for every copper and technical layer, Excellon drill files split by plating
with a drill map, a `.gbrjob`, a grouped BOM carrying the descriptions from your
component database, and a placement file. That is the whole path: source → fab data,
with no step that required opening a GUI.

Every coordinate in the package is measured from the board's own bottom-left corner
rather than from a corner of the A4 sheet KiCad happened to put it on. That sounds
like a detail and is not: consumers that parse unsigned coordinates *silently drop*
what lands outside their frame, so a package in page coordinates is not rejected, it
is quietly misread. Two of aipcb's own exports had that shape until M12 read the
files back.

### Simulating the pairs

Rule-based checks say a differential pair *should* be 100 Ω. A field solver says what
it is.

```bash
.venv/bin/aipcb simulate examples/pcie-sata/design.yaml
```

```
simulating pcie-sata into examples/pcie-sata/out/si
  PCIE_TXN+PCIE_TXP        simulated   128.2 s  Zdiff   80.0 ohm  (target 85, -5.8%)
  PCIE_RXN+PCIE_RXP        simulated   220.9 s  Zdiff   72.8 ohm  (target 85, -14.4%)
  REFCLKN+REFCLKP          simulated   473.6 s  Zdiff   49.8 ohm  (target 85, -41.4%)
  ...
```

Those deviations used to be much larger — 66.6, 61.5 and 50.9 ohm on the same three
links — and they were a finding about the *width solver*, not about the router. Both
closed forms aipcb derived a width from modelled a **bare** microstrip, and every one
of these pairs has a ground pour within a class clearance of it. M13b gave the
derivation a coplanar model, which reads the `pours:` block, solves the pair against
the ground beside it as well as the plane under it, and says in `check`'s output
which of the two models each class used.

What did not come free is the mesh. A coplanar-derived pair is narrower, and the cell
size M12 calibrated on a wider one returns **12 ohm for an 85 ohm line** — converged,
exit code zero, no warning. The mesh now follows the geometry.
[ADR 0012](decisions/0012-coplanar-impedance.md) and
[`docs/reports/m13.md`](reports/m13.md) carry both measurements, and the honest
state of the third link: `REFCLK`'s slice traps energy and its number is not one to
act on.

Each pair is cut out of the routed board as a **slice** — a small self-contained
`.kicad_pcb` carrying that pair, the copper near it, the planes it is referenced to
and four simulation ports — and handed to openEMS through Antmicro's gerber2ems in a
pinned container. What comes back is S-parameters; what you get is the same
source-referenced findings as `check`, plus the raw Touchstone file if you would
rather work in scikit-rf.

Three things the source knows that a geometric slicer could not:

* a pair split by `role: ac_coupling` capacitors is **one link**, not two stubs, so
  the capacitors become copper and the ports go where the link really ends;
* the reference plane comes from `layout.stackup.planes`, not from guessing which
  copper is nearest;
* each port is terminated in half the class's declared `impedance_diff_ohm`, so the
  measurement is of the line rather than of the mismatch.

It is a separate command and stays one. A pair costs one to thirteen minutes where
the whole of `check` costs seconds — and, more to the point, an impedance eight
percent off target is a number to think about, not a correctness failure. Re-running
an unchanged pair costs nothing: the cache key is a hash of what the solver actually
reads.

The honest limit, in the same place as the feature: **this validates the layout, not
the board.** Every number comes from the stackup the source declares. A fabricator
who presses a different prepreg builds a different impedance and nothing here will
know. It finds a pair routed too narrow or a reference that is not where the class
said; it does not replace an impedance coupon.

Running it needs a container runtime and a locally built gerber2ems image — the only
part of aipcb that needs either. [ADR 0011](decisions/0011-si-simulation.md)
records the pinned commits and how the image was built.

### Routing

Routes are stored as **topology**, not geometry — which obstacles a wire passes and
on which side:

```yaml
layout:
  routes:
    - net: CROSS
      from: J1.1
      to: J2.1
      passes:
        - obstacle: U1.2
          side: left      # looking along the direction of travel
          reason: Going over the MCU leaves the lower half of the board for SENSE.
```

Nothing there is a coordinate, which is the point: move a part and the sketch is
still true, so only the tightening re-runs. Flip `side` to `right` and the same
sketch produces a different board.

```bash
.venv/bin/aipcb route check examples/routing-demo/design.yaml   # is it buildable?
.venv/bin/aipcb route all   examples/routing-demo/design.yaml   # build it
```

Geometry comes from rubber-band tightening: obstacles are inflated by the clearance
the net needs, the remaining free space is triangulated, the sketch picks a homotopy
class, and the funnel algorithm pulls the wire taut inside it. Because the obstacles
were inflated *first*, the shortest path through what is left is automatically a
legal one — clearance holds by construction rather than being checked and patched.

Connections without a sketch are routed automatically, across every signal layer
the stackup allows. Layer, via position and corridor come out of one search rather
than three sequential decisions, and the corridors are settled by **negotiation**:
every net is routed as though it had the board to itself, the corridors that end up
over-subscribed get more expensive, the nets that lost the argument are ripped up
and re-routed, and it repeats until every cut across the free space carries no more
copper than it has room for. Ripping up costs nothing, because a route at that stage
is a set of subscriptions rather than a piece of copper.

```bash
.venv/bin/aipcb route all examples/mcu-4layer/design.yaml
```

```
routed 36 connections (0 unrouted) on B.Cu, F.Cu, 140 track segments and 5 vias,
547.86 mm of copper
```

The source gets a say in the outcome. A net class can state a `priority` and a
`rip_up` policy, and on each contested corridor the net that is hardest to rip up
keeps its place while the rest go round:

```yaml
net_classes:
  clk_sys:
    priority: 90
    rip_up: protected
```

The stackup gets a say too. A layer listed under `stackup.planes` is closed to
signal routing — enforced, not advisory — and a via is modelled as a *column*, so it
blocks every layer its barrel passes through and not only the two it connects. What
each of those choices costs is one file: [`docs/routing-costs.md`](routing-costs.md).

Every routed board in `examples/` passes `kicad-cli pcb drc`, and **all seven route
completely** — including `led-blinker` and `usb-port`, which cannot be routed on one
layer at all: a DIP-8's pin rows and a Micro-B receptacle's 0.65 mm pitch leave no
corridor at 0.25 mm tracks and 0.2 mm clearance. The second layer is the answer, and
the router finds it. Where a connection genuinely cannot be made, it is reported with
a reason rather than silently skipped.

A differential pair is tightened *once*, as a single centre-line wide enough for
both traces and the gap, then offset to either side — so the gap is right
everywhere by construction and the halves come out the same length. Where they do
not, the shorter half is meandered in its own corridor until they do:

```
info[diff-pair-length-matched]: USB_DM+USB_DP: 1.591 mm of meander added to USB_DM
to meet its 0.150 mm skew budget
```

Where a pair cannot honestly be coupled, it says so and routes the halves separately
rather than shipping something that only looks like a pair:

```
warning[diff-pair-not-coupled]: DEV_DM+DEV_DP could not be fanned out to its pads:
pair fan-out DEV_DP: the end is not in the routable area
```

The algorithm, the prior work behind it, and the several ways it can be got subtly
wrong are in [`docs/topology.md`](topology.md),
[ADR 0006](decisions/0006-routing-approach.md) (one layer) and
[ADR 0007](decisions/0007-multilayer.md) (all of them).

### The board is a shape, not a rectangle

Real boards go inside things. `board:` is where the mechanical boundary lives — an
outline that may have arcs, cutouts that pierce every layer, and the edge clearance
copper must keep:

```yaml
board:
  origin: bottom_left          # the source frame is Y up
  outline:
    polygon:
      - [0, 0]
      - [42, 0]
      - { arc_to: [48, 6], center: [42, 6] }
      - [48, 26]
      - [36, 26]
      - [36, 34]
      - [0, 34]
  cutouts:
    - rect: [[16, 10], [22, 18]]
      reason: The display's flex tail passes through here.
  edge_clearance: 0.3
```

That is not just an `Edge.Cuts` export. The placer packs into the real polygon, so
nothing lands in the missing corner or over the hole; the validator checks
courtyards against it; and the router sees the outline and every cutout as
obstacles in each layer's triangulation, so two points either side of a slot are
genuinely in different homotopy classes.

`placement:` says where the enclosure puts a part, in three levels:

```yaml
placement:
  J1:
    fixed: { x: 4.0, y: 17.0, rot: 270 }
    reason: The receptacle lines up with the port in the enclosure's west wall.
  H1:
    fixed: { x: 4.0, y: 28.5 }
    role: mounting_hole
  SW1:
    edge: { side: north, offset_range: [12, 30] }
    reason: Under the moulded cap in the lid.
  D1:
    region: { rect: [[28, 27], [34, 32]] }
    reason: Under the light pipe.
```

`fixed` outranks everything: a group that names a fixed part deforms around it, and
the anchor does not move. Conflicts are caught by `aipcb validate` against geometry
alone — two fixed courtyards overlapping, a part off the polygon, a courtyard over a
cutout, an `edge` span with nowhere to go, a `max_distance` the anchors already make
impossible.

If somebody nudges a fixed part in KiCad, `aipcb build` puts it back and says so.
When the board is right and the source is stale, `aipcb sync-placement` goes the
other way and rewrites the YAML in place, comments and all.

[`examples/enclosure`](../examples/enclosure/design.yaml) is the worked example: a
shaped board with an arc and a cutout, a fixed connector and two fixed mounting
holes, an edge-constrained button and a region-constrained LED. It builds, places,
routes completely, and passes KiCad's DRC with zero violations.

### Escaping a fine-pitch package

A QFN-32 on a 0.5 mm pitch leaves nothing to route out through. That is not a
routing problem, it is a pattern, and `fanout:` asks for it:

```yaml
fanout:
  U1:
    style: auto
    escape_layers: [B.Cu]
    via: { drill: 0.2, diameter: 0.4 }
```

A deterministic generator runs *before* routing, lays a stub from each pad to a via
just clear of the part — staggered into two rows, because a single row at pad pitch
would be one piece of copper — and publishes those vias as the terminals the router
sees in place of the package's pads. The rubber-band router that follows has no idea
a fanout happened.

[`examples/qfn-fanout`](../examples/qfn-fanout/design.yaml) routes an ATmega328P in a
32-pin QFN to completion, with zero DRC violations.

### Copper pours, and who fills them

Nearly every real board wants ground on its outer layers, and many want a plane
split between two supplies. `pours:` says which net owns which copper:

```yaml
pours:
  - net: VCC
    layer: In2.Cu
    scope: board
  - net: GND
    layer: In2.Cu        # a split plane: ground takes this corner back
    region: { rect: [[42, 2], [54, 16]] }
    priority: 1          # higher priority keeps the copper where zones overlap

stitching:
  - net: GND
    between: [F.Cu, B.Cu]
    pattern: grid        # grid | edge | ring
    pitch: 5.0
```

`aipcb` emits the zone — its boundary and its rules — and **never a filled
polygon**. KiCad's own filler produces the copper, because KiCad's fill is what DRC
checks against; a second implementation would differ, and the difference would be a
bug on every board ([ADR 0009](decisions/0009-pours.md)). `aipcb build` stays a
byte-stable pure function of the source with its zones unfilled; `aipcb check` and
`aipcb export` fill a staged copy first, because KiCad plots whatever fill data is
in the file and an unfilled pour exports as *no copper at all*, silently.

Stitching vias are generated the same way fanout escapes are: a deterministic
pattern, laid after routing and before the fill, dropping positions that would foul
a track, a pad, another hole or the board edge — silently, but with the counts in
the report.

After the fill, `aipcb check` reads the filled polygons back and says what the
copper actually came out as:

```
examples/qfn-fanout/design.yaml:243:5: warning[plane-fragmented]: the GND pour on
B.Cu is in 5 pieces; its largest holds 86.2% of the copper, below the 90.0% this
pour asks for
  hint: a track crossing the plane is the usual cause; move it, give it a layer of
  its own, or stitch the pieces together
```

That is feedback, not a gate — fragmented-but-functional is common, and the warning
only fires when the source sets `min_contiguous:`.

Filling needs KiCad's Python module (the `kicad` package, not only `kicad-cli`), and
only for designs that declare `pours:`.

### When the board cannot be routed

The router does not deliver marginal geometry. When a connection cannot be made
DRC-clean, it is *handed over*: everything else is routed, and the refusal comes back
machine-readable.

```console
$ aipcb route all examples/overconstrained/design.yaml --json | jq '.routing.handed_over[0]'
{
  "net": "SWAP_B",
  "from": "J1.2",
  "to": "J2.3",
  "unrouted": "over_complexity",
  "reason": "the free area is split in two by other parts' clearances",
  "blocked_at": [
    { "layer": "F.Cu", "at": [108.075, 110.0], "width_mm": 4.15,
      "demand_mm": 1.8, "over_subscribed": false,
      "nets": ["SWAP_A", "SWAP_B", "SWAP_C", "SWAP_D"] }
  ]
}
```

An agent can act on that — add a layer, move a part, drop a priority. A human can
route those nets by hand in KiCad, and the incremental build then preserves that
copper and treats it as law. What the toolchain will never do is ship a board with
DRC violations and call it routed.

### What the via pass took back — `routing.reclaimed` *(beta)*

After negotiation converges, M17's via pass re-tightens every span where a route
leaves a layer and comes back, and every connection whose two pads share a layer,
keeping the single-layer result only when it costs fewer vias and no more copper.
What it took back is reported:

```console
$ aipcb route all examples/pcie-sata/design.yaml --json | jq '.routing.reclaimed'
{
  "spans_considered": 18,
  "spans_collapsed": 2,
  "vias_removed": 4,
  "retraces_removed": 1,
  "copper_saved_mm": 30.285,
  "rejected": { "longer": 10, "capacity": 0, "unrealizable": 6 },
  "skipped_controlled_impedance": 0,
  "collapsed": [
    "GND U1.17>U1.49 gave back a retrace, 2 vias and 17.116 mm of copper on F.Cu",
    "GND U1.49>U1.42 gave back 2 vias and 13.169 mm of copper on F.Cu"
  ]
}
```

`rejected.capacity` is zero there, and it is zero on every bundled example: across
the whole corpus **not one span was rejected on capacity**, because length is the
binding constraint everywhere in it. The arbiter is built and unit-tested and has
never fired on real data — which is a fact about the corpus rather than about the
arbiter, and the first thing to re-measure when a denser board exists.

It is a **permanent part of the public interface**, alongside the `reclaim` stage
that `aipcb bench` records in its per-stage timings — both are things a caller may
depend on, not implementation detail that happened to leak. Both are **beta**: the
key is stable, its *shape* may still gain fields, and a bench result from before
M17 simply has no `reclaim` key, which `--compare` handles by deriving its columns
from the data rather than from a fixed list.

The measured effect on the bundled corpus is small and honest about it: **four vias
and 30.3 mm of copper, on one board**, from 55 candidate spans. The other 53 are
rejected because the single-layer route is longer or the free space on that layer is
split. This router's vias are, with four exceptions, load bearing —
[the M17 report](reports/m17.md) has the per-board table.

### Reading part of a design

An agent working on one corner of a board should not have to hold the whole thing
in context. `aipcb summary` is meant to be the first thing read about an unfamiliar
design, and small enough that reading it is never the expensive choice:

```bash
.venv/bin/aipcb summary examples/ldo-supply/design.yaml
```

```
ldo-supply rev A
  Unregulated DC in, 3.3 V out, using an AMS1117 LDO.
  7 components, 3 nets, 15 connections, 2 constraints
  net classes: ground x1, power x2

blocks:
  (top level)   2 parts  J1, J2  [connector]
  rail_3v3      5 parts  C1, C2, C3, C4, U1  [bulk, bypass, regulator]

constraints:
  max_distance: rail_3v3.CIN, rail_3v3.U
    Input capacitor loop inductance sets how well the LDO rejects supply transients.
```

`aipcb query module` then zooms in on one block — including the parts on the *other*
side of its ports, since a module read in isolation says nothing about what it
drives:

```
module rail_3v3
  components:
    C1    C_100N_0603  role=bypass  for=U
    ...
  ports (nets crossing the boundary):
    VIN [power]  inside C3.1, U1.3  ->  J1.1
    VOUT [power]  inside C1.1, C2.1, C4.1, U1.2  ->  J2.1
  neighbours:
    J1    CONN_PWR_1X02  role=connector
    J2    CONN_PWR_1X02  role=connector
```

`query component`, `query net`, `query net-class` and `query role` narrow further.
Every one of them takes `--json`, and text and JSON are two renderings of one
structure, so they cannot disagree about what a design contains.

### A minimal design

```yaml
name: divider
libraries: [../library/passives.yaml]

nets:
  VIN:  { class: power, voltage: 3.3 }
  MID:  { class: analog }
  GND:  { class: ground }

components:
  R1:
    part: R_10K_0603
    role: divider
    reason: Upper leg. Ratio sets the ADC's full-scale point.
    pins: { "1": VIN, "2": MID }
  R2:
    part: R_10K_0603
    role: divider
    for: R1
    pins: { "1": MID, "2": GND }
```

The three bundled examples build up from there:

* [`examples/led-blinker`](../examples/led-blinker/design.yaml) — an ATtiny85, an ISP
  header, and a parameterised `indicator` module.
* [`examples/ldo-supply`](../examples/ldo-supply/design.yaml) — a `regulated_rail`
  module instantiated like a function, with `count:` stamping out bypass caps.
* [`examples/usb-port`](../examples/usb-port/design.yaml) — a differential pair with
  an impedance target, skew budget, and routing intent.
* [`examples/routing-demo`](../examples/routing-demo/design.yaml) — exists for the
  routing: a signal crossing the board past an MCU that is squarely in the way.
* [`examples/diff-pair`](../examples/diff-pair/design.yaml) — a 100 Ω pair carried
  across a board, routed as a coupled pair with zero skew.
* [`examples/mcu-4layer`](../examples/mcu-4layer/design.yaml) — signal / ground /
  power / signal, with a DIP-8 the ISP bus has to get *under* and two planes the
  router will not put a signal on.
* [`examples/congestion`](../examples/congestion/design.yaml) — four wires reversed
  across a channel. Not routable on one layer; routable on two, and the negotiation
  works out which ones dive.

## Routing is optional

You do not have to trust an unknown autorouter to get value out of this. Routing is
one step of the pipeline, it is declared in the source, and there are three ways to
run it. Everything else — validation, placement, pours, ERC, DRC, the high-speed
checks, Gerbers — works identically in all three.

### Full auto

```bash
aipcb route all design.yaml     # topological router, DRC-clean or handed over
aipcb check design.yaml
```

The router refuses to deliver marginal geometry. What it cannot make legally it
*hands over*, naming the connection, the corridor that ran out of room, and the nets
contesting it.

### Hybrid — you own the critical nets, aipcb routes the rest

This is the mode most people want first. Declare which nets are yours:

```yaml
net_classes:
  rf:
    trace_width_mm: 0.4
    routing: manual        # every net in this class is yours
nets:
  SENSE:
    class: analog
    routing: manual        # or just this one
  CLK_OUT:
    class: rf
    routing: auto          # ...and this one opts back out of its class
```

```bash
aipcb route all design.yaml     # your nets are left untouched and listed as pending
# ...draw them in KiCad...
aipcb check design.yaml         # checks all copper identically, whoever drew it
```

### Fully manual

```bash
aipcb build design.yaml         # footprints placed, no copper
# ...draw all of it in KiCad...
aipcb check design.yaml --no-route
```

Whichever mode, `aipcb check --json` puts every net in one of four states:

| State | Meaning |
|---|---|
| `manual-routed` | declared manual, and copper for it is on the board |
| `manual-pending` | declared manual, and **there is no copper yet** |
| `auto-routed` | aipcb's router laid it |
| `handed-over` | the router tried and refused, with the reason and the blocking corridor |

`manual-pending` is the one to watch: it is where a board sits between "these pairs
are mine" and "I have drawn them", and to anything counting unrouted connections it
looks exactly like a finished board. `aipcb check` warns about it by name.

Hand-drawn copper is preserved by every later build and routed *around*, never
through. The full loop is in [`docs/workflows.md`](workflows.md); routing
declared-manual nets with an external router such as Freerouting, headlessly, is in
[`docs/external-routers.md`](external-routers.md).

## Commands

| Command | What it does |
|---|---|
| `aipcb validate DESIGN` | schema and semantic checks, with source-referenced diagnostics |
| `aipcb build DESIGN` | compile to `.kicad_sch`, `.kicad_pcb`, `.kicad_pro` and the project library tables; `--render` also plots the schematic to `review/` |
| `aipcb check DESIGN` | build, route, run KiCad's ERC and DRC, report violations against the source |
| `aipcb sync-placement DESIGN` | report parts moved in KiCad, and write their positions back into the source |
| `aipcb export DESIGN` | Gerbers, drill files, BOM and placement file into `out/`; `--dsn` writes a Specctra DSN for an external router instead |
| `aipcb import DESIGN --ses FILE` | import an external router's session file, splice it in, verify it against the source, and check the result |
| `aipcb route check DESIGN` | verify route topologies are realizable, and that they fit alongside each other |
| `aipcb route all DESIGN` | route the board across every signal layer and write tracks and vias |
| `aipcb simulate DESIGN` | solve each differential pair with openEMS and report impedance, return and insertion loss |
| `aipcb bench` | route every bundled example and record what it cost and what it was worth; `--compare` diffs against a baseline |
| `aipcb summary DESIGN` | one-line-per-block overview |
| `aipcb query ...` | read one module, component, net, net class or role |
| `aipcb parts DESIGN` | list the parts the design's libraries provide |
| `aipcb schema` | emit the JSON Schema for the source format, for editor completion |
| `aipcb version` | report the aipcb and KiCad versions in use |

Every command takes `--json`. Exit codes are `0` clean, `1` errors found, `2` input
unreadable.

## Status

| Milestone | State |
|---|---|
| M1 — format, validation, examples | **done** |
| M2 — schematic compile (`.kicad_sch`, passes ERC) | **done** |
| M3 — netlist and board skeleton | **done** |
| M4 — check loop over `kicad-cli` ERC/DRC JSON | **done** |
| M5 — query layer for partial reads | **done** |
| M6 — incremental build preserving manual edits; Gerber export | **done** |
| M7a — topology model and validation | **done** |
| M7b — rubber-band stretcher, DRC-clean tracks | **done** |
| M7c — congestion-aware auto-topology | **done** |
| M7d — differential pairs, impedance and skew | **done** (meander length-matching landed with M8c) |
| M8a — layered triangulations, via columns, cut capacity | **done** |
| M8b — multilayer search with negotiated congestion, priority and rip-up | **done** |
| M8c — pairs as one object, meander length-matching, layer preference | **done for pairs and meanders**; crossovers are still refused with a reason ([ADR 0007](decisions/0007-multilayer.md)), and a pair *changing layer* is built since M11c |
| M8d — stretcher integration and acceptance | **done**: all seven examples route completely, and pass DRC with one warning on the *unfilled* board ([`diff-pair`](../examples/diff-pair/design.yaml) keeps a copper sliver where a ground track threads between a header's two pads; since M10 the ground pour fills the wedge and `aipcb check` reports zero) |
| M9-outline — the board boundary as a source object | **done**: arcs, cutouts and edge clearance, propagated into the placer, the validator and every layer's free space |
| M9a/M9b — three-level placement, fixed parts as anchors | **done** |
| M9c — mechanical conflict validation | **done**: eleven checks, all before anything is built |
| M9d — drift reporting and `aipcb sync-placement` | **done** |
| M9e — pattern-based fanout | **done**: perimeter and dog-bone escapes, thermal vias in an exposed pad; via-in-pad only when asked for |
| M9f — honest failure | **done**: what the router will not deliver legally is handed over, with the corridor that blocked it |
| M10a — pours as source intent | **done**: layers or region, priorities, thermal or solid, per-pad-instance overrides |
| M10b — fill integration and the stability policy | **done**: KiCad's own filler in a `pcbnew` subprocess with a version lock ([ADR 0009](decisions/0009-pours.md)); build stays byte-stable and unfilled |
| M10c — stitching vias | **done**: `grid`, `edge` and `ring` patterns, deterministic, with skip counts reported |
| M10d — plane-integrity report | **done**: islands, largest-island fraction and bounding boxes read back off the filled board |
| M11a — controlled-impedance net classes | **done**: `impedance_diff_ohm` and a declared stackup derive the pair's width; an explicit width that disagrees by more than 10% is reported with the impedance it will actually produce |
| M11b — card-edge connector integration | **done**: the footprint's own `Edge.Cuts` is a specification the `board:` block has to reproduce, checked to 0.01 mm, with the missing vertices handed back in the error; pour keepout, thickness check and the bevel fab note ([ADR 0010](decisions/0010-highspeed.md)) |
| M11c — pair via transitions and AC coupling | **done** for transitions: two signal vias at a column opened out from the pair's pitch, ground returns, the stub computed from the stackup, and two coupled segments for the router. **Partly** for AC coupling: the pairing, the symmetry and the budget are validated and measured; the capacitors are not *placed* |
| M11d — stretcher environment discipline | **done**: the three bounded rules, and no others. The default 3x standoff is not available on a 0.5 mm pad pitch and refuses loudly there |
| M11e — high-speed verification report | **done**: reference continuity projected onto the declared plane after the fill, geometry audit off the copper, skew, stubs and coupling budget. Rule-based, and it says so |
| M12a — slice generation | **done**: one slice per pair, cut out of the routed board with its neighbours, planes and vias; `role: ac_coupling` parts bridged so a split lane is one link; a straight launch and four ports at the ends. Slices are byte-stable |
| M12b — simulation orchestration | **done**: openEMS in the pinned container ADR 0011 records, sequential (openEMS already uses every core), cached on a hash of what the solver reads, per-pair failures, and a manifest. No `--parallel`, measured rather than assumed |
| M12c — structured results | **done**: differential impedance against the class target, worst return loss and its frequency, insertion loss at the class's key frequencies, group delay, and pass/warn per metric — as `check`-shaped findings pointing at the source. Raw S-parameters kept as Touchstone. The thresholds are engineering defaults and say so |
| M13 — routing correctness, impedance model, skew verdict | **done**: the obstacle-set merge that was losing copper, the coplanar model M12 measured, and the fitted-Δτ verdict ([`docs/reports/m13.md`](reports/m13.md)) |
| M14a/M14b — readable schematics | **done**: placement driven by roles, `for:` references, module structure and the signal-flow graph; power symbols, staggered stubs, module frames. Overlapping items across the eleven examples: 71 → 0; mean decoupling-to-IC distance on `pcie-sata` 157.5 mm → 27.8 mm; the sheet dropped from A1 to A3. Netlists byte-identical, ERC still 0 ([ADR 0003 amendment](decisions/0003-schematic-generation.md)) |
| M14c — manual-edit policy for schematics | **done**: M6's preserve never covered `.kicad_sch` and silently overwrote edits. The sheet is now explicitly a *view*, and a rebuild that discards an edit says so |
| M14d — `routing: manual` | **done**: declared on a class or a net, honoured by the router, reported as four distinct states ([`docs/workflows.md`](workflows.md)) |
| M14e — headless external-router bridge | **done**: `aipcb export --dsn` / `aipcb import --ses` through the `pcbnew` subprocess, existing copper fixed on the way out and spliced rather than replaced on the way back. Round-tripped through Freerouting 2.3.0 headlessly with 0 DRC errors ([`docs/external-routers.md`](external-routers.md)) |

## Documentation

* [`docs/format.md`](format.md) — the source-format reference.
* [`docs/topology.md`](topology.md) — how a route is stored, and how it becomes
  copper on however many layers it takes.
* [`docs/routing-costs.md`](routing-costs.md) — every number the router weighs,
  with its default and why.
* [`docs/workflows.md`](workflows.md) — working in KiCad alongside aipcb: what
  is preserved, moving parts, the three routing modes, and why the schematic is a
  view rather than a document.
* [`docs/external-routers.md`](external-routers.md) — the headless DSN/SES
  bridge: three commands, the contract, and the rule about controlled impedance.
* [`docs/roadmap.md`](roadmap.md) — what is deliberately not built, and why.
* [`docs/reports/`](reports/) — one delivery report per milestone, with the
  numbers each one was measured against.
* [`docs/decisions/`](decisions/) — architecture decision records. Start with
  [0001 (KiCad I/O)](decisions/0001-kicad-io.md), which explains why this
  project writes its own S-expression layer instead of using `kiutils`.

## Development

```bash
.venv/bin/pytest          # about 1270 tests, roughly 50 minutes (it runs KiCad for real)
.venv/bin/ruff check .
.venv/bin/mypy
```

Tests that need KiCad skip with an explicit reason when it is absent, so the suite
runs headless in CI. `AIPCB_FULL_CORPUS=1` runs the lossless round-trip test
against all ~16,000 KiCad files on the machine instead of a 400-file sample.

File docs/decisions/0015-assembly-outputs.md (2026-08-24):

# 0015 — What an assembler is sent, and the one part of it this project will not guess

* **Status:** Accepted
* **Date:** 2026-08-24
* **Context:** milestone [M21](../milestones/m21-assembly-outputs.md). Extends the
  fabrication export in [`export.py`](../../src/aipcb/compile/export.py) and the
  part schema in [`parts.py`](../../src/aipcb/model/parts.py). The delivery report
  is [`m21.md`](../reports/m21.md).

## 1. The gap analysis, which is where this milestone started

M21's brief carried a correction: `aipcb export` already advertises "a BOM and a
placement file", so the milestone was likely hardening rather than building. The
audit says: **the files exist, and neither is an assembly file.**

| | what shipped before M21 | what an assembler needs |
|---|---|---|
| BOM | `kicad-cli sch export bom`, columns `Reference,Value,Footprint,QUANTITY,Description` | fab-specific column names; a manufacturer part number; the fab's own part id |
| BOM grouping | `--group-by Value,Footprint`, designators compressed to ranges (`J2-J5`) | one line per purchasable thing; designators listed, not ranged (§2.3) |
| placement | `kicad-cli pcb export pos`, columns `Ref,Val,Package,PosX,PosY,Rot,Side` | fab-specific column names; `Top`/`Bottom`; rotation in the fab's range |
| what is in it | every footprint KiCad does not exclude | only what a machine places, and PCBWay only what it places *by reflow* |
| procurement | `Supplier.manufacturer`/`.mpn` existed in the model and **reached nothing** — only `datasheet` was emitted | the whole point of a BOM |
| DNP | a `dnp` flag reached the schematic and the board | must reach both assembly files |

So the two existing files are correct KiCad output and neither is orderable. They
are kept, unchanged and byte-identical, because they are what the *fabricator*
package has always contained and nothing in this ADR is a reason to move them. The
assembly files are new, additive, and off unless asked for.

## 2. What each assembler actually asks for

Measured from each fab's own published requirements on 2026-08-24, not inferred
from somebody's exporter.

### 2.1 JLCPCB

* **BOM** — `.csv`, `.xls`, `.xlsx`. Required: `Comment`, `Designator`, `Footprint`.
  Their KiCad guide adds `JLCPCB Part #`, which is the LCSC id. Maximum 200
  designators per line; no duplicate designators anywhere in the file.
* **CPL** — `.csv`, `.xls`, `.xlsx`. Columns `Designator`, `Mid X`, `Mid Y`,
  `Rotation`, `Layer`. **Units: millimetres.** `Layer` is `Top`/`Bottom`. Both
  sides in one file.
* **Rotation** — *"The rotation of the component given in degrees. Positive values
  are counter clockwise."*
* **Cross-file rule** — designators must match between the two files exactly, and
  case-sensitively: *"the letter case of reference designators must be consistent
  between the BOM and CPL files (e.g. `R1` ≠ `r1`)"*. Only components appearing in
  both are recognised.
* **DNP** — not documented. Their pages say nothing about how to mark a part that
  must not be fitted.

### 2.2 PCBWay

* **BOM** — `.xls`, `.xlsx`, `.csv`. For a turn-key order: `Line#`,
  `Quantity Per Part Number`, `Reference Designator`, `Part Number`,
  `Part Description`, `Package`, `Type` (*"Surface mount, Thru-hole or Hybrid"*),
  `Manufacturers Name`, `Manufacturers Part Number`, `Distributors Part Number`.
* **Centroid** — reference designator, X, Y, rotation, side (`Top`/`Bottom`), and
  one rule JLCPCB does not state: **"Only surface mounting parts are listed in the
  Centroid."**
* **DNP** — not documented.

### 2.3 What that means for the design

Three findings shaped the implementation:

1. **The two fabs disagree about the file's contents, not just its column names.**
   PCBWay's centroid excludes through-hole parts; JLCPCB's documentation does not.
   So a format is not a rename — it carries rules — which is why
   [`FORMATS`](../../src/aipcb/compile/assembly.py) holds `centroid_is_smt_only`
   beside the column tuples.
2. **Neither fab documents a DNP convention.** A part that must not be fitted is
   therefore said in the column a human reads: the BOM `Comment` gains
   `(DNP - DO NOT POPULATE)` and the part never reaches the centroid. Marking it
   only in a machine column nobody has specified would be worse than saying it in
   words, because a silent DNP is a fitted part.
3. **JLCPCB's documented limits are checked, not just its columns.** A
   bill-of-materials line carrying more than 200 designators is a rejected upload,
   so it is a warning that names the line rather than a file the fab bounces.
4. **Designators are listed, never ranged.** KiCad's own BOM compresses `J2,J3,J4,J5`
   to `J2-J5`. Neither fab documents range notation, JLCPCB matches designators
   between the files literally, and a range that is not expanded is four parts that
   do not match. Listing them costs nothing and cannot be misread.

## 3. Coordinates: the origin, and why they are not computed twice

The centroid is derived from the placement CSV `kicad-cli pcb export pos` already
writes, and not from a second reading of the board.

That file is exported with `--use-drill-file-origin`, as the Gerbers and the drill
file are. Measured on `examples/pcie-sata`: the board's `aux_axis_origin` is
`(100, 145)` in KiCad's own frame, `U1` sits at `(140, 119)`, and the placement file
records `(40, 26)`. So the transform is

> `x_file = x_kicad − origin_x`,  `y_file = origin_y − y_kicad`

— the origin subtracted, and **Y inverted**, because KiCad measures down from the
sheet corner and the placement file measures up from the drill origin. Nothing in
this project reimplements that. The decision is that the assembler's file and the
fabricator's files are two views of one measurement, and the cheapest way to
guarantee that is to make one of them a transcription of the other.

The overlay in `overlay_svg` is the only place the transform is written down, and it
is written down there because the overlay draws the *board outline* — which comes
from the board — into the *placement file's* frame.

## 4. Rotation: the convention is implemented, the correction is not, and that is the decision

**The convention needs no transform.** Both fabs document degrees, counter-clockwise
positive. KiCad writes degrees, counter-clockwise positive. The only difference is
range — KiCad signs them, the fabs' samples run 0–360 — so the value is folded into
`[0, 360)` and **no part turns**.

**The correction is a different thing, and this project does not ship one.** What
breaks real boards is not the convention but the *zero reference*: a fab whose parts
library holds a package at a different orientation from the KiCad footprint needs a
per-package offset, and the failure is silent — a QFN or SOT-23 soldered 90° out,
pin 1 in the wrong corner.

Three things were established about that correction, and together they are the
reason it is not implemented here:

1. **Neither fab publishes it.** JLCPCB documents the convention and not the
   offsets. There is no authoritative table to verify an implementation against,
   and M21's guardrail is explicit that the mapping must be verified against the
   fab's documented convention rather than inferred.
2. **It is not algorithmic.** The community tooling that solves this — KiBot's
   `rot_footprint` filter, `kicad-jlcpcb-tools`' rotation database — is a lookup of
   regular expressions over footprint names, forty-odd entries long, maintained by
   hand.
3. **It is not even a function of the footprint.** KiBot's own documentation says
   so plainly: *"you can have two components with the same footprint and different
   rotations in the same project."* A table keyed by footprint is therefore a
   heuristic by construction, and a heuristic that is wrong is worse than no table,
   because a wrong offset looks exactly like a right one until the board comes back.

There is a fourth reason and it is this project's standing one: those tables are
other projects' work under their own licences, and copying data out of them is the
same act as copying code out of them.

**So: the convention is implemented exactly, no correction table ships, and the
verification is a picture.** `aipcb export --assembly` renders a placement overlay
per side, drawn *from the centroid file's own rows* — every part where the file puts
it, turned the way the file turns it, with a dot marking where pin one lands after
that rotation. A file can say `180` and look perfectly ordinary; the cheap way to
notice a backwards diode is to see its cathode on the wrong end. When a part does
need an offset, it is declared on the part, and the overlay is how a person
convinces themselves it worked before spending money.

## 5. `assembly:` is measured, not defaulted

M21's brief proposed `assembly: smt | tht | dnp | none` defaulting to `smt`. The
enum is implemented as specified; **the default is not**, and the reason is a
measurement on this repository's own corpus.

Four bundled examples are built around through-hole parts — the breakout headers in
`congestion`, the DIP-8 in `mcu-4layer` whose two rows of pins are the obstacle that
board exists to route around, the pin headers in `backplane`, the power header in
`ldo-supply`. A default of `smt` would have told PCBWay to reflow all of them, and
the error would have been silent in exactly the file whose job is to catch it.

So an undeclared `assembly:` is read off the footprint KiCad actually placed: its
`(attr ...)` flags, and where those say nothing, the pad types. A declaration always
wins. Verified on `mcu-4layer`, where `J2` (a 1×06 pin header) and `U1` (a DIP-8)
are detected as through-hole, appear on the bill, and are correctly absent from
PCBWay's centroid.

`none` is a fourth state the brief did not have and the corpus needed: a card-edge
finger field and a mounting hole are on the board, are on a net, and are neither
bought nor placed. Without it, `examples/pcie-sata`'s gold fingers appeared on the
bill of materials as a line an assembler cannot source.

## 6. The schema has two spellings for one field, deliberately

`Supplier.manufacturer` and `Supplier.mpn` predate this milestone and two bundled
libraries already use them. M21a's brief puts `mpn:` and `manufacturer:` at the top
level of a part. Both now validate, `Part.procurement()` folds them, and declaring
the same field twice with *different* values is an error rather than a silent
winner.

That is a wart and it is the cheaper of the two available warts: the alternative was
to break every part file that already carries `supplier:`. The top-level spelling is
the current one and is what documentation shows.

## Decision

1. **Keep the existing Gerber, drill, BOM and placement export unchanged and
   byte-identical.** The assembly files are additive and produced only on request.
2. **Derive the centroid from KiCad's placement file**, never from a second reading
   of the board, so the assembler's coordinates and the fabricator's are one
   measurement.
3. **Drive the bill of materials from the netlist**, not from the placement file, so
   that a part KiCad excludes from position files is still something you can buy.
4. **Implement each fab's format as columns plus rules**, from its own published
   requirements, with the sources recorded in §2.
5. **Implement the rotation convention exactly; ship no correction table.** Provide
   the overlay as the verification, and say in the documentation that a package
   needing an offset must declare it.
6. **Measure `assembly:` off the footprint when it is not declared**, and add
   `none` for footprints that are not components.
7. **Refuse to write an assembly package for a board with back-side parts.**
   `side: back` validates, warns, and places on the front (M9), so a back-side
   centroid would not describe the board that was built.

## Consequences

**What this buys.** A design whose parts carry procurement data produces an order
package in one command, and one whose parts do not is *told which parts*, by
designator, rather than being left to find out at the assembler.

**What it does not buy, and this is the honest part.** A clean export is not a
guarantee that the order is correct. Three gaps survive this ADR and are named so
that nobody reads a green run as more than it is:

* **Rotation offsets are unverified until a board comes back.** The overlay reduces
  the risk to what a human can see; it does not eliminate it. The first assembled
  order of any design is the test.
* **Nothing checks that an MPN is *the right part*.** The tool checks that a string
  is present. A wrong part number exports as cleanly as a right one, which is why
  §4's rule against guessing applies to part numbers too and why
  `examples/pcie-sata`'s controller has none.
* **Two-sided assembly is unimplemented, not merely untested.** The guard in
  decision 7 is a refusal, and it stays until `side: back` is implemented.

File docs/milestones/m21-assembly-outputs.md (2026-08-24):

# Assembly outputs: BOM & pick-and-place export (M21)

The fab round is blocked on one gap: an assembled order (the pcie-sata QFN-48 will
not be hand-soldered) requires a BOM and a CPL (pick-and-place) file that a real
assembler accepts. **Important correction to this brief's original premise**:
investigation found that `aipcb export` already advertises "a BOM and a placement
file" and `src/aipcb/compile/export.py` contains BOM/CPL-related code. This
milestone is therefore likely *hardening and verifying existing output against a
real assembler's requirements* rather than building from nothing — the first task
below establishes which. Small milestone, deliberately scoped: exactly what an
assembly order needs, nothing more.

> Named M21 because [M20](m20-placement-quality.md) is placement quality, which was
> split out of M19's review and is sequenced after the fab round.

## Session context (fresh session)

Read the current parts-database format docs, `src/aipcb/compile/export.py` (audit
what BOM/CPL output already exists: which columns, which conventions, whether any
test covers it, whether any assembler format was targeted), and
[`docs/reports/m19.md`](../reports/m19.md). Then, before designing: fetch the
**actual current file-format requirements** for JLCPCB and PCBWay assembly (column
names, rotation conventions, units) — these are documented publicly and they
differ; measure, don't assume. The gap analysis — what the existing code produces
vs. what a real assembler accepts — is the ADR's first section and decides how much
of M21a–c below is new work vs. verification. Record findings in the ADR.

## M21a — Procurement fields in the parts model

Extend the part schema (backward compatible — parts without the fields still
validate):

```yaml
parts:
  STM32G031K8:
    # existing fields...
    mpn: STM32G031K8T6          # manufacturer part number
    manufacturer: STMicroelectronics
    supplier_refs:
      lcsc: C432211              # per-supplier part id, extensible map
    assembly: smt                # smt | tht | dnp | none (default smt)
```

- `dnp` (do-not-populate) must flow through: on the BOM as DNP-marked or excluded
  per the fab's convention (the format research decides), and excluded from CPL
- Validation: warn (not error) on parts lacking `mpn` when an assembly export is
  requested — the report lists exactly which parts block a complete order
- Populate the fields for every part the pcie-sata example uses (this is the forcing
  function the component database needed — real procurement data for the flagship)

## M21b — BOM export

- `aipcb export --bom [--format jlcpcb|pcbway|generic]`: grouped by part (one line
  per unique part, designators aggregated), columns per the researched format;
  `generic` is a clean CSV with everything
- Deterministic ordering (canonical designator sort), byte-stable across runs
- Quantities, values, footprint names as the fab expects them

## M21c — CPL export

- `aipcb export --cpl [--format ...]`: designator, x, y, side, rotation per the
  target format
- **Rotation is the trap — treat it as one**: fab rotation conventions differ from
  KiCad's (zero-orientation reference varies per package, JLCPCB famously needs
  corrections). Research the convention, implement the mapping, and add a
  verification aid: render a placement overlay (top/bottom images with designators
  at their CPL positions/rotations, using the existing render machinery) into
  `out/assembly/` so a human can eyeball polarity and orientation before ordering —
  this catches the classic backwards-diode error the file alone cannot
- `side: back` parts: the M9 limitation (validated, not implemented, places front)
  means back-side CPL is untested — state honestly in the docs that two-sided
  assembly export is unverified until that lands; error if a design actually
  declares back-side parts and an assembly export is requested
- Coordinates in the fab's expected origin/units (the research decides; document the
  transform)

## M21d — The assembly bundle

- `aipcb export --assembly` produces the complete order package: gerbers + drill
  (existing), BOM, CPL, and the placement overlays, zipped per fab convention where
  one exists
- The pcie-sata example's bundle is the acceptance artifact: generated, committed
  under the example's expected-outputs (or hashed in a golden), and *manually
  reviewed once* — the report includes the reviewer's checklist result (all parts
  have mpn, rotations eyeballed against the overlay, DNP handling correct)

## Acceptance

- Format research recorded in an ADR with sources
- pcie-sata: complete assembly bundle generates with zero missing-mpn warnings;
  overlay renders; byte-stable
- All existing examples still export (parts without procurement fields → generic BOM
  works, fab-specific warns with the exact missing list)
- DNP flows correctly through both files; back-side guard errors as specified
- Suite green, mypy strict, schema backward compatible, committed and pushed

## Out of scope

- Supplier API integration (stock/price lookup) — roadmap
- Panelization — still fab-level, still out
- Two-sided assembly (gated on `side: back` implementation)
- Any router/placement work

## Guardrails

- Determinism and backward compatibility as always; export of existing formats
  byte-identical
- The rotation mapping must be verified against the fab's documented convention, not
  inferred from one example — and the overlay exists because files lie and pictures
  don't
- When in doubt, stop and report

## Delivery report (required, in-repo)

`docs/reports/m21.md`: the format research findings, the rotation-convention mapping
with its sources, the pcie-sata bundle checklist result, which parts needed
procurement data added, and any gaps that would block a real order. Measured claims
over asserted ones. Commit and push.

With this milestone green, the fab round has no tooling blockers left: next session
is the design review (schematic vs. the controller's reference design, fab stackup
numbers into the CPWG model) and the order itself.

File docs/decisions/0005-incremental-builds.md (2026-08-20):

# 0005 — Incremental builds: the source owns what it declares

* **Status:** Accepted
* **Date:** 2026-08-20
* **Context:** milestone M6

## Context

`aipcb` generates boards, but people finish them. Someone opens the `.kicad_pcb`,
nudges a connector to line up with an enclosure, routes a differential pair by
hand, pours a ground zone. A rebuild that discarded all of that would make the
toolchain unusable for anything past the first afternoon — and would make the whole
"KiCad as the backend, source as the truth" premise a lie, because in practice
nobody could afford to re-run the compiler.

The brief states the rule: preserve manual work for elements whose source is
unchanged, and let source changes win for the elements they own.

## Decision

**The source owns what it declares; everything else belongs to the person who drew
it.** Applying that needs two questions answered per element.

### Is this the same element? — by UUID

Ours are hashes of source paths, so a footprint's identity survives rebuilds,
edits elsewhere in the file, and any reordering. A UUID we do *not* recognise is by
definition somebody else's work, and is preserved untouched. This is the third
distinct job the deterministic-UUID scheme does, after diff stability (M2) and
violation mapping (M4), and the third reason ADR 0001 could not accept a library
that rewrites them.

### Has the source changed its mind? — by fingerprint

Every generated footprint carries `aipcb.fingerprint`: a hash of the source facts
that determine it — its part, its footprint, its pin-to-net connections, its side,
and any placement constraint or rule that names it. On rebuild, if that hash still
matches, the source has nothing new to say and the human's position stands. If it
differs, the source has changed and the freshly computed placement wins.

The fingerprint deliberately covers *less* than the whole component. A changed
`reason:` or a corrected typo says nothing about placement, and shoving a
hand-placed part back onto the grid because someone improved a comment would make
the feature worse than useless. There is a test for exactly that.

## What is preserved

| Thing | Rule |
|---|---|
| Footprint position, rotation, side | Kept when the fingerprint matches |
| Dragged reference/value text | Kept with the footprint |
| Tracks, arcs, vias, zones, groups, dimensions, added graphics | Always kept — we never generate them |
| Board outline | Kept **only if the source declares no `layout.outline`** |
| Footprint of a deleted component | Removed |
| Copper on a net the design no longer has | Removed, with a warning |

Two of those deserve their reasoning stated.

**The outline.** Drawing the board edge in KiCad is a normal workflow — that is
where the mechanical constraints are visible. A design that says nothing about its
outline has not claimed ownership of it, so whatever is there stays. A design that
declares one owns it.

**Orphaned copper.** A track belonging to a net that no longer exists is not
harmless history; it is a short waiting to happen, and keeping it would mean the
board no longer matches the schematic. It is dropped, and the drop is reported as a
warning rather than done quietly.

## Failure modes

An existing board that cannot be parsed is **not** silently overwritten. It might
hold hours of somebody's routing, so the build reports what went wrong and says the
file will be replaced, leaving the decision with the person who can still move it
aside. `aipcb build --fresh` regenerates from source and discards manual work, for
when that is what is actually wanted.

## Export

`aipcb export` completes the path the project set out to build: source in one end,
a package a board house can quote from out the other, with no step in between that
required opening a GUI. It produces Gerbers for every copper and technical layer,
Excellon drill files with a drill map, a `.gbrjob` job file, a grouped BOM, and a
placement file — all via `kicad-cli`, so the bytes are exactly what KiCad itself
would plot.

The BOM comes from the schematic rather than the board, because that is where the
fields a BOM needs live; it carries the descriptions written in the component
database, so the part list a fab receives says what each part actually is.

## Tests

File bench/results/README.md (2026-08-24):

# Benchmark results

What `aipcb bench` writes, and which of it is committed.

## `baseline.json` — the reference

The one file here that is under version control. It is what CI's smoke run diffs
every pull request against, and what routing quality work has to show its numbers
against. It was measured at M16 on the whole bundled corpus; the run's commit,
timestamp, Python, Shapely and GEOS versions are recorded inside it, because wall
clock without a machine attached is not a measurement.

The `commit` field carries a `-dirty` suffix when the run was taken on a working
tree rather than on a commit, which is what a mid-milestone measurement always is.
A committed baseline should name a clean commit: measure again once the change is
committed, and commit the refreshed file on top.

**It moves deliberately, never incidentally.** A change that alters copper length,
via count or completion should update it in the same commit that makes the change,
and the delivery report or ADR should say why the new numbers are better. A
baseline quietly refreshed to make a red build go green is worse than no baseline.

## Two layers, and which one runs when

The corpus is minutes and the tripwire has to be seconds, so they are not the same
run:

| | what it routes | how long | when |
|---|---|---|---|
| `aipcb bench --smoke` | `congestion`, `led-blinker`, `routing-demo` | a handful of seconds | **every pull request**, in CI, against this baseline at a 400% runtime threshold |
| `aipcb bench` | the whole corpus, twelve boards | **minutes** | by hand on one machine, or nightly; this is what quality and performance work reports against |

**`examples/backplane` is in the full run only, and that is deliberate** (M19s). The
stress board is 82% of the corpus's routing time by itself — about two and a quarter
minutes — and putting it in front of every pull request would buy a slower signal of
the same thing. The smoke set is chosen for *shapes*: a tight board, an ordinary
board, and the one with declared sketches so the check stage does real work. It
catches an accidental quadratic and a moved board hash, which is what a per-PR
tripwire is for. It does not catch what only shows up under congestion, and it is
not asked to — that is the full run's job, and the full run is where a routing
change has to show its numbers anyway.

If the smoke set ever stops being fast enough to run without thinking about it, take
a board out rather than adding one.

## Everything else

`aipcb bench` writes `bench/results/<commit>.json` by default. Those are working
measurements — `.gitignore` keeps them out of the repository. Compare two of them
directly:

```
aipcb bench --out bench/results/before.json
# ... change something ...
aipcb bench --compare bench/results/before.json
```

## Reading the numbers

The two thresholds are asymmetric and the asymmetry is the point.

* **Copper length, via count, completion, and the board hash are deterministic.**
  The same input produces the same output, so any movement is a real change in
  what the router decided. `--length-threshold` defaults to 2%.
* **Wall clock is not.** `--runtime-threshold` defaults to 50% for two runs on one
  machine, and CI passes 400% because it is comparing against a file measured
  somewhere else entirely. That is enough to catch an accidental quadratic and
  useless for anything finer. Timing work worth trusting happens on one machine,
  by hand.

`over` in the human table counts over-subscribed cuts on the *routed* board. It is
pressure, not a defect: the congestion field is shared and approximate while the
stretcher is per-net and exact, so a cut over capacity on a board that is DRC-clean
and crossing-free means the coarse model was pessimistic there. A rising count
means the board got tighter, which is worth knowing when quality work claims to
have made room.

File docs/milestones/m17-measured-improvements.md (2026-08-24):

# Router improvements, part 2: the measured candidates (M17)

The M16 baseline turned the part-2 plan into a ranked list with numbers attached. This milestone implements the three candidates the baseline proved, each against the harness with a runtime budget, and rejects-with-numbers anything that doesn't pay. No literature research here — that is M18; this milestone spends only evidence that already exists.

## Session context (fresh session)

Read `docs/reports/m16.md` (the baseline table is the reference), the part-2 roadmap entry, and `docs/notes/toporouter-postmortem.md` §C. The M16 baseline in `bench/results/` is the judge: every change lands with a `bench --compare` against it, and the acceptance bar is stated per candidate below.

## M17a — Via minimization (the documented feast)

Baseline: 37 of 90 layer changes were made where no corridor was half full — over a third of vias are potentially unnecessary.

- Post-routing pass: for each layer change, test whether the route's topology admits staying on-layer within capacity (the special-cuts-corrected capacity check from M16a is the arbiter — this is why soundness came first); collapse the via pair where it does
- Deterministic, order-stable (process nets in canonical order), idempotent (second run finds nothing)
- Budget: runtime ≤ +10 % on the baseline corpus. Target: measurable via-count reduction on the boards behind the 37/90 number; report per-board before/after
- Controlled-impedance nets: excluded unless their class's rules still hold after collapse (verify, don't assume — a via removal changes the geometry M11e audited)

## M17b — Retrace elimination (E2's case as the acceptance test)

Baseline handed this one a named defect: pcie-sata GND U1.17→U1.49 travels 4 mm, hops layers for 0.55 mm, hops back, and retraces its own path — ~8 mm of copper and two vias for nothing.

- Detect and eliminate self-retracing and trivial out-and-back excursions in tightened routes (the E2 warning from M16b already detects; this makes the fix)
- Acceptance: the E2 case on pcie-sata resolves (warning gone, copper and via count drop by the measured waste), no example regresses on any bench metric, budget ≤ +5 % runtime
- The E2 warning stays in the suite as the guard that the fix keeps working

## M17c — Stretcher performance (where 83–94 % of the time lives)

Baseline: tightening dominates routing time on every large board; negotiation never exceeds 0.50 s. All speed work belongs here. This candidate is *engineering*, not research — the algorithmic question (is the stretcher asymptotically optimal or constant-slow?) belongs to M18; here, harvest the constant factors:

- Profile the stretcher on the two slowest boards (bench has the stage timing; add finer-grained profiling temporarily, remove before commit per the M16 guardrail about not perturbing measurements)
- Expected harvest, subject to the profile: redundant geometry recomputation across tightening iterations, shapely object churn, unnecessary re-tightening of unchanged nets (incrementality gaps), obvious vectorization
- Budget: this one *reduces* runtime — target a measured ≥ 25 % stretcher-time reduction on the slowest boards without any quality metric regressing (bench proves both). If the profile shows the time is genuinely irreducible constant work, report that finding honestly — it sharpens M18's question
- No algorithm replacement in this milestone; if the profile screams for one, write it into the M18 brief instead

## M17d — Update the extrapolation

Re-run the scaling fit (connections × triangulation size, the R² 0.97 line) after a–c land. The 900-connection ≈ 31 min extrapolation is the capability-ladder number; publish the new one in the report and update wherever the old number is cited.

## Rejection rule

Any candidate that misses its budget or regresses quality is rejected with its numbers recorded in the postmortem note's §C — the closure rule from M16d. A rejected candidate is a result, not a failure.

## Roadmap: M18 — the literature survey (documentation only, write the entry)

Write the M18 brief into the roadmap: a study session in the toporouter-postmortem style covering (1) tightening theory — the funnel algorithm (Hershberger–Snoeyink, minimum-length paths of a given homotopy class), Chazelle's linear-time techniques, TopoR/Eremex's published papers on arc-based tightening, and another attempt at Dayan's full thesis; (2) the negotiated-congestion lineage — BoxRouter, NTHU-Route 2.0, FastRoute 4.x, NCTU-GR and the ISPD-contest refinements, mined for cost-function techniques (low priority: negotiation is already < 0.5 s — this is quality research, not speed); (3) modern/ML routing surveyed for completeness with the standing hypothesis that non-determinism disqualifies it from the core, rejection documented like the evolution candidate. Deliverable shape: docs/notes/routing-literature.md, same discipline as the toporouter note — technique → aipcb component → expected gain → runtime risk → candidate or rejected-with-reason. Include M17c's profile findings as input: the survey should answer whatever question the profiling left open.

## Acceptance

- M17a: via reduction measured per board, budget held, idempotence tested, controlled-impedance exclusion tested
- M17b: E2 resolved, guard retained, no regressions, budget held
- M17c: ≥ 25 % stretcher-time reduction on the slowest boards or the honest irreducibility finding; no quality regression either way
- M17d: new extrapolation published
- Every change: bench --compare against the M16 baseline committed alongside, deterministic, byte-stable goldens (or updated with the diff explained — via/retrace removal legitimately changes copper; the explanation is the acceptance)
- Suite green, mypy strict, committed and pushed

## Guardrails

- The M16 baseline is the judge; no candidate lands without its compare
- No literature-derived techniques in this milestone — evidence that exists today only; new ideas go to the M18 brief
- Determinism, license wall, and fail-safe culture as always
- When in doubt, stop and report

## Delivery report (required, in-repo)

`docs/reports/m17.md`: per-candidate numbers against budget, the per-board via/retrace tables, the stretcher profile findings, the new scaling fit, any rejections with their numbers, and the updated baseline (re-baseline after landing, clearly marked as the new reference). Measured claims over asserted ones. Commit and push.

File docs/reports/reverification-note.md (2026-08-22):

# Which recorded measurements could have been taken on an accumulated board

M13.5 §1.4 found that `aipcb check` was not a function of its source. `check` routes
the board it builds and writes the copper into it; the next build into the same
`--out` directory read that copper back as a human's hand routing, preserved it, and
routed the design again on top. Copper accumulated on every repeat.

That is a defect in a *verification* tool, so the honest follow-up is not "it is
fixed" but **"which numbers in this repository could have come out of it"**. This
note answers that, and it is referenced from the M13.6 section of
[`m13.md`](m13.md).

## What it took to trigger

All three at once:

1. `aipcb check`, or `aipcb build` without `--fresh`, run **more than once**
2. into the **same output directory**, with the previous run's board still in it,
3. on a design the **router puts copper on** — the merge only kept `segment`, `via`
   and `zone` items, so a design with no routed copper and no declared zones was
   never affected.

A run into a fresh or temporary directory could not accumulate anything, and
`check` with no `--out` uses a temporary directory. So the exposure is narrower
than "every measurement ever taken": it is measurements read out of a *reused*
directory.

## What was re-measured, and what it says

`examples/pcie-sata`, checked three times into one directory on the fixed tree
(2026-08-22, KiCad 9.0.8, the same machine as M13 and M13.5):

| run | board SHA-256 | copper | routed | vias | DRC |
|---|---|---|---|---|---|
| 1 | `0e8f21b1…` | 1108.092 mm | 90 / 90 | 42 | 0 errors, 2 warnings |
| 2 | `0e8f21b1…` | 1108.092 mm | 90 / 90 | 42 | 0 errors, 2 warnings |
| 3 | `0e8f21b1…` | 1108.092 mm | 90 / 90 | 42 | 0 errors, 2 warnings |

Byte-identical boards, identical routing, identical violations — against the
pre-fix behaviour, which took the same design from 1108 mm to 1853 mm to 2462 mm
and invented a clearance error on run 2.

**The flagship board's published numbers are the same numbers.** 1108.1 mm, 90/90,
42 vias, 0 errors and 7 warnings is what M13 and M13.5 both recorded and what the
tool produces today. Those measurements were not taken on an accumulated board.

## What this note does not claim

It does not certify every figure in `m8.md` through `m13.md` one at a time. What it
establishes is the *shape* of the exposure and that the corpus figure most often
quoted is unaffected:

* **Superseded where they disagree.** Any copper length, routed count, via count or
  DRC count in an earlier report that disagrees with what the tool produces today
  should be read as the older number, and today's supersedes it. Nothing found so
  far disagrees.
* **The M13.5 §3 pour-gap measurement is the one that was visibly hit.** It is
  described in that section as crashing and then producing a board with three
  tracks on it no router drew; the measurement was retaken and the number it
  reports (0.1505 mm as built) is from a clean run.
* **Simulation results are not exposed through this path.** `aipcb simulate` routes
  into a temporary directory of its own and never reads the board back from
  `--out`; what it keeps there is slices and results. M13.6 added
  `tests/test_idempotence.py::TestSimulateIsAFunctionOfTheSource` to hold that.

## What now stops it coming back

| test | what it holds |
|---|---|
| `test_check_loop.py::…::test_checking_three_times_changes_nothing` | `check` on `usb-port`, three runs, board bytes and every routing and DRC number identical |
| `test_check_loop.py::…::test_checking_the_flagship_board_three_times_changes_nothing` | the same on `pcie-sata`, where the drift was measured (`AIPCB_FULL_CORPUS=1`) |
| `test_idempotence.py::TestBuildIsAFunctionOfTheSource` | `build` three times into one directory: the UUID guard keeps declared zones from doubling |
| `test_idempotence.py::TestExportIsAFunctionOfTheSource` | `export --build-dir` three times: same board, same fabrication package |
| `test_idempotence.py::TestSimulateIsAFunctionOfTheSource` | `simulate --dry-run` three times into one `--out`: same slice, same digest, same Gerbers |
| `test_idempotence.py::TestSyncPlacementIsAFunctionOfItsInputs` | a report run twice writes nothing and says the same thing twice |
| `test_idempotence.py::test_the_sweep_covers_every_command_that_writes_where_it_reads` | a twelfth command cannot join without an entry here |

The last one is the point. The defect class is *nobody ran it twice*, and the way
to keep closing it is to make a new command declare which side of the line it is
on.

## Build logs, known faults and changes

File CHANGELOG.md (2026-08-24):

# Changelog

Notable changes, newest first.

## Unreleased — M21, 2026-08-24

Assembly outputs: the two files an assembler needs, in three formats, with the
requirements researched from each fab rather than inferred from somebody's exporter.
See [`docs/reports/m21.md`](docs/reports/m21.md) and
[ADR 0015](docs/decisions/0015-assembly-outputs.md).

### Added

- **`aipcb export --bom`, `--cpl` and `--assembly`**, with `--format
  jlcpcb|pcbway|generic` (repeatable). Writes a bill of materials and a centroid
  file in the assembler's own column names, a **placement overlay per populated
  side**, and a zip of the package. The existing Gerber, drill, BOM and placement
  output is unchanged and byte-identical; the assembly files are additive and off
  unless asked for.
- **Procurement fields on a part**: `mpn`, `manufacturer`, `supplier_refs` (an
  open-ended per-supplier map, so the JLCPCB BOM fills its own column from
  `supplier_refs.lcsc`) and `assembly`. The older `supplier: {mpn, manufacturer}`
  spelling still validates; declaring one field both ways with different values is
  an error.
- **The placement overlay**, drawn from the centroid file's own rows rather than
  from the board — every part where the file puts it, turned the way the file turns
  it, with a dot marking where pin one lands after that rotation, and the bottom
  side mirrored. It exists because rotation conventions are where assembly orders go
  wrong and a file that says `180` looks exactly as ordinary as one that says `0`.
- **`tests/golden/pcie-sata/assembly/`** — the acceptance package, reviewed once by
  hand and then guarded by a test, so a changed column or a moved rotation shows up
  as the diff an assembler would have received.

### Changed

- **`assembly:` is measured when it is not declared**, off the footprint's own
  attributes and pad types, rather than defaulting to `smt` as the milestone
  proposed. Four bundled examples are built around through-hole parts and PCBWay's
  centroid file is documented as surface-mount only, so the default would have put
  all of them in a file that must not contain them — silently, in the file whose job
  is to be checked. A fourth value, `none`, was added for footprints that are not
  components at all: `examples/pcie-sata`'s card-edge fingers and `enclosure`'s
  mounting holes used to appear on the bill as lines nobody can source.
- **The bill of materials is driven by the netlist, not by the placement file.**
  A footprint KiCad excludes from position files used to vanish from the order
  entirely, which is right for a card edge and catastrophic for a battery holder.

### Not done, and the reason is not the tooling

- **`examples/pcie-sata` cannot export a complete order.** Seven of its eleven
  placed parts have no manufacturer part number: six capacitors, which are a
  procurement decision nobody has made and which this milestone would not invent,
  and **the SATA controller, which cannot have one** — its symbol is a borrowed
  generic connector, its pinout is this board's own invention and its power
  architecture is scenery, as the library has said since M11. A part number written
  there would be a number an assembler could order and a component that could not
  work. The fab round's tooling blocker is gone; the design blocker is in
  [`docs/reports/m21.md`](docs/reports/m21.md) §6 with three ways forward.
- **No rotation-correction table ships.** The documented convention — degrees,
  counter-clockwise positive — is implemented exactly and needs no transform. The
  per-package *correction* is published by neither fab, is a hand-maintained lookup
  in the community tooling that solves it, and is not even a function of the
  footprint. The overlay is the verification instead. ADR 0015 §4.
- **Two-sided assembly is refused rather than approximated**: `side: back` validates,
  warns and places on the front, so an assembly export on such a board errors and
  names the parts.

## Unreleased — M19, 2026-08-24

Part 3 of the toporouter work. M18 found that the tightening *algorithm* is 0.039
profiled seconds of a 30-second route and that what the `tighten` stage actually
spends its time on is building — and discarding — the geometry tightening is done
against. This milestone builds the board that work should be measured on, then takes
the two cheap candidates the survey ranked. **Two of the four missed their budgets
and the report says so rather than re-reading the rule.** See
[`docs/reports/m19.md`](docs/reports/m19.md).

### Added

- **`examples/backplane` — the congestion stress board** (M19s), and the first
  example in this repository that does not finish for a reason that is arithmetic
  rather than topology. A six-slot instrument backplane whose card guides leave a
  4.0 mm channel between adjacent card positions: sixteen bus lines at 0.45 mm plus
  the rail and the return at 0.6 mm each put **8.4 mm of demand on a cut the two
  signal layers score at 7.6 mm**, seven times over. 168 connections, 110 routed,
  **58 handed over with the cut that stopped each one named**, five negotiation
  iterations without converging. **The router's capacity arbiter fires for the first
  time** — 132 refusals, the worst cut 3.77 mm of B.Cu against eleven nets wanting
  4.95 mm — where M17a found not one span rejected on capacity across the whole
  corpus. Byte-stable, DRC-clean on what it routes, and registered in
  `UNROUTABLE_EXAMPLES` because it was built to be over capacity.
- **`CONN_HDR_1X20`** in `examples/library/connectors.yaml` — a 20-pin single-row
  2.54 mm header.
- **`tests/test_routing.py::TestPointLocation`** — the vectorised candidate test
  against the scalar loop it replaced, on shared edges, shared vertices, swapped
  triangle indices and a real board's whole triangulation.

### Changed

- **`Triangulation.locate_many` computes its point-in-triangle test over numpy
  arrays** (M19a), where M17c had batched the R-tree query and left a scalar loop
  calling `_inside` 3 140 252 times and `_sign` 9 426 354 times on one board. Same
  arithmetic in the same order, so the signs are bit-identical; the tie-break —
  lowest triangle index wins — is written explicitly rather than hoped for.
  `_via_sites` 12.37 → 5.22 s and `_repair` 16.34 → 9.76 s profiled on
  `examples/pcie-sata`. **Every board hash is byte-identical.**
- **The corpus grew from eleven boards to twelve** and the baseline moved twice, in
  its own commit each time: 29.476 s of routing over eleven boards, then 167.036 s
  over twelve with `backplane` at 82 % of it, then 161.798 s after M19a. Copper,
  vias, layer changes and completion are unchanged on every original board
  throughout.
- **The capability-ladder extrapolation more than doubles, and that is the twelfth
  board rather than a regression** (M19d). Over the eleven original boards the
  exponents did not move again — 1.70 → 1.67 against connections, 1.10 → 1.09
  against connections × cuts — but the eleven-board fit under-predicts `backplane`
  by a factor of 3.9, and refitting over all twelve gives 1.87 and 1.03 and a
  900-connection estimate of **22.5 minutes** against M17's 11.3. The old number was
  fitted entirely below the range it was being used to predict; the new one is
  fitted through exactly one point above it, so it travels with that caveat
  attached and is provisional until the curve has more points between 90 and 900
  connections.

### Documented

- **Budgets re-anchor after every landed candidate** — a new standing rule in
  [`CLAUDE.md`](CLAUDE.md#budgets-re-anchor-after-every-landed-candidate), written
  because M19's two misses were both budget-anchoring failures rather than technique
  failures. Each candidate is measured against HEAD at its own start, and a budget
  that targets a specific cost is quoted in absolute seconds on named functions
  rather than as a percentage of a corpus the same milestone may change.
- **The benchmark's two layers**, in [`bench/results/README.md`](bench/results/README.md):
  the CI smoke run stays three boards and a handful of seconds, and `backplane` is
  in the full run only, because a tripwire nobody runs is not a tripwire.

### Not done, deliberately

- **M19a missed its 10 % budget** — it lands 2.9 % of the corpus and 8.3 % of the
  eleven boards the budget was drafted against — because `backplane` landed first
  and spends its time in `triangulate_free`, not in point location. The code is kept
  and [`docs/reports/m19.md`](docs/reports/m19.md) §2.3 flags that as a decision
  rather than a rule.
- **M19b was built, measured and rejected.** Bounding the private repair field lands
  1.0 % of the corpus against a 25 % budget, and it moves `pcie-sata`'s copper by
  12.5 mm — so the premise on which it was scheduled ahead of the fab round did not
  hold. Reverted; the design and the numbers are in
  [`docs/notes/routing-literature.md` §6](docs/notes/routing-literature.md#6-measured-results-as-the-closure-rule-requires).
  The finding worth carrying: **M19a and M19b were priced additively off one profile
  and they overlapped**, and a bounded search does not fail when its box is too
  small — it succeeds with something absurd.
- **M19c is not started.** Its gate opens on the measurement, and the stress board's
  profile says its prize is *larger* than the survey priced it: **64 % of
  `backplane`'s routing time is `triangulate_free`** and 39 % is one GEOS call
  inside it. The sequencing rule puts it after the fab round, and that has not
  happened.

## Unreleased — M17, 2026-08-24

Part 2 of the toporouter work: the three candidates the M16 baseline had already
ranked, each with a runtime budget stated before it was built and each landed
against `aipcb bench --compare`. No literature-derived techniques — those are M18.
See [`docs/reports/m17.md`](docs/reports/m17.md).

### Added

- **A via-reclaiming post-pass** (`route/tidy.py`). Every span where a connection
  leaves a layer and comes back to it, and every connection whose two pads share a
  layer, is re-tightened as a single leg and kept only if it comes out with **fewer
  vias and no more copper** — with M16a's special-cuts-corrected cut model as the
  congestion arbiter. Deterministic, order-stable and idempotent. Controlled-impedance
  classes and coupled pair legs are excluded by class, because a via removal changes
  the geometry M11d and M11e measured. Reported in `route all --json` as
  `routing.reclaimed`, and timed as a `reclaim` stage in `aipcb bench`.
- **`Triangulation.locate_many`** — the same answer as `locate` for a list of points,
  in one R-tree query.
- **`RoutedConnection.open_pads`** — which pads a connection was tightened against,
  recorded rather than re-derived, so a later pass re-tightens it in the same free
  space the router used.

### Changed

- **The router is roughly twice as fast, with every board's output unchanged.**
  Corpus `router_seconds` 61.9 → 29.9; tightening time −55.5% on `examples/pcie-sata`
  and −52.3% on `examples/mcu-4layer`. The profile found that two thirds of the
  "tightening" time was the *field builder*, rebuilt per repaired connection, and
  inside it a scalar Shapely loop over candidate via sites: 1.9 million `Point`
  constructions and 854 000 boundary derivations on one board. Those calls are now
  batched, `inflate` is memoised, and each layer's geometry is built once per
  connection rather than once per leg. No algorithm changed; all eleven board hashes
  were identical at this point.
- **`examples/pcie-sata` carries four fewer vias and 30.285 mm less copper**, and the
  `route-doubles-back` warning M16b found on it is gone. GND's `U1.17>U1.49` used to
  travel four millimetres, hop to B.Cu for half a millimetre, hop back and retrace
  its own path home; it is now a single 3.519 mm leg. The M16b guard is retained with
  its assertion inverted, and `route-doubles-back` is removed from the check loop's
  known issues rather than silenced.
- **`bench/results/baseline.json` moves to this milestone's commit.** Less copper,
  fewer vias, one fewer self-crossing, half the runtime; the M16 file stays in git
  history and every figure it is compared against is in the M17 report.

### Fixed

- **The 900-connection extrapolation.** Re-fitted after the above: roughly 11.3
  minutes where the same method on the M16 baseline gives 23.7. The exponents did not
  move (1.72 → 1.70 against connections, R² 0.94), which is the point — M17 harvested
  constant factors and left the shape of the curve for M18 to ask about.

## Unreleased — M16, 2026-08-23

Part 1 of what the [gEDA toporouter postmortem](docs/notes/toporouter-postmortem.md)
recommended: the guards and the instrument. None of the quality techniques, on
purpose — the study's central finding is that runtime, not correctness, is what
killed that router, and three of the five techniques trade runtime for quality.
See [`docs/reports/m16.md`](docs/reports/m16.md).

### Added

- **`aipcb bench`** — routes every bundled example and records wall clock per stage,
  completion, copper length, vias and layer changes against a computed lower bound,
  corridor utilization and headroom per layer, layer changes made without capacity
  pressure, and a hash of the board. `--compare` diffs two runs and exits 1 on a
  regression; `--smoke` runs the three-example CI subset.
  `bench/results/baseline.json` is the committed reference.
- **Second-diagonal ("special") cuts in the capacity check.** `check_capacity` now
  charges the other diagonal of every convex adjacent triangle pair — the cut a wire
  crosses when it rounds a triangle's apex without ever touching the diagonal.
  Measured at 4–29% of diagonals per layer having a shorter partner, so this is
  ordinary geometry rather than a corner case. [ADR
  0014](docs/decisions/0014-special-cuts.md). The router's own cost model is
  deliberately *not* charged for them; that is a measured trade for part 2.
- **A self-crossing invariant.** `route/invariant.py` now asks whether one
  connection's copper meets its own: `route-crosses-itself` (error) for a leg whose
  polyline is not simple, `route-doubles-back` (warning) for two legs of a
  connection meeting on one layer away from a join. It found a real one on
  `examples/pcie-sata` the day it landed — a GND connection laying eight millimetres
  of copper and two vias twice over. Reported in `route all --json` as
  `routing.self_crossings`.
- **A dated scale-robustness measurement.** `examples/led-blinker` produces identical
  copper at board origins of 100 mm, 2 147 mm and 50 000 mm, and routes differently
  at 100 000 mm — on Shapely 2.1.2 / GEOS 3.13.1. KiCad's whole coordinate range is
  ±2 147 mm, so the router is exact across twenty-three times it. The test holds both
  halves.
- **A CI `bench` job**, routing the smoke subset against the committed baseline on
  every pull request.
- **A part-2 plan in the roadmap**, with a runtime budget per candidate and the rule
  that a candidate which does not pay for itself is rejected *with its numbers
  recorded in the postmortem note*.

### Changed

- **The capacity check no longer claims more than it delivers.** `field.py`,
  `check_capacity` and [`docs/topology.md`](docs/topology.md) now say that the cut
  set is a **lower bound on congestion, not Maley's criterion in full**: a clean
  result is evidence, not proof. This was worth doing independently of charging the
  new cuts, and would have been done either way.

## Unreleased — M15.1, 2026-08-23

### Changed

- **The README and `docs/README.md` now state maturity per area instead of
  presenting the whole tool at one level.** The stable core leads — the source
  format and deterministic compilation, verification against real KiCad and the
  three invariants guarding it, schematic generation, and manual-layout support —
  followed by a maturity table and a plainly-marked beta tier. Nothing about the
  tool changed; what changed is that the page no longer implies that autorouting
  is as proven as the format under it.
- **`aipcb route` prints a one-line beta notice** on invocation, to stderr, with a
  link to the graduation conditions. Suppressed under `--json`: a machine consumer
  reads the same fact from the new `maturity` field instead.

### Added

- **`maturity: "beta"` in the `aipcb route --json` report** (`routing.maturity` for
  `route all`, `routes.maturity` for `route check`), so an agent reading the report
  can see the label structurally rather than parsing prose for it. No other key
  changed, added or moved; `tests/test_routing.py::TestBetaNotice` pins that.
- **Graduation conditions** for both beta labels, in
  [`docs/roadmap.md`](docs/roadmap.md#maturity-and-graduation): what has to be
  measured for each to come off, so that the label is a plan rather than a stamp.
- **A `Placement` section in the roadmap**, naming placement quality as the next
  obvious gap and why it matters to the router's own graduation.

## v0.1.0 — unreleased, tag pending

The first public version: the source format, deterministic compilation to KiCad 9,
ERC/DRC verification, schematic generation, topological autorouting, copper pours,
openEMS-backed SI simulation, and fabrication export — built across fifteen
milestones, each with a delivery report in [`docs/reports/`](docs/reports/).

**Not everything in it is at the same maturity**, and the tag should not be read as
saying otherwise. See the [maturity table](README.md#maturity-at-a-glance): the
format, compilation, `check` and schematics are stable; autorouting and SI
simulation are beta; the Freerouting bridge is new. `docs/reports/m15.md` records
what was measured before the repository was made public, including what the
measurements found that nobody was looking for.

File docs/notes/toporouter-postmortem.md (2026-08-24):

# The gEDA toporouter: a postmortem

A study note. Nothing in `src/` changed in the session that produced it.

gEDA PCB's *toporouter* is the only complete, shipped, open-source implementation of
rubber-band topological routing that exists to read. It was written by Anthony Blake
in 2008–2009 — a Google Summer of Code project mentored by DJ Delorie — from Tal
Dayan's 1997 UC Santa Cruz PhD thesis, on top of the GTS constrained-Delaunay
library. It is the closest code-level ancestor aipcb's stretcher has. It also failed:
it was never finished, it was broken by an unrelated refactor in 2011 and never
repaired, it was called "redundant (and abandoned)" by its own project by 2015, and
neither of PCB's successors carried it forward.

Both halves are worth having. The techniques are free, and so is the autopsy.

---

## The licence wall

**gEDA PCB is GPL-2.0. aipcb is Apache-2.0. Study, never copy.**

Algorithms, ideas and lessons are not copyrightable and are fair game. Code,
comments, and line-by-line translations of code are not. Everything below is stated
in this note's own words and diagrams. Identifiers (`check_speccut`,
`oproute_rubberband_segment`, `src/toporouter.c`) appear only as *addresses* — so a
reader can find the thing being described — never as transcribed source.

Any future implementation of a technique named here is written **from this note and
from the academic sources**, not from the GPL file. If a candidate in [§C](#c-candidates)
is ever built, that provenance goes in its milestone prompt.

---

## Sources, and what could not be got

| Source | Status |
|---|---|
| Dayan, *Rubber-band based topological router*, PhD thesis, UCSC, 1997 | **Obtained in full at M18 — see [`routing-literature.md` §1.3](routing-literature.md#13-dayans-thesis-obtained--what-the-second-hand-markers-got-right-and-wrong).** The status below was true when this note was written and is left standing so the second attempt's result is legible; every claim in this note marked as second-hand should now be read against that section, which resolves them. In particular the thesis's shortest-path algorithm is *O*((T+S)² log(T+S)) with the shipping approximation at *O*((T+S) log(T+S)) and **not guaranteed shortest**; and §2.2.1 says SURF maintained each layer's mesh with an incremental constrained Delaunay triangulation. Original status: **Not obtained in full text.** No open PDF exists; ProQuest and Google Books carry metadata and an abstract only. Its content is cited here at second hand — through the SURF papers' abstracts, through Blake's own account of what he implemented, and through the bibliography the toporouter source itself carries. **Claims below about "what the thesis prescribes" are therefore weaker than claims about what the code does, and are marked where they appear.** |
| Dai, Dayan & Staepelaere, *Topological Routing in SURF: Generating a Rubber-Band Sketch*, DAC 1991; Staepelaere et al., *SURF*, IEEE D&T 1993; Dayan & Dai, *Layer Assignment for a Rubber Band Router*, UCSC-CRL-92-50 | Abstracts only; full texts paywalled. |
| `src/toporouter.c` (7,761 lines) and `src/toporouter.h` (484 lines), [russdill/pcb](https://github.com/russdill/pcb) | **Read in full for architecture and technique.** The primary source for §A. |
| Blake's own project page, `anthonix.resnet.scms.waikato.ac.nz/toporouter/`, last updated 2009-07-07 | **Recovered from the Internet Archive** (mirrored into the [bert/pcb wiki](https://github.com/bert/pcb/wiki/Autorouters:-gEDA-pcb-Toporouter)). This is the richest single source: benchmark tables, honest self-assessment, and the "why I restarted" statement. |
| The commit history of `src/toporouter.c` (69 commits, 2009-04-22 → 2011-12-24) | Read via the GitHub API. The maintenance story in §B.4 is read straight off it. |
| [Launchpad bug #846789](https://bugs.launchpad.net/pcb/+bug/846789), "toporouter broken" | Read. The proximate cause of death. |
| gEDA-user threads: [Apr-2010 "Toporouter Problems"](http://archives.seul.org/geda/user/Apr-2010/msg00244.html), [Sep-2011 "howto toporoute?"](http://archives.seul.org/geda/user/Sep-2011/msg00337.html), [Feb-2011 "What stops PCB autorouter/toporouter from working right?"](https://archives.seul.org/geda/user/Feb-2011/msg00488.html), [geda-dev GSoC announcement thread](https://geda-dev.seul.narkive.com/gWNGZKO5/gsoc-project-topological-autorouter) | Read. |
| narkive mirrors of "Toporouter update?" and "Toporouter VERY slow?" | **Unavailable** — both returned 5xx. The seul.org archive covered the same ground, so the gap is not believed to be material. |
| A written rationale from pcb-rnd for not porting the toporouter | **Not found.** pcb-rnd forked in 2013 and its Ringdove suite ships `route-rnd` plus a Specctra DSN bridge to Freerouting instead; no document was located stating *why* the toporouter was not carried over. Recorded as a gap rather than guessed at. |

**One attribution correction, because it is easy to get wrong.** The Feb-2011
gEDA-user thread that opens "what stops PCB autorouter/toporouter from working right"
carries a valgrind trace — an invalid 8-byte write in `heap_insert()`, ~2.3 GB
allocated, 1.76 M allocations against 268 k frees, SIGSEGV — reached through
`BreakManyEdges()`. **That call chain is PCB's maze autorouter (`autoroute.c`), not
the toporouter.** It is not evidence about the toporouter and is not used as such
here. The two routers were routinely discussed in one breath, and the record is
polluted accordingly.

---

## 0. What it was

```
 PCB board data                                                   PCB tracks + arcs
      |                                                                   ^
      v                                                                   |
 [import geometry] -> [CDT per layer group] -> [A* over CDT] -> [rubber-band export]
   pads, pins,          GTS constrained         "topological       "curvilinear
   vias, board          Delaunay; obstacle       sketch": an        wiring": tangent
   edge, existing       outlines become         ordered list of     lines and arcs
   lines                *constraint* edges      cut crossings       hugging obstacles
                                                      |
                                                      v
                                        [ROAR / RUBIX / detour rip-up loops]
```

Two representations, and the split is the whole design. A **topological sketch** is
the ordered sequence of triangulation edges a wire crosses — no coordinates, no
lengths, just which side of what. **Curvilinear wiring** is the geometry you get by
pulling that sketch taut. Routing happens entirely in the first; only at the very end
is the second computed. That is precisely aipcb's split between
[`negotiate.py`](../../src/aipcb/route/negotiate.py) ("negotiation is symbolic") and
[`stretch.py`](../../src/aipcb/route/stretch.py) ("topology in, DRC-clean geometry
out"), arrived at independently and recorded in
[ADR 0006](../decisions/0006-routing-approach.md).

Timeline, from the commit log and Blake's page:

| | |
|---|---|
| 2008 | GSoC project. First implementation. Routed simple boards; supported vias. |
| 2009-04-22 | **A second implementation, from scratch, is merged.** Blake's stated reason: rather than stabilise and document the first attempt, he judged his time better spent starting over — PCB already had "a highly optimized and efficient autorouter" and he doubted the first version could beat it. |
| 2009-06-10 → 2009-07-07 | The productive burst: one-pass curvilinear wiring, multiple traces per constraint edge, ROAR rip-up, a rewrite of the cluster and "speccut" code, detour optimisation. |
| 2009-07-07 | Last update to the project page. **Vias are off** — the rewrite's CDT never regained via support. |
| 2009-12-21 → 2010-03-21 | Four more commits from the author. Then nothing, ever again. |
| 2010-04 → 2011-12 | Thirty-odd commits from five other people. **Not one is algorithmic**: compiler warnings, C++ compatibility, `bool`, unit conversion, API churn, dead-code removal. |
| 2011-09-10 | Bug #846789: the toporouter hangs on a two-resistor board. |
| 2015 | Recorded in the project's own wiki as "generally considered to be redundant (and abandoned)". |

---

## A. Techniques worth learning

### A.1 Spreading — the one aipcb has no general mechanism for

The toporouter carries **two distinct passes** that push wires apart inside a
corridor, and the distinction between them is the useful part.

*Spacing* (`space_edge`) is a **force relaxation** run on the wires crossing a single
triangulation edge. Each crossing point feels a repulsion from its two neighbours in
the crossing order — and from the edge's own endpoints, so obstacles push too —
proportional to how much the required minimum spacing exceeds the actual gap. Points
move by a tenth of the residual per step; the loop runs to equilibrium, or **gives up
after a hundred iterations**, whichever is first. It is a legality repair: it only
pushes when something is *too close*.

*Spreading* (`spread_edge`) is different and much simpler. It ignores forces
entirely and **distributes the crossings evenly along the edge**: *n* wires on an
edge of length *L* land at *L*/(*n*+1) intervals, and a single wire lands at the
midpoint. It is a quality pass, and it runs whether or not anything was too close.

```
 obstacle A                                obstacle A
 ==========                                ==========
  ###                                        #
  ###   <- three tracks hugging               #      <- same three, spread
  ###      the inflated hull                   #        across the same gap
                                                #
                                               #
 ==========                                ==========
 obstacle B                                obstacle B
```

**Against aipcb.** aipcb's [funnel](../../src/aipcb/route/funnel.py) returns the
*shortest* path through the sleeve, which by definition hugs the inflated hulls. A
track therefore runs at exactly minimum clearance from every pad it passes, even
where three millimetres of free space sit unused on the other side. There is one
exception and it is narrow: **M11d rule 1**, the standoff corridor, tightens a
controlled-impedance pair's centre-line against `clearance × standoff_k` rather than
`clearance` ([ADR 0010](../decisions/0010-highspeed.md)). That widens the corridor
*for one class of net* by inflating obstacles more; it does not distribute anything,
and every other net still hugs.

The general mechanism is missing, and `spread_edge`'s form suggests it need not be
expensive: aipcb already knows, for every cut, exactly which routes cross it
(`RoutePath.crossings()` and `LayerField.used`), which is the same information
`spread_edge` operates on. **This is [candidate C1](#c1-a-spreading-pass).**

Blake's own framing is worth keeping: spreading is not cosmetic. Evenly distributed
wiring is what leaves room for the *next* net, which is why the pass runs during
routing and not only at the end.

### A.2 Vias — and the negative lesson

The toporouter's via model is startlingly thin, and the reason matters more than the
mechanism.

* Every pin and via is inserted as a vertex and an obstacle into **every layer
  group's** triangulation, independently. There is no object representing "a hole
  through the board" — there are *N* coincident 2-D obstacles that happen to share
  an (x, y).
* A route changes layer by walking onto a vertex that exists on both layers and
  continuing on the other layer's triangulation. The A* heuristic adds a flat
  `viacost` (default 100 mil expressed as distance) when the current and destination
  layers differ, and `path_score` charges the same per layer change.
* **The router cannot create a via.** It can only reuse a through-hole that the board
  already had. Blind and buried vias do not exist in the model at all.
* Fanout — pad to a fresh via — is a *separate, manual, non-topological* action
  (`escape`), which drops vias at fixed offsets from selected pads by pin pitch and
  draws the stub itself.
* And in the shipping rewrite, **vias were switched off entirely**. Blake's benchmark
  page says so in as many words: the new code "still requires work on the CDT to
  support my plans", so every published result is single-layer.

**Against aipcb.** The [via column](../../src/aipcb/route/field.py) is a strictly
better model and it is worth saying why in the toporouter's own terms: a via node is
one object, it is an obstacle on *every* layer its barrel pierces whether or not it
carries signal there, and it *joins* the layers' triangulations rather than being
independently rediscovered on each. aipcb's router places its own vias, prices them
through the cost model, bounds them per connection (`max_vias`), and M11c generates
matched pair transitions with return vias as a pattern.

The lesson is not in the mechanism, it is in the sequencing: **the toporouter's
rewrite shipped without the capability its predecessor had, and never got it back.**
It also anticipated aipcb's own answer to fan-out — a deterministic *pattern
generator* that runs before routing and hands the router fixed obstacles plus
terminals, which is exactly what M9e's `fanout.py` is. `escape` is that idea in
embryo, minus the determinism and minus the integration.

### A.3 The tightening

This is where the two projects differ most, and where the toporouter's history is
most instructive.

**What it does.** Given a path as a sequence of crossing points, `oproute_rubberband_segment`
works on one straight segment at a time between two anchors (a terminal, or a
previously-inserted arc):

1. For every triangulation vertex the path passes, compute how far that vertex
   *pushes* the segment — the violation depth, given the wire's own half-width and
   keepaway. Two cases are distinguished: the vertex's edge cuts across the segment,
   or it lies wholly to one side.
2. Take the **single largest violation**, and insert an **arc** of the required
   radius wrapping that vertex, with a winding direction.
3. **Recurse** on the two sub-segments either side of the new arc.
4. On unwind, look at the joint between the new arc and its neighbours, and delete a
   neighbouring arc if the tangent construction says it has become redundant.
5. Finally, walk the whole finished route and delete any arc whose entry and exit
   tangents cross each other — a **loop**. The loop check restarts from the beginning
   of the route each time it deletes something.

The output is genuine **curvilinear wiring**: straight tangent lines joined by arcs
that hug obstacle vertices at exactly the legal radius. It is the most faithful
rendering of "rubber band" anything in the open-source record.

**What the thesis prescribes** — *stated at second hand; the thesis was not
obtained.* The SURF line of work describes the rubber-band sketch as a
*representation* with well-defined geometric transformations, and Dayan's abstract
claims a proof of correctness for a shortest-path algorithm over it. The toporouter's
tightener carries no such proof, has no termination argument, and its own author
described the file as experimental and undocumented in its header comment. **This gap
— between an algorithm with a correctness proof in a thesis and a
maximum-violation-plus-recursion heuristic in the shipped code — is where the
toporouter's worst bugs lived.** §B.1 has the evidence.

**Against aipcb.** aipcb tightens with the [funnel algorithm](../../src/aipcb/route/funnel.py)
(Tompa 1981; Chazelle 1982; Lee & Preparata 1984; Leiserson & Maley 1985) over a
sleeve of triangles. The differences are not stylistic:

| | toporouter | aipcb |
|---|---|---|
| Input | a path through vertices | a sleeve of triangles (the homotopy class) |
| Method | insert the max-violation arc, recurse | one linear sweep, apex + two concave chains |
| Termination | no argument; delete-and-restart loops | provably linear in sleeve length |
| Result is simple (non-self-crossing) | **not guaranteed** — hence the loop checks | by construction: the shortest path in a simple polygon is simple |
| Clearance | applied *during* tightening, per obstacle, from wire width and keepaway | applied *before* triangulating, by inflating obstacles |
| Output | tangent lines + arcs | polyline, mitred |
| Determinism | claimed; results shifted under small parameter changes | tested (`test_stretching_is_deterministic`, `test_routing_is_byte_stable`) |

The row that matters most is **clearance**. The toporouter carries the wire's width
and keepaway all the way into the geometry pass, and asks at every step "does this
violate?". aipcb inflates the obstacles first, so the shortest path through what is
left is *legal by construction* — there is no violation to detect, and therefore no
violation-detection bug to have. That single decision retires most of §B.1.

### A.4 Ordering and rip-up

Four mechanisms, layered:

* **RUBIX** — a first pass in a greedy order. The order comes from a pairwise
  scoring: each unrouted net is routed alone against an empty board, then scored
  against every other net's solo route by how much they conflict, and the resulting
  matrix is reduced to a sequence.
* **ROAR** (rip-up-and-reroute) — route a net *allowing it to conflict*, then rip up
  everything it conflicted with and re-route those. Failures during recovery are
  counted, and past a threshold the whole attempt is **rolled back** to a checkpoint.
  It runs up to six passes, alternating a threshold of 2 and 5, and stops when the
  failure count stops falling.
* **Least-invalid search** — during a ROAR route the A* cost function is switched into
  a mode where crossing another net is not forbidden but *priced*, at the conflicting
  route's own score, scaled by the square of the number of conflicts so far.
* **Detour optimisation** — the most interesting one. After congestion has settled,
  score every *routed* net by how much its realised length exceeds its
  detour-free length. Sort descending. For each net whose excess exceeds a threshold,
  rip it up and re-route it, keeping the result only if it improved. Stop at the
  first net under the threshold.

**Against aipcb.** [Negotiated congestion](../../src/aipcb/route/negotiate.py)
(PathFinder, McMurchie & Ebeling 1995) is a better answer to the *first three*.
Priority plus difficulty orders the first pass; every net routes every iteration;
over-subscribed cuts get more expensive; a history term stops two nets swapping a
corridor forever; the loop has an iteration cap and a patience counter and reports
loudly when it does not converge. Where ROAR does explicit checkpoint/rollback with
hand-tuned thresholds, aipcb subtracts a demand from a cut and moves on. This is the
clearer design and it should stay.

**The fourth has no aipcb counterpart at all.** aipcb's negotiation converges on
*legality* — no cut over-subscribed — and then stops. Nothing afterwards asks whether
a route that is legal is also *good*. Blake measured what that pass is worth, and the
numbers are the best-evidenced result in the entire record:

| Board | Nets | Wiring length before | after detour opt | best |
|---|---|---|---|---|
| Flare Genesis | 123 | 52.79 in | 49.32 in | **47.99 in** (−9.1%) |
| Meggy Jr RGB | 158 | 190.87 in | 188.73 in | **160.08 in** (−16.1%) |
| Test | 11 | 8.97 in | **8.32 in** (−7.3%) | — |

For 15–30% more runtime. **This is [candidate C3](#c3-a-detour-pass--rejected-at-m19).**

### A.5 Clusters — routing to a net, not to a pad

A net is imported as a **cluster** of terminals, not a list of pads. A connection is
a *cluster-to-cluster* problem: the A* seeds its open list with every vertex of the
source cluster and terminates on *any* vertex of the destination cluster. And when a
connection completes, the two clusters are **merged**. The next connection of that net
therefore targets everything already connected, not a pad chosen in advance.

**Against aipcb.** [`spanning_routes`](../../src/aipcb/route/plan.py) fixes a
Euclidean minimum spanning tree over pad centres *before anything is routed*, and
every connection is then a fixed pad-to-pad problem. Blake named the same choice as a
limitation of his own first implementation in his GSoC wrap-up — that results could be
improved "through topologies other than Euclidean minimum spanning tree" — and the
cluster merge is what he built instead.

There is a second reason to care, and it is specific to a known aipcb defect. Because
a net's own copper cannot be an obstacle (or two connections of a net could never
meet), a later connection happily runs the length of an earlier one before branching,
and where the two finally diverge they leave a wedge KiCad reports as a
`copper_sliver`. aipcb handles this **after the fact**, by trimming
(`_join_existing_copper`); `examples/diff-pair` still carries one on the unfilled
board and `tests/test_check_loop.py` records it as a named known issue. Cluster
merging removes the cause instead of the symptom: a route that targets the whole
existing net ends *where it first reaches it*, and there is nothing to trim. **This
is [candidate C4](#c4-route-to-the-net-not-to-the-pad).**

### A.6 Special cuts — the technique aipcb most clearly lacks

This is the find of the study, and it is a soundness issue rather than a quality one.

Both routers rest on **Maley's realizability criterion**: a set of topologies can be
turned into legal geometry exactly when no *cut* across the free space is
over-subscribed. aipcb states this in [`field.py`](../../src/aipcb/route/field.py) and
implements it as: *every interior edge of the triangulation is a cut*, capacity is
the diagonal's length plus one clearance, and each route crossing it consumes its own
width plus its clearance.

**But the triangulation's edges are not all the cuts.** Blake hit this, named the
missing ones *special cuts*, and rewrote the code around them in July 2009. The
construction:

```
        opv                                opv
        / \                                /|\
       /   \                              / | \
    e1/     \e2                          /  |  \
     /   t   \                          /   |   \
    /         \                        /    |    \
  v1-----e-----v2      the cut that   v1    |    v2     <-- e, the CDT diagonal,
    \         /        actually binds   \   |   /           is NOT the binding
     \  opt  /         is opv--opv2      \  |  /            constraint here
      \     /                             \ | /
       \   /                               \|/
        opv2                               opv2
```

Two triangles `t` and `opt` share the diagonal `e`. A wire entering `t` through `e1`
and leaving through `e2` never crosses `e` at all — but it must physically round the
apex `opv2` of the *opposite* triangle, and the room available to do that is the
perpendicular distance from `opv2` to `e`. When the wiring that has to round `opv2`
exceeds that height, the real constraint is the **other diagonal of the quadrilateral**,
`opv–opv2` — a segment the constrained Delaunay triangulation did not choose and
therefore never charges. The toporouter detects the condition and **synthesises the
missing edge on the fly**, migrating the relevant crossings onto it.

**Against aipcb.** aipcb charges CDT diagonals and nothing else. The flip diagonal of
every adjacent triangle pair is a cut it never considers, and so is any other segment
between two obstacle vertices. `check_capacity` in
[`check.py`](../../src/aipcb/route/check.py) is therefore **optimistic**: it can pass
a board that Maley's criterion rejects.

How bad is that in practice? Less bad than it sounds, and the reason is aipcb's
architecture rather than any guard: the stretcher is *constructive*, it tightens each
route against inflated obstacles that include all previously finished copper, and
[`check_no_crossings`](../../src/aipcb/route/invariant.py) asks the finished board
whether any two nets overlap. So an under-counted cut does not ship a short circuit —
it shows up as a route that fails, or one that takes an absurd detour, in a place the
capacity report said was fine. **Exposed on completeness and diagnosis, guarded on
legality.** [Candidate C2](#c2-flip-diagonal-cuts), and [flagged exposure E1](#e1-the-capacity-model-under-counts-cuts).

### A.7 Other things it has that aipcb does not

* **Ordered, pairwise capacity accounting.** The toporouter computes a cut's
  occupancy by walking the crossings *in their order along the cut* and summing the
  pairwise minimum spacing of each adjacent pair, including the cut's own endpoints,
  with a special case for the wire that terminates there. aipcb sums `width + clearance`
  per route, order-independently. For a straight cut with uniform net classes the two
  agree exactly, so this is not a defect — but the toporouter's form generalises to
  mixed clearances between adjacent wires, which aipcb's does not.
* **Multiple wires on a constraint edge.** A "constraint" is an obstacle boundary. The
  toporouter allows wires to be ordered *along* one, which is what lets several tracks
  run down the side of a package. aipcb gets the same effect from inflation plus a
  free-space triangulation, so this is a difference in machinery, not capability.
* **A serpentine/trombone construction for length matching**, present in the geometry
  layer with a half-cycle count derived from the required delta. aipcb has
  [`meander.py`](../../src/aipcb/route/meander.py) for pairs; the roadmap's "length
  matching beyond a pair" is the unbuilt part.
* **Curvilinear (arc) output.** aipcb emits mitred polylines. §B says why not to
  envy this.
* **Cairo debug rendering of the triangulation, per pass, to PNG.** Compiled behind a
  flag. For a router whose failures are geometric, the ability to *look at* an
  intermediate state is not a luxury; it is how you debug at all. aipcb has
  `contested_cuts` and the JSON report, which is the same instinct in text.

---

## B. The autopsy

### B.1 What actually broke

Concretely, from the record:

| Class | Evidence |
|---|---|
| **Non-termination in the triangulation** | Bug #846789: the toporouter hangs, pinning a core, on a board with **two resistors**. Andrew Poelstra bisected it to commit 97b3260, "convert PCB's base units to nanometers", which changed coordinate types and the `LARGE_VALUE` constant. Stack traces showed nested `swap_if_in_circle()` calls "roughly 10,000 deep" from `gts/cdt.c:506`. The CDT's in-circle predicate stopped being reliable once coordinates moved into a range it had not been tuned for, and edge-flipping never converged. **Confirmed, priority Low, never fixed. Still open, with a 2019 comment offering a mouse-click workaround for the UI freeze.** |
| **Assertion aborts as error handling** | April 2010, PCB 1.99z: `import_route: assertion failed: (routedata->src->netlist == routedata->dest->netlist)`, abort trap. A netlist bookkeeping inconsistency takes down the entire application. `g_assert` is used pervasively in the router's hot paths, including inside the A*. |
| **Segfaults on real boards** | September 2011, a 388-pad layout: the run "took about an hour before it crashed with segfault". |
| **Runtime** | Same report: **twelve minutes for a single connection**, with the GUI wholly unresponsive. Ten connections took about the same. The user's conclusion — "autorouting of a single trace takes just about as long as routing the whole layout" — is a statement about the architecture: nothing is incremental. |
| **The geometry exporter** | Blake spent, by his own account, **well over 100 hours** on the topological-sketch → curvilinear-wiring exporter, "many fixes that didn't work in all cases or introduced new bugs". The June 2009 commit log is that fortnight in miniature: arc orientation in export checks (twice), arc removal not updating a vertex link, "traces arcing back around vertices". A user-facing symptom survived it: fanouts from pads to vias made a curvilinear-wiring error *more* likely unless the stubs were perfectly straight. |
| **Quality on real boards** | Blake, on his own project page: the algorithms "excelled when presented with many layers of free (channelless) wiring space" but "when applied to typical PCB problems, and especially when constrained to few layers and with dense constraints, the results were poor." |

And the benchmark table, which is the honest summary. All figures Blake's, on an Intel
E5300, **with vias disabled**:

| Board | Nets | Maze router | Toporouter |
|---|---|---|---|
| Puzzle (contrived) | — | fails | 0.08 s, solved |
| R8C/27 adapter (angled pads) | 44 | fails all | 0.89 s, 41 routed |
| Flare Genesis | 123 | <1 s, all routed, 60.7 in | 2.3 s, all routed, 52.8 in |
| Beer controller (1 layer) | 72 | ~1 s, 8 failed | 0.85 s, all routed |
| Laminator | 111 | ~2–3 s, 7 failed | 10.2 s, 2 failed |
| Meggy Jr RGB | 158 | ~6 s, 13 failed | 45 s, all routed |
| PPS splitter | 158 | ~9 s, 48 failed | 65.9 s, 31 failed |
| Photo diode receiver | 142 | ~4 s, 30 failed | 6.2 s, 28 failed |
| Altera FLEX 6024A | 269 | 27 s, 43 failed | **89.8 s, 35 failed** |

It is genuinely better on quality nearly everywhere, and 3–20× slower. The bottom row
is the one that killed it: on the largest board tested it spent a minute and a half to
beat the incumbent by eight nets out of 269, and left 35 for a human.

### B.2 Root cause

Three causes, and they are not equally weighted.

**Implementation robustness — the largest.** The fatal bug was not in the routing
algorithm; it was the CDT's floating-point predicates failing under a coordinate range
change made by someone else, in a library the router did not own. The 100-hour
exporter saga was arc-tangent geometry with no invariant to check itself against. The
crashes were `g_assert` and raw C memory management. **The topological idea was never
the thing that broke.**

**Architecture — real, and self-inflicted.** The tightener has no termination
argument and no simplicity guarantee, so it needs loop *detection* — and its response
to detecting a loop is to **delete the offending arc**, which is discarding output
rather than fixing it. There is no automated test of any kind: correctness was
checked by looking at rendered PNGs. Seven thousand seven hundred lines in one file,
whose own header says "it isn't documented or optimized". The rewrite dropped via
support and never regained it.

**Integration — real, and the least of the three.** The router re-imports PCB's data
structures on every run and rebuilds every triangulation from scratch, which is why
routing one connection costs the same as routing the board. It has no dialog, no
parameters a user can reach, and one undocumented action name. Blake's own advice to
users was to edit `hybrid_router()` in the C source and recompile.

**The unifying pattern.** A topological router is a *geometry* program wearing a
graph program's clothes. Its correctness rests entirely on predicates over floating
point — winding, in-circle, intersection, tangency — and every one of the fatal
failures was a predicate that stopped being true. The routing search, the rip-up
policy, the cost model: none of them ever failed.

### B.3 How aipcb fares, mode by mode

Honest three-way verdict. **Guarded** = an invariant or test exists.
**Incidentally avoided** = the architecture differs, but nothing is watching.
**Exposed** = same weakness, nothing guarding it.

| Failure mode | Verdict | Why |
|---|---|---|
| CDT non-termination / predicate failure under a coordinate-range change | **Incidentally avoided** | [ADR 0006](../decisions/0006-routing-approach.md) explicitly refused a hand-rolled CDT — "a classic source of subtle, data-dependent bugs" — and takes GEOS's via Shapely. Coordinates are millimetres snapped to `_QUANT = 1e-6`, which at board scale leaves eight orders of magnitude of double precision in hand. **But nothing tests scale robustness**: there is no case with a board far from the origin, an outline of unusual size, or near-degenerate obstacle geometry. This is the exact shape of the bug that killed the toporouter, and it is the shape [CLAUDE.md](../../CLAUDE.md) warns about — a premise about a tool that was true when written. |
| Tightening fails to terminate | **Guarded** | The funnel is one linear sweep, amortised O(1) per diagonal. There is no loop to not terminate. |
| Tightening produces self-crossing geometry | **Guarded by construction, unchecked in composition** | A single funnel output is simple because the shortest path in a simple polygon is simple. A *multi-leg* route (via hops) concatenates several funnel outputs, and nothing asks whether the concatenation is simple. See [E2](#e2-nothing-checks-that-a-net-does-not-cross-itself). |
| Output violates clearance / DRC | **Guarded, twice** | Clearance is satisfied by inflating obstacles before triangulating, so the shortest legal path *is* the shortest path. On top of that, `test_routed_board_has_no_drc_violations` runs KiCad's own DRC over every example on every CI run. |
| Two nets' copper overlaps | **Guarded, and learned the hard way** | [`invariant.py`](../../src/aipcb/route/invariant.py) exists because M11 produced exactly this and could not explain it; M13 found the cause was an obstacle dict silently overwriting same-named copper. Its docstring is the best single argument in this repository for why a constructive design still needs a blunt final check. The toporouter had no equivalent, which is why its exporter bugs lived for over a year. |
| A crash takes down the host application | **Guarded** | Failures are `StretchError` / handover records with a named reason; `aipcb route` reports and continues. There is no assertion in the router that aborts a process. |
| Memory exhaustion / leaks | **Incidentally avoided** | Python. Not a virtue, but not a risk either. |
| Fighting the host tool's data model | **Incidentally avoided** | aipcb owns its model and writes KiCad files itself ([ADR 0001](../decisions/0001-kicad-io.md), [0002](../decisions/0002-source-format.md)). The unit change that killed the toporouter was made by the host project to satisfy a constraint the router knew nothing about; aipcb has no such upstream. |
| Runtime growing badly with board size | **Exposed** | Nothing measures it. The [roadmap's graduation conditions](../roadmap.md#maturity-and-graduation) already name "runtime is benchmarked against board size" as a condition for autorouting to leave beta, so this is a *known* gap rather than a new finding — but the toporouter is direct evidence that it is the gap that kills, and it is worth raising its priority accordingly. The examples are all small; nobody knows the exponent. |
| The capacity check passes a board that cannot be built | **Exposed** | §A.6. Non-Delaunay cuts are never charged. Mitigated on *legality* by the constructive stretcher and `check_no_crossings`; not mitigated on completeness or diagnosis. |
| Wires hug obstacles with free space unused | **Exposed** | §A.1. No spreading pass. M11d rule 1 covers controlled-impedance pairs only. |
| Legal-but-wasteful routes never improved | **Exposed** | §A.4. Negotiation converges on legality and stops. |
| Correctness checked by looking at pictures | **Guarded** | 71 routing tests, golden files, byte-stability and determinism tests, DRC in CI. |
| Sensitivity to hand-tuned thresholds | **Partly exposed** | Blake reported that "subtle variations in the algorithms" — not randomness; he was explicit that nothing is probabilistic — produced three different complete routings of one board, and warned users off tuning for a specific board. aipcb's [`costs.py`](../../src/aipcb/route/costs.py) has the same character: iteration counts, `congestion_growth`, `PATIENCE`, `_ROOMY_MULTIPLE`. Determinism is tested; *stability under small parameter changes* is not, and no example is a fixture for it. |

### B.4 Why nobody fixed it

The commit log answers this without ambiguity.

**The author's last algorithmic commit is 2010-03-21.** Everything after it — more
than thirty commits over twenty-one months, from five different people — is
janitorial: compiler warnings, `bool`, C++ compatibility, `static inline`, dead-code
removal, an API rename, the unit conversion. Peter Clifton in particular did careful,
substantial cleanup work on the file in October 2011, *the month after the hang was
bisected*, and did not attempt the hang. That is not neglect. It is the correct
decision by someone who could read the code but could not hold its algorithm.

Three things compounded:

1. **The knowledge was never externalised.** No design document beyond a project page
   of screenshots; a header comment that says outright the code is experimental and
   undocumented; no tests. When the author left, the model of how it worked left too.
2. **The rewrite discarded the working version.** Blake chose "start from scratch"
   over "stabilise and document", explicitly, and the second version was abandoned
   before it regained the first's via support. The project ended up with neither a
   documented v1 nor a finished v2.
3. **Nobody could tell working from broken.** With no test suite, "is this change
   safe" was unanswerable, so the only safe change was a cosmetic one — which is
   exactly the change history the log shows.

**The lesson for a one-maintainer router**, stated plainly because it is the one this
project most needs to hear: the toporouter did not die of a hard algorithm. It died
because a single person's undocumented, untested, seven-thousand-line understanding
was the only thing holding it together, and the moment that person stopped, the code
became unmodifiable by anyone else — including, three years later, by a routine
change in the host project that a test suite would have caught in seconds.

aipcb's structural answer is already in place and is worth naming: ADRs that record
why, reports that record what was measured, invariants that fail loudly, a 24-module
package rather than one file, 71 routing tests, and the
[CLAUDE.md](../../CLAUDE.md) rule that a premise about an external tool must be
re-measured before it is built on. That is a genuinely different posture. It does not
change the underlying fact that this is a one-maintainer router, and the toporouter is
the evidence for what the residual risk looks like.

**One thing not to envy: the arcs.** Curvilinear output is beautiful and it consumed
more of the author's time than any other single thing in the project — over 100 hours
on the exporter alone, with the last user-visible symptom still present a year later.
aipcb emits mitred polylines. If arc output is ever proposed, this note is the
argument against doing it as part of the tightener; it belongs, if anywhere, in a
separate, independently testable post-pass over finished polylines.

---

## C. Candidates

Six, plus two flagged exposures. Each is scoped so a milestone prompt can be drafted
from it directly. **Source discipline: every one is to be implemented from this note
and the cited academic work, never from the GPL source.**

### C1. A spreading pass

* **Technique** — distribute the routes crossing a cut evenly along it, rather than
  leaving each hugging the inflated hull it was tightened against. Two variants exist
  in the record: even distribution, and force relaxation to a minimum-spacing
  equilibrium with an iteration cap. Even distribution is simpler, cheaper and has no
  convergence question; start there.
* **Source** — observed mechanism (`spread_edge`, `space_edge`); the underlying idea
  is the rubber-band sketch's freedom to slide crossings along a cut, from the SURF
  line of work.
* **Touches** — a new post-pass between `negotiate` and `stretch`, using
  `LayerField.used` and `RoutePath.crossings()` for the per-cut crossing sets, and
  feeding the stretcher an offset target on each portal. `funnel.py` gains a variant
  that tightens toward a *nominated point* on each portal rather than to the extreme.
* **Benefit** — every net gets what M11d rule 1 currently gives controlled-impedance
  pairs only: room. Less coupling, more space for later nets, easier hand editing,
  and it attacks the `copper_sliver` class from the geometry side.
* **Size** — medium. The pass is small; the funnel variant is the real work, and the
  golden files all move.
* **Note** — this generalises M11d rule 1 rather than replacing it. The standoff is a
  *hard* requirement for an impedance-controlled pair; spreading is best-effort.

### C2. Flip-diagonal cuts

* **Technique** — add, to the cut set, the second diagonal of every quadrilateral
  formed by two adjacent triangles, with capacity equal to that segment's length. A
  route is charged to it when its crossing sequence enters and leaves the pair through
  the two edges that the flip diagonal separates. Optionally also the triangle-height
  test: the perpendicular distance from a triangle's apex to its opposite edge is an
  upper bound on what can round that apex.
* **Source** — observed mechanism (the "special cut", `check_speccut`,
  `triangle_interior_capacity`); the principle is Maley's realizability criterion,
  which aipcb already cites and which quantifies over *all* cuts, not over one
  triangulation's edges.
* **Touches** — [`triangulate.py`](../../src/aipcb/route/triangulate.py) (derive the
  extra cuts alongside `diagonals`), [`field.py`](../../src/aipcb/route/field.py)
  (capacity, `used`, `history` arrays extend), `check.py::check_capacity`.
* **Benefit** — `check_capacity` becomes sound rather than optimistic. Congestion
  pressure appears where it really is, which should improve completion on
  `examples/congestion` and make its diagnostics truthful.
* **Size** — small to medium. The cut derivation is straightforward; the crossing
  attribution needs care, and every congestion-sensitive golden moves.
* **Do first** — measure. Count, on each bundled example, how many flip diagonals are
  *shorter* than the CDT diagonal they pair with. If the answer is near zero on real
  boards, this is a correctness tidy-up rather than a quality win, and should be
  scoped as such.

### C3. A detour pass — rejected at M19

* **Technique** — after negotiation converges, score every routed connection by
  realised length minus unobstructed length. Sort descending. For each above a
  threshold, rip it up, re-route it against the settled field, and keep the result only
  if it is shorter and still legal. Stop at the first connection under the threshold.
* **Source** — observed mechanism (`detour_router`, `roar_detour_route`), and Blake's
  own published before/after measurements (§A.4).
* **Touches** — [`negotiate.py`](../../src/aipcb/route/negotiate.py) (a post-convergence
  phase; rip-up already exists and is free), [`plan.py`](../../src/aipcb/route/plan.py)
  (report the improvement), [`costs.py`](../../src/aipcb/route/costs.py) (threshold,
  pass budget).
* **Benefit** — measured at 7–16% less copper on the comparable historical boards, for
  15–30% more runtime. aipcb has nothing in this space at all.
* **Size** — medium, and the smallest-risk of the three quality candidates: it is
  strictly a post-pass, it can only accept a strictly-better result, and it can be
  budget-capped and switched off.
* **Guard it** — the pass must be deterministic and must never accept a route that
  fails `check_no_crossings`. Bound it by iterations, not by wall clock, or
  `test_routing_is_byte_stable` will start failing on a loaded machine.
* **Measured at M17, in part.** This candidate's named first customer was the E2
  finding on `examples/pcie-sata` — the GND connection laying eight millimetres of
  copper and two vias twice over. It was fixed without a detour pass: M17's via
  pass asks a much narrower question (does this span fit on one layer, in one leg)
  and the answer was yes. So C3 has lost its concrete customer and keeps its
  general one; the numbers M17 measured while looking are in the
  [M17 report](../reports/m17.md) §1, and the useful one for anybody who does
  build C3 is that **53 of the 55 collapsible spans in the corpus were rejected
  because the on-layer route is longer or does not exist** — the vias this router
  spends are, with four exceptions, load bearing.
* **Re-priced at M18, downward.** The 7–16% above is Blake's, on two boards. Dayan's
  own measurement of the same mechanism — his ROAR optimiser, ten two-layer bins,
  427 branches — is **detour from 8.84% to 5.18%, about 3.4% of wire length**
  ([`routing-literature.md` §1.3](routing-literature.md#13-dayans-thesis-obtained--what-the-second-hand-markers-got-right-and-wrong)).
  That is a primary source measuring the mechanism directly, and it should be the
  number this candidate is budgeted against. What M18 *added* in C3's favour is
  Dayan §6.1's argument that some topologies are unreachable by any order of
  sequential shortest-path routing, so a post-pass is structurally necessary rather
  than merely nice.

* **Rejected at M19, 2026-08-24, with its numbers.** The owner declined the
  candidate on the re-priced figure rather than deferring it again. The trade, laid
  out:

  | | Value |
  |---|---|
  | Expected gain | **~3.4 % of wire length** — Dayan's ROAR optimiser, ten two-layer bins, 427 branches, detour 8.84 % → 5.18 %. A primary measurement of this exact mechanism. |
  | Runtime budget | **+30 % of corpus `router_seconds`**, which is what the historical measurement cost |
  | Superseded figure | The 7–16 % this candidate was carried at is Blake's, on **two** boards, second-hand |
  | Named customer | **Gone.** The `route-doubles-back` retrace on `examples/pcie-sata` was fixed at M17b by the via pass, for **+1.3 %** runtime on that board rather than +30 % of the corpus |
  | Corroborating evidence against | **53 of 55** collapsible spans corpus-wide were unimprovable at M17a — 21 because the on-layer route is longer, 32 because the free space is split, **zero on capacity** |
  | What survives in its favour | Dayan §6.1: some topologies are unreachable by *any* order of sequential shortest-path routing, so a post-pass is structurally necessary rather than merely nice |

  **3.4 % for +30 % fails any budget this project has stated.** Every candidate
  since M16 has been held to a runtime ceiling declared before it was built, and no
  ceiling in the record is anywhere near an order of magnitude of runtime per
  percent of copper. Dayan's §6.1 argument is accepted and does not rescue the
  candidate: it establishes that *something* post-convergence is needed for
  completeness on some topologies, not that **this** post-pass is worth 30 % of the
  corpus's routing time. That argument is the one thing that could reopen C3 — a
  cheaper mechanism addressing the same structural gap would be a new candidate,
  budgeted afresh, and not this one.

  **Where the number came from, so it is not re-derived wrongly:**
  [`routing-literature.md` §1.3](routing-literature.md#13-dayans-thesis-obtained--what-the-second-hand-markers-got-right-and-wrong).
  The rejection is recorded here rather than in a deleted branch precisely so the
  next person to propose a detour pass meets 3.4 % before they meet 7–16 %.

### C4. Route to the net, not to the pad

* **Technique** — replace the up-front Euclidean MST with cluster-to-cluster routing:
  seed the search from every terminal of the source group, terminate on any terminal
  of the destination group, and **merge the two groups when a connection completes**,
  so later connections of the same net can land anywhere on what is already connected.
* **Source** — observed mechanism (`cluster_create`, `cluster_merge`,
  `closest_cluster_pair`); the cluster formulation is Dayan/SURF's. Blake independently
  named EMST as the limitation this replaces, in his GSoC wrap-up.
* **Touches** — [`plan.py`](../../src/aipcb/route/plan.py) (`spanning_routes` becomes
  dynamic), [`graph.py`](../../src/aipcb/route/graph.py) (multi-source, multi-target
  search — `Terminal` becomes a set), `stretch.py` (`open_pads` becomes "the copper
  this route may land on").
* **Benefit** — shorter copper, better completion in congestion, and it removes the
  `copper_sliver` at its cause rather than trimming it afterwards.
* **Size** — large, and the most invasive candidate here. It changes what a
  "connection" *is*, which reaches the source format's `RouteTopology` (a declared
  sketch names two pads) and therefore the manual-routing path. **Probably needs its
  own ADR**, because it partially reverses a decision rather than extending one.

### C5. Order the first pass by pairwise conflict

* **Technique** — instead of ordering the first negotiation pass by priority and a
  difficulty heuristic, route each connection alone against an empty board, score each
  pair by how much their solo routes conflict, and derive the order from the resulting
  matrix.
* **Source** — observed mechanism (`netscore_pairwise_*`, `order_nets_preroute_greedy`).
* **Touches** — [`negotiate.py`](../../src/aipcb/route/negotiate.py) ordering only.
* **Benefit** — plausibly fewer negotiation iterations to converge. **Lowest confidence
  of the six**: aipcb negotiates, and negotiation exists precisely to make the first
  order matter less. It is listed because it is cheap to *measure* — count iterations
  to convergence on `examples/congestion` under both orderings — and the measurement
  settles it either way.
* **Size** — small, and it must not disturb `default_priority`: priority is what the
  *source* gets to say, and this must remain a tie-break beneath it.

### C6. A routing benchmark harness

* **Technique** — a fixture that routes a parametrically-scaled board at several sizes
  and records wall time, iterations to convergence, peak memory, and completion rate,
  as a committed table that a report can cite.
* **Source** — the autopsy. Runtime is what actually made the toporouter unusable, and
  it had no benchmark, so nobody could see it coming or tell a regression from a hard
  board.
* **Touches** — `tests/` (a benchmark that is *reported*, not asserted — a threshold
  here would be flaky), plus a section in the next report.
* **Benefit** — it discharges one of the three
  [graduation conditions](../roadmap.md#maturity-and-graduation) autorouting must meet
  to leave beta, and it is the prerequisite for evaluating C1–C4 honestly. **Do this
  one first**: three of the five candidates above trade runtime for quality, and
  without a baseline none of those trades can be judged.
* **Size** — small.

---

### Flagged exposures

These are not features. They are places where §B found aipcb sharing a weakness with
the toporouter and nothing watching, and where the fix is a test or an invariant.

#### E1. The capacity model under-counts cuts

`check_capacity` can pass a board Maley's criterion rejects (§A.6). Legality is
guarded downstream, so this is a diagnosis and completeness defect rather than a
correctness one — but the *check* claims more than it delivers, and the docstring in
[`field.py`](../../src/aipcb/route/field.py) asserts the criterion without the
qualification.

**Now, independent of whether C2 is built:** amend the `field.py` docstring and
`check.py::check_capacity`'s wording to say that the cut set is the triangulation's
diagonals and that this is a *lower bound* on congestion, not the criterion in full.
A check that overstates its own guarantee is worse than one that states its limits.

#### E2. Nothing checks that a net does not cross itself

[`crossing_nets`](../../src/aipcb/route/invariant.py) skips same-net pairs by design,
and it must — two connections of one net are *supposed* to meet. But that also means
nothing anywhere asks whether a *single leg* is a simple polyline, or whether two legs
of one connection overlap on one layer. The toporouter's tightener produced exactly
this class of geometry (its arc-loop checks exist for no other reason), and the aipcb
construction that could produce it — concatenating several funnel outputs across via
hops — is not covered by the argument that protects a single leg.

**Now:** add to `invariant.py` a check that (a) every leg's polyline is simple, and
(b) two legs of the *same connection* on the *same layer* do not overlap except at
shared endpoints. Both are one Shapely call. Expected result on the current corpus is
zero findings, which is the point: it is cheap insurance against the failure class
that cost the toporouter's author a hundred hours.

#### E3. Scale robustness is untested

Not a defect found, a premise unverified — and precisely the kind
[CLAUDE.md](../../CLAUDE.md) exists to catch. The toporouter was killed by a
coordinate-range change breaking a CDT's floating-point predicates. aipcb delegates its
CDT to GEOS and snaps to 1e-6 mm, which is almost certainly fine at board scale, but
"almost certainly" is the state the ADR-premise rule is about.

**Now:** one test that routes an existing example translated a long way from the
origin and scaled, and asserts the same topology comes out. If it passes, the premise
is measured and dated. If it does not, this note has paid for itself.

---

## Measured results, as the closure rule requires

The [part-2 rule](../roadmap.md#part-2-the-quality-candidates-and-the-rule-they-are-held-to)
says a candidate that does not pay for itself is recorded here rather than deleted.
Nothing in M17 was rejected outright — all three of its candidates came in under
budget — but three of its measurements are negative results and belong here, because
the next person to propose the same thing should meet them first.

**Via minimisation is nearly exhausted, and the 37/90 proxy overstates it.** The M16
baseline found 37 of 90 corpus layer changes made by connections that never met a
corridor above half capacity, and the roadmap said out loud that half capacity is a
convention and "no pressure anywhere on the connection" is not "no pressure at the
via". M17a sharpened it by asking the geometry instead. Of 55 candidate spans across
the eleven examples — every place a route leaves a layer and returns to it, plus
every connection whose two pads share a layer — **two collapse**. Twenty-one are
rejected because the single-layer route exists and is longer (so the via bought
something), and thirty-two because the free space on the target layer is genuinely
split in two. The 37 was a proxy; the geometry's answer is four vias, and they are
on one board.

**The capacity arbiter never fired.** M16a's special cuts were built so that a via
collapse could be tested against a sound cut model, and the model is wired in and
tested — but on this corpus **not one span was rejected on capacity**. Length is the
binding constraint everywhere here. That does not make the arbiter unnecessary (a
denser board is exactly where it would speak), it makes it currently unexercised by
real data, and the report says so rather than claiming a win it did not earn.

**The stretcher's cost was constant factors, not the algorithm.** M17c's profile
found that two thirds of the router's profiled wall clock on the largest board was not tightening at
all: it was the *field builder* being rebuilt from scratch for every connection the
shared field could not place, and inside it a scalar Shapely loop over tens of
thousands of candidate via sites. Batching those calls halved the corpus routing
time with **every board's output hash unchanged**. The algorithmic question — whether
the funnel-per-connection-against-a-whole-board-triangulation shape is asymptotically
right — was not touched and is M18's to answer.

**And one candidate is now rejected outright — C3, the first on the list to be.**
Not on a failed implementation: on a re-priced expectation. M18 obtained Dayan's
thesis and replaced the second-hand 7–16 % with a primary **3.4 %**, against a
**+30 %** runtime budget, after M17 had already removed the candidate's named
customer. The owner declined it on 2026-08-24 and the full numbers are in
[C3](#c3-a-detour-pass--rejected-at-m19) above. It is restated here because this is
the section the closure rule points at, and a rejection recorded only inside the
candidate that carried it is one the next reader has to already be looking for.

---

## What this changes

Nothing today: no code moved. What it leaves behind is a measured position on six
techniques, three of which (C1, C3, C4) are the "better layout" track and one of which
(C6) is a precondition for judging them; a soundness gap in the capacity model that
was not previously known (C2/E1); and two cheap guards (E2, E3) against failure
classes with hard historical evidence behind them.

*Written before M16. Since then C6 was built (M16c's bench harness), E1 and E2 were
closed, C3 was **rejected** on its re-priced numbers, and the "better layout" track
is down to C1 and C4 — with [M20](../milestones/m20-placement-quality.md)'s thesis
being that the rest of that track may not be in the router at all. The candidate
entries above carry their own current status; this paragraph is left as written so
the position it records stays datable.*

And the sustainability lesson, which is the part that does not fit in a candidate
list. The toporouter's algorithm was not what failed. What failed was that one
person's undocumented understanding was load-bearing, and when it went, a working
research result became a file nobody could safely change. This project's ADRs,
reports, invariants and re-measurement rule are the countermeasure to exactly that,
and the toporouter is the evidence for what happens without them.

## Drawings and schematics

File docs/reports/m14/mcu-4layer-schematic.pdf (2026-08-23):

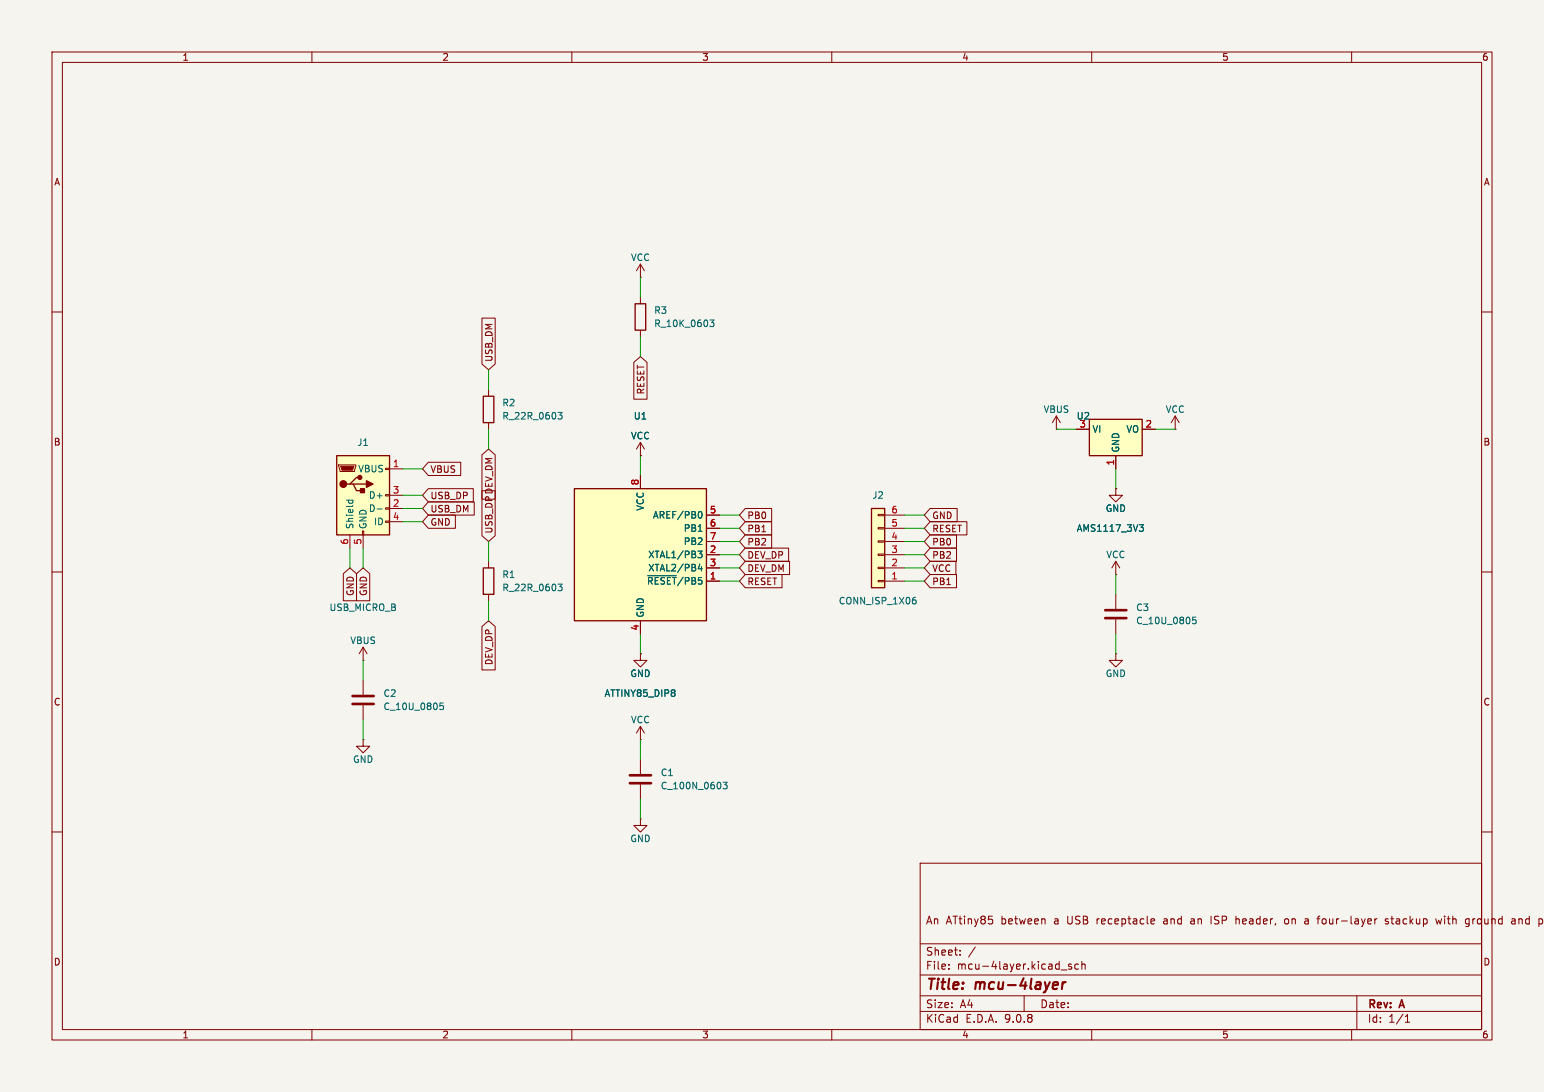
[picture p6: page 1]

4 AREF/PB0 5 PB1 6 PB2 7 XTAL1/PB3 2 XTAL2/PB4 3 ~{RESET}/PB51 U1 ATTINY85_DIP8 VCC GND

4 AREF/PB0 5 PB1 6 PB2 7 XTAL1/PB3 2 XTAL2/PB4 3 ~{RESET}/PB51 VCC GND GND

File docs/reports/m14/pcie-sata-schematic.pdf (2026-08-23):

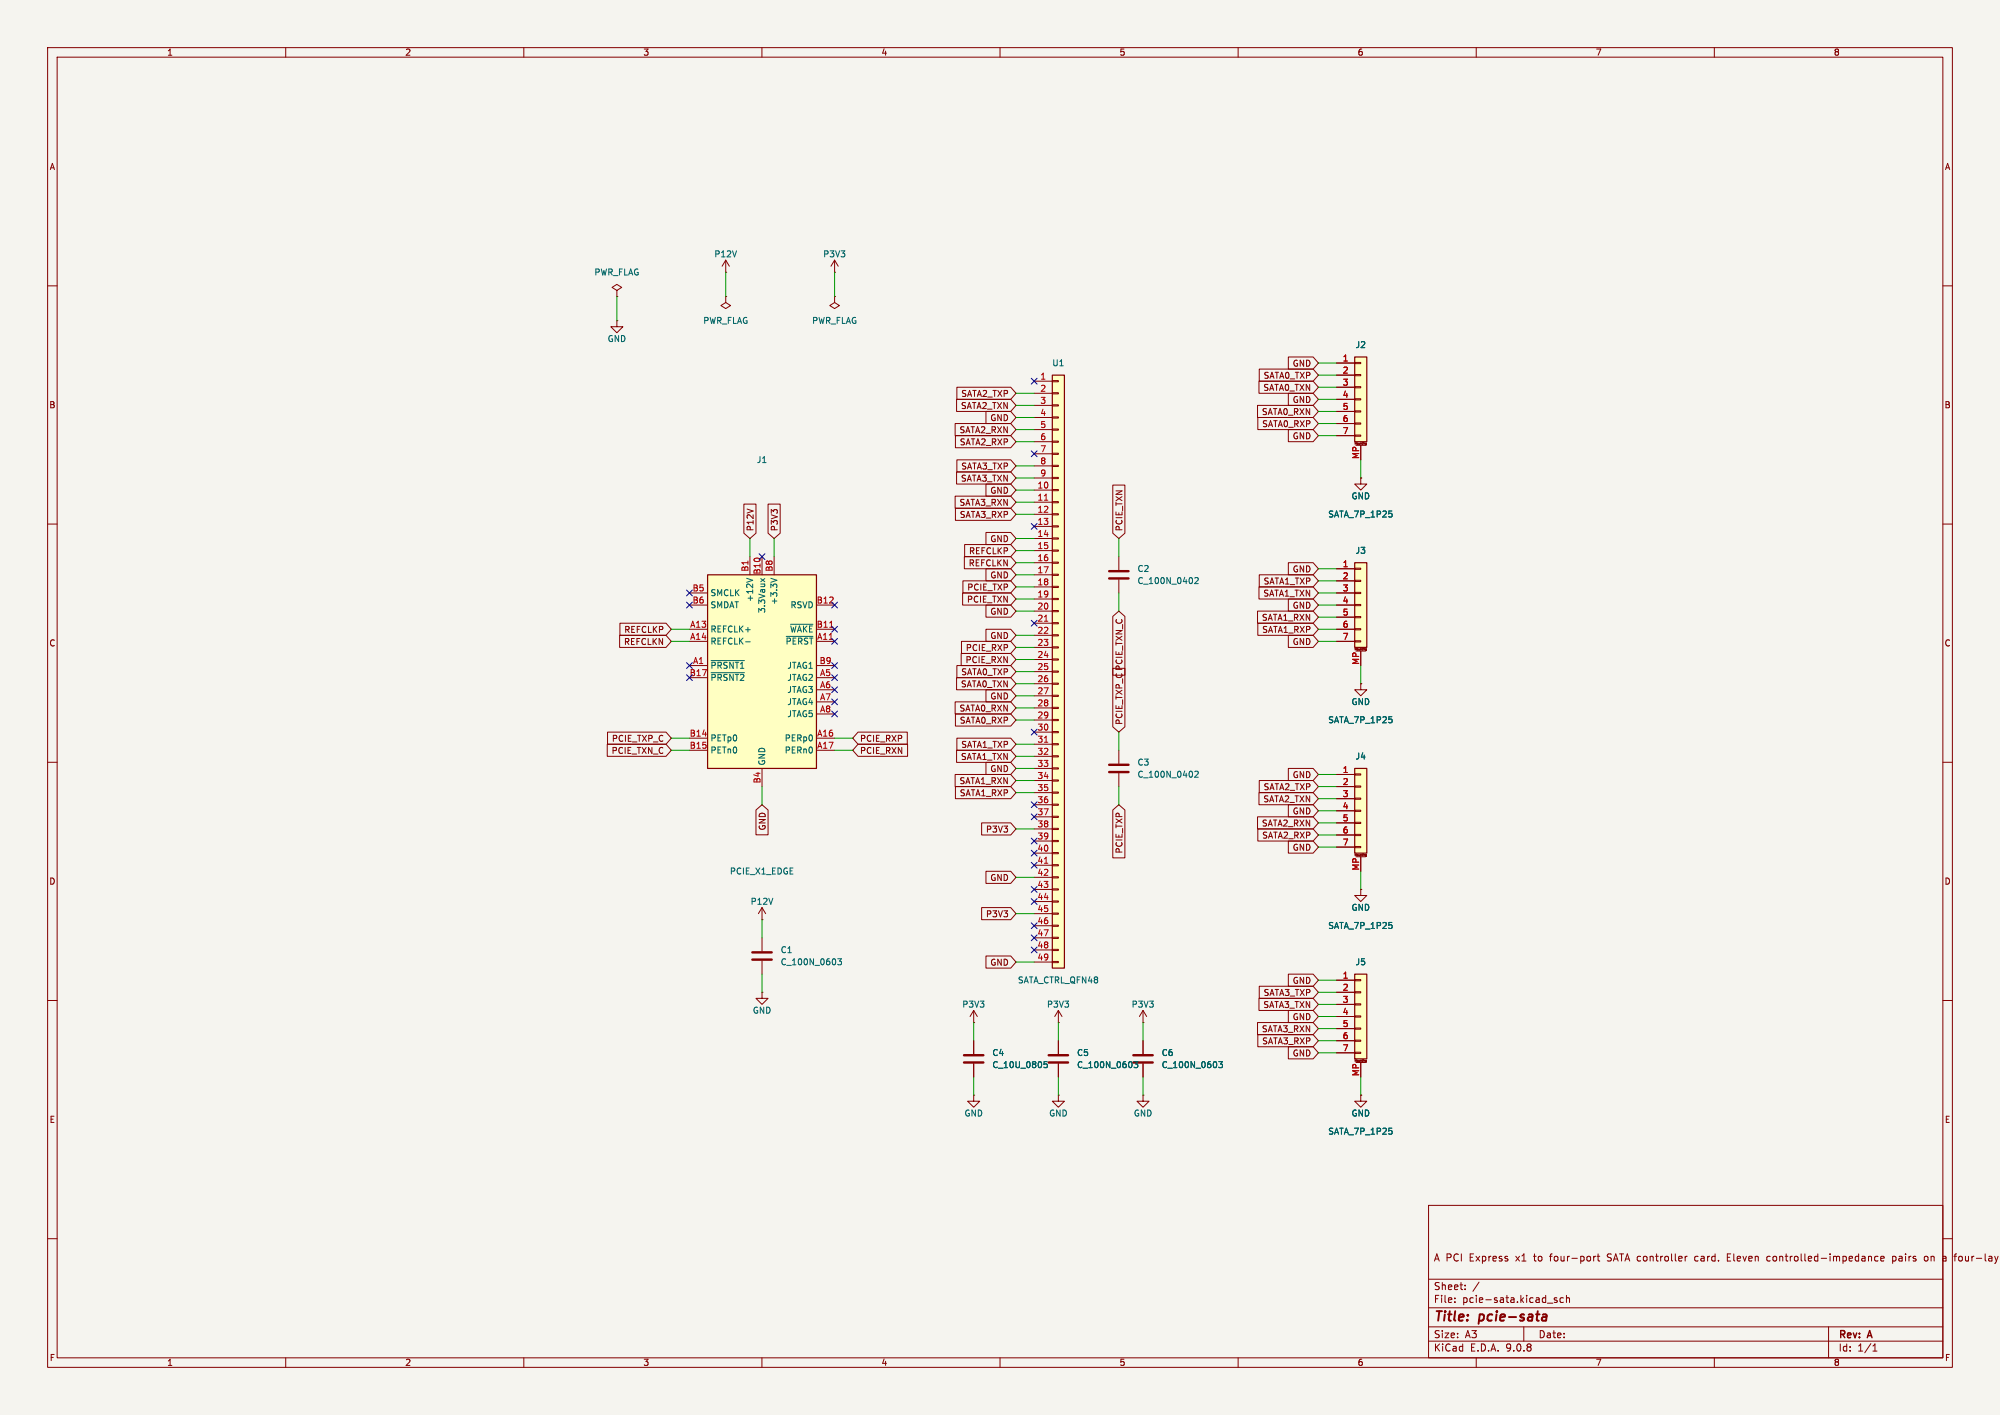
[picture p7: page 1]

Id: 1/1 Title: pcie-sata

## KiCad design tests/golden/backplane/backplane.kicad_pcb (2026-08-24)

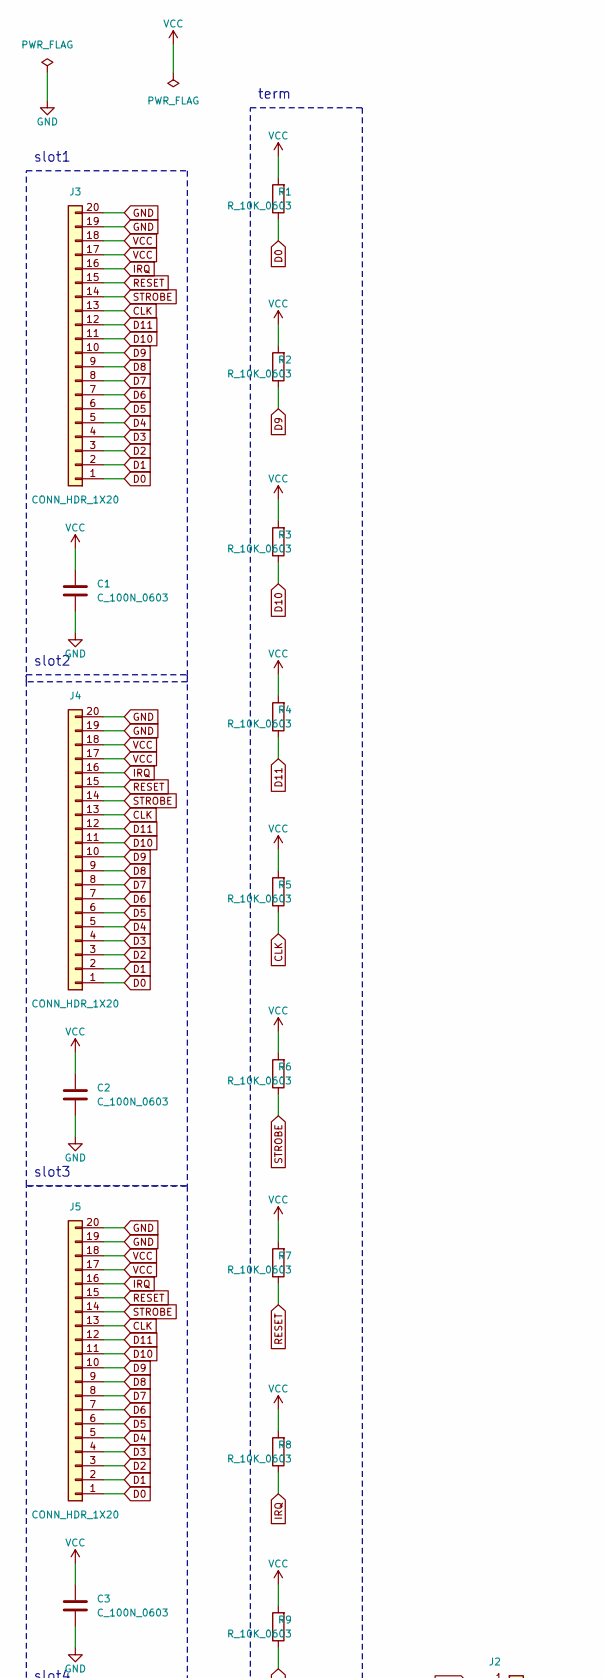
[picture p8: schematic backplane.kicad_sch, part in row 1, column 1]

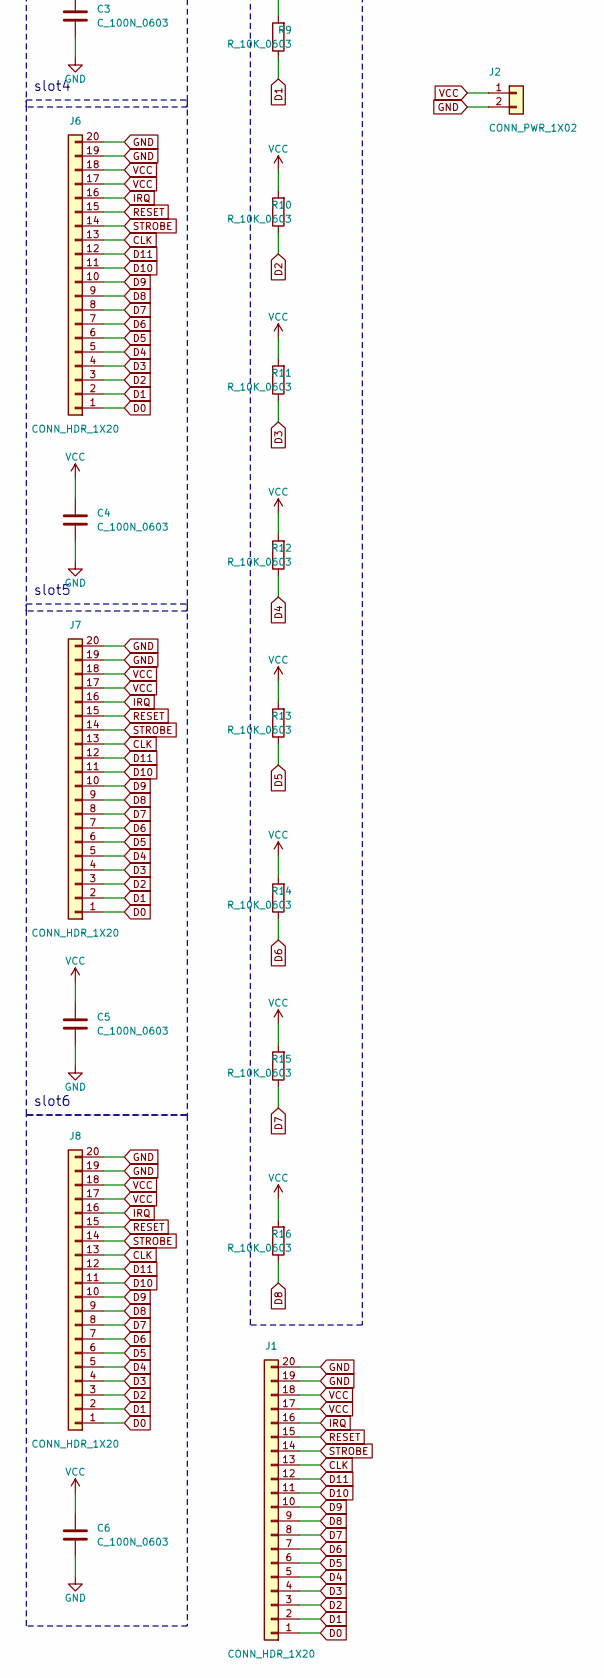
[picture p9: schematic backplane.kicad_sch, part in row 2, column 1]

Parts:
C1, C2, C3, C4, C5, C6: C_100N_0603; C_0603_1608Metric
J1, J3, J4, J5, J6, J7, J8: CONN_HDR_1X20; PinHeader_1x20_P2.54mm_Vertical
J2: CONN_PWR_1X02; PinHeader_1x02_P2.54mm_Vertical
R1, R2, R3, R4, R5, R6, R7, R8, R9, R10, R11, R12, R13, R14, R15, R16: R_10K_0603; R_0603_1608Metric

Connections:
CLK: J1.13, J3.13, J4.13, J5.13, J6.13, J7.13, J8.13, R5.1
D0: J1.1, J3.1, J4.1, J5.1, J6.1, J7.1, J8.1, R1.1
D1: J1.2, J3.2, J4.2, J5.2, J6.2, J7.2, J8.2, R9.1
D2: J1.3, J3.3, J4.3, J5.3, J6.3, J7.3, J8.3, R10.1
D3: J1.4, J3.4, J4.4, J5.4, J6.4, J7.4, J8.4, R11.1
D4: J1.5, J3.5, J4.5, J5.5, J6.5, J7.5, J8.5, R12.1
D5: J1.6, J3.6, J4.6, J5.6, J6.6, J7.6, J8.6, R13.1
D6: J1.7, J3.7, J4.7, J5.7, J6.7, J7.7, J8.7, R14.1
D7: J1.8, J3.8, J4.8, J5.8, J6.8, J7.8, J8.8, R15.1
D8: J1.9, J3.9, J4.9, J5.9, J6.9, J7.9, J8.9, R16.1
D9: J1.10, J3.10, J4.10, J5.10, J6.10, J7.10, J8.10, R2.1
D10: J1.11, J3.11, J4.11, J5.11, J6.11, J7.11, J8.11, R3.1
D11: J1.12, J3.12, J4.12, J5.12, J6.12, J7.12, J8.12, R4.1
GND: C1.2, C2.2, C3.2, C4.2, C5.2, C6.2, J1.19, J1.20, J2.2, J3.19, J3.20, J4.19, J4.20, J5.19, J5.20, J6.19, J6.20, J7.19, J7.20, J8.19, J8.20
IRQ: J1.16, J3.16, J4.16, J5.16, J6.16, J7.16, J8.16, R8.1
RESET: J1.15, J3.15, J4.15, J5.15, J6.15, J7.15, J8.15, R7.1
STROBE: J1.14, J3.14, J4.14, J5.14, J6.14, J7.14, J8.14, R6.1
VCC: C1.1, C2.1, C3.1, C4.1, C5.1, C6.1, J1.17, J1.18, J2.1, J3.17, J3.18, J4.17, J4.18, J5.17, J5.18, J6.17, J6.18, J7.17, J7.18, J8.17, J8.18, R1.2, R2.2, R3.2, R4.2, R5.2, R6.2, R7.2, R8.2, R9.2, R10.2, R11.2, R12.2, R13.2, R14.2, R15.2, R16.2

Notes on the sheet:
slot1
slot2
slot3
slot4
slot5
slot6
term

Board: 4 copper layers, 30 parts (0 on the bottom side), 18 nets, no tracks yet.

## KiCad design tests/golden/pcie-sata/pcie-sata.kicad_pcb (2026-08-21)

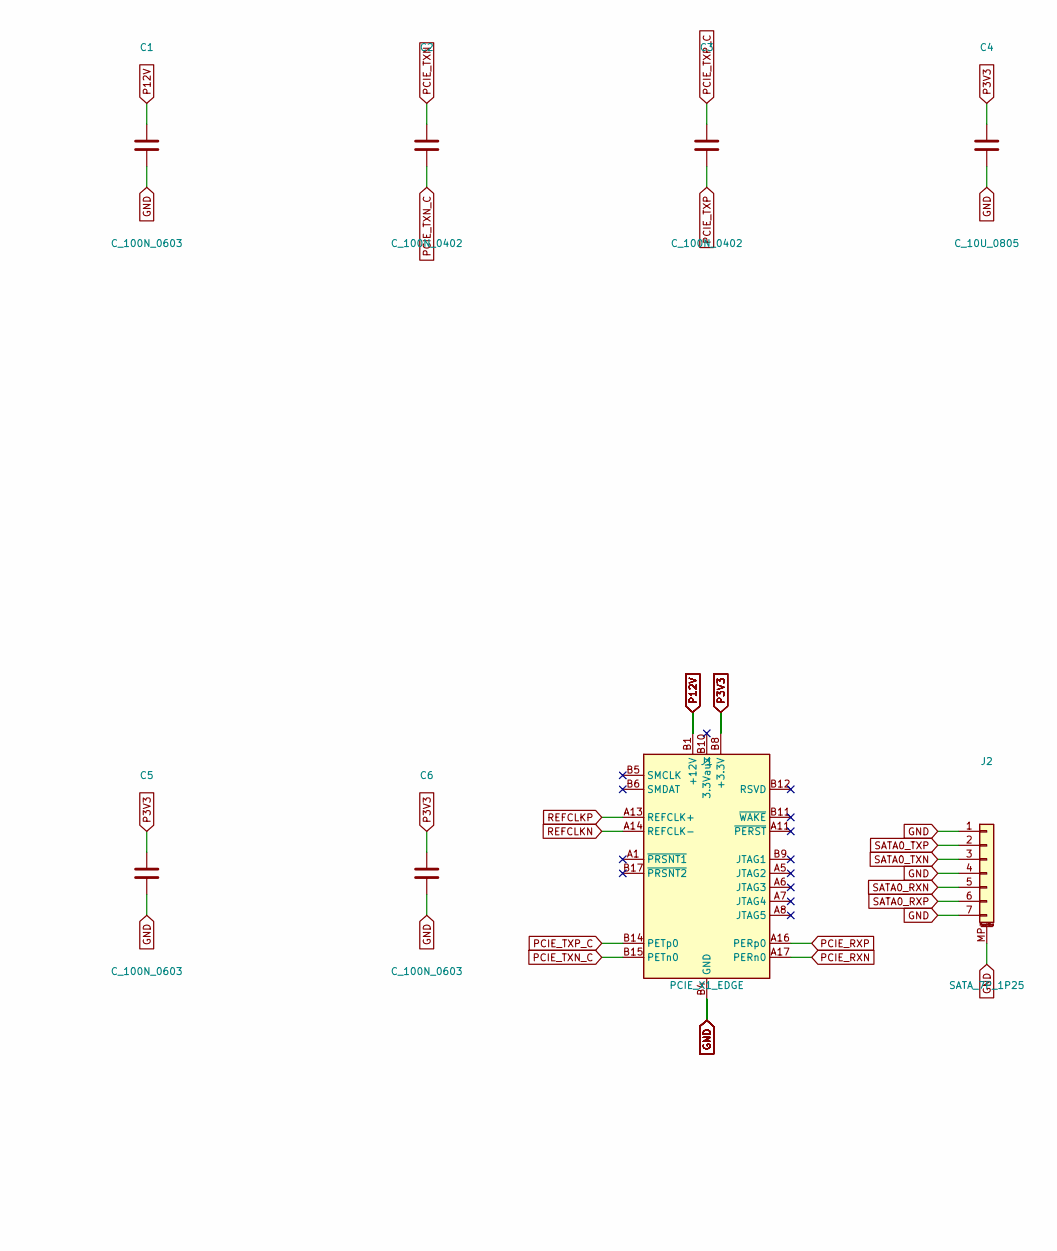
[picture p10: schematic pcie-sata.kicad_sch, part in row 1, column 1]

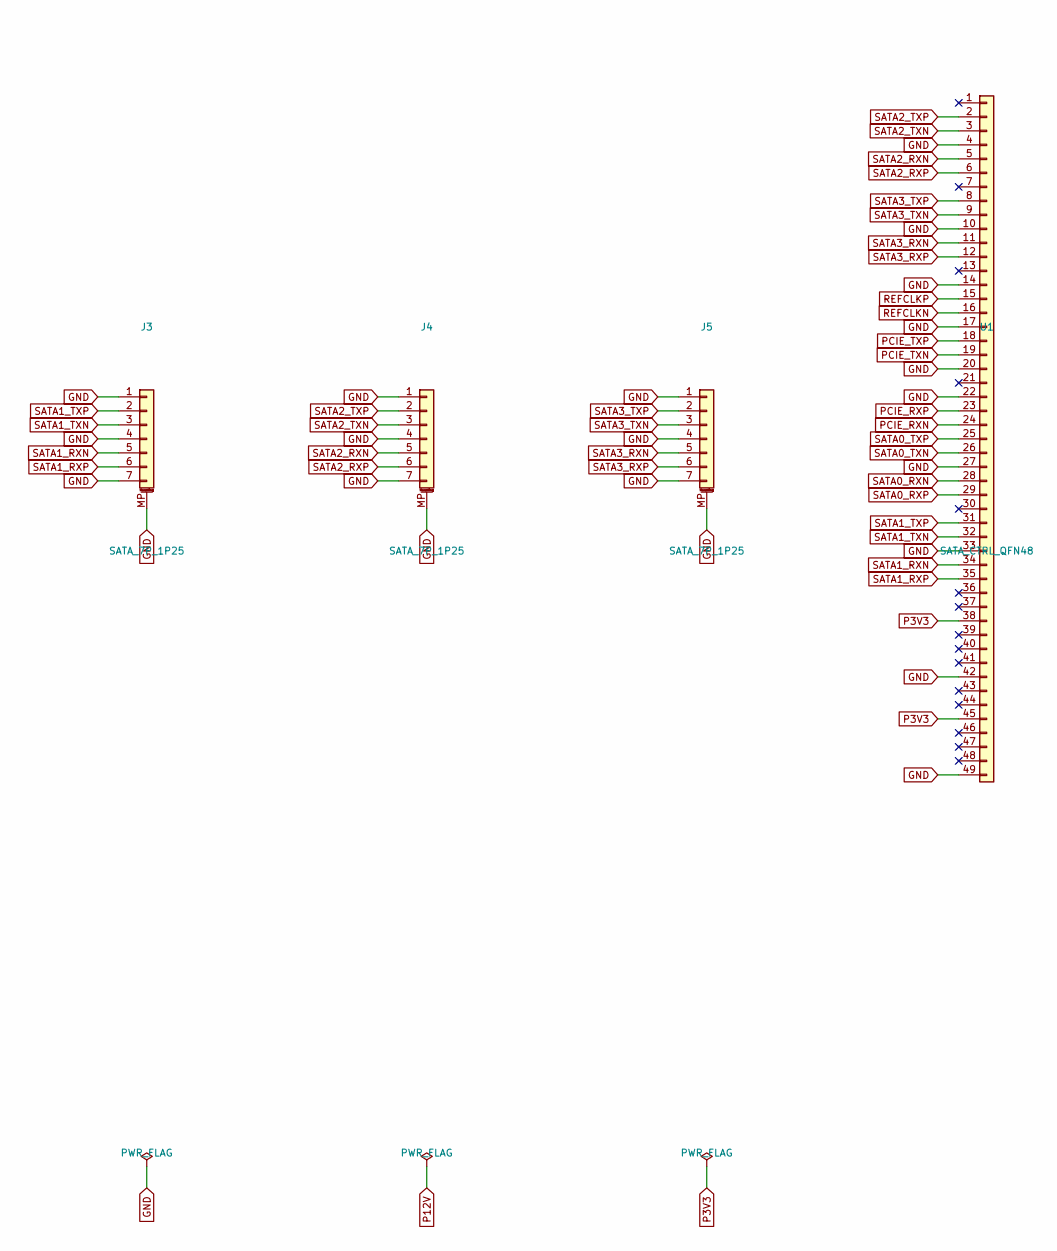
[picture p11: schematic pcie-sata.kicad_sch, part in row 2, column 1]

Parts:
C1, C5, C6: C_100N_0603; C_0603_1608Metric
C2, C3: C_100N_0402; C_0402_1005Metric
C4: C_10U_0805; C_0805_2012Metric
J1: PCIE_X1_EDGE; BUS_PCIexpress_x1
J2, J3, J4, J5: SATA_7P_1P25; JST_GH_SM07B-GHS-TB_1x07-1MP_P1.25mm_Horizontal
U1: SATA_CTRL_QFN48; QFN-48-1EP_7x7mm_P0.5mm_EP5.15x5.15mm

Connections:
GND: C1.2, C4.2, C5.2, C6.2, J1.A4 (GND), J1.A12 (GND), J1.A15 (GND), J1.A18 (GND), J1.B4 (GND), J1.B7 (GND), J1.B13 (GND), J1.B16 (GND), J1.B18 (GND), J2.1, J2.4, J2.7, J2.MP (MountPin), J3.1, J3.4, J3.7, J3.MP (MountPin), J4.1, J4.4, J4.7, J4.MP (MountPin), J5.1, J5.4, J5.7, J5.MP (MountPin), U1.4, U1.10, U1.14, U1.17, U1.20, U1.22, U1.27, U1.33, U1.42, U1.49
P3V3: C4.1, C5.1, C6.1, J1.A9 (+3.3V), J1.A10 (+3.3V), J1.B8 (+3.3V), U1.38, U1.45
P12V: C1.1, J1.A2 (+12V), J1.A3 (+12V), J1.B1 (+12V), J1.B2 (+12V), J1.B3 (+12V)
PCIE_RXN: J1.A17 (PERn0), U1.24
PCIE_RXP: J1.A16 (PERp0), U1.23
PCIE_TXN: C2.1, U1.19
PCIE_TXN_C: C2.2, J1.B15 (PETn0)
PCIE_TXP: C3.2, U1.18
PCIE_TXP_C: C3.1, J1.B14 (PETp0)
REFCLKN: J1.A14 (REFCLK-), U1.16
REFCLKP: J1.A13 (REFCLK+), U1.15
SATA0_RXN: J2.5, U1.28
SATA0_RXP: J2.6, U1.29
SATA0_TXN: J2.3, U1.26
SATA0_TXP: J2.2, U1.25
SATA1_RXN: J3.5, U1.34
SATA1_RXP: J3.6, U1.35
SATA1_TXN: J3.3, U1.32
SATA1_TXP: J3.2, U1.31
SATA2_RXN: J4.5, U1.5
SATA2_RXP: J4.6, U1.6
SATA2_TXN: J4.3, U1.3
SATA2_TXP: J4.2, U1.2
SATA3_RXN: J5.5, U1.11
SATA3_RXP: J5.6, U1.12
SATA3_TXN: J5.3, U1.9
SATA3_TXP: J5.2, U1.8

Board: 4 copper layers, 12 parts (0 on the bottom side), 27 nets, no tracks yet.

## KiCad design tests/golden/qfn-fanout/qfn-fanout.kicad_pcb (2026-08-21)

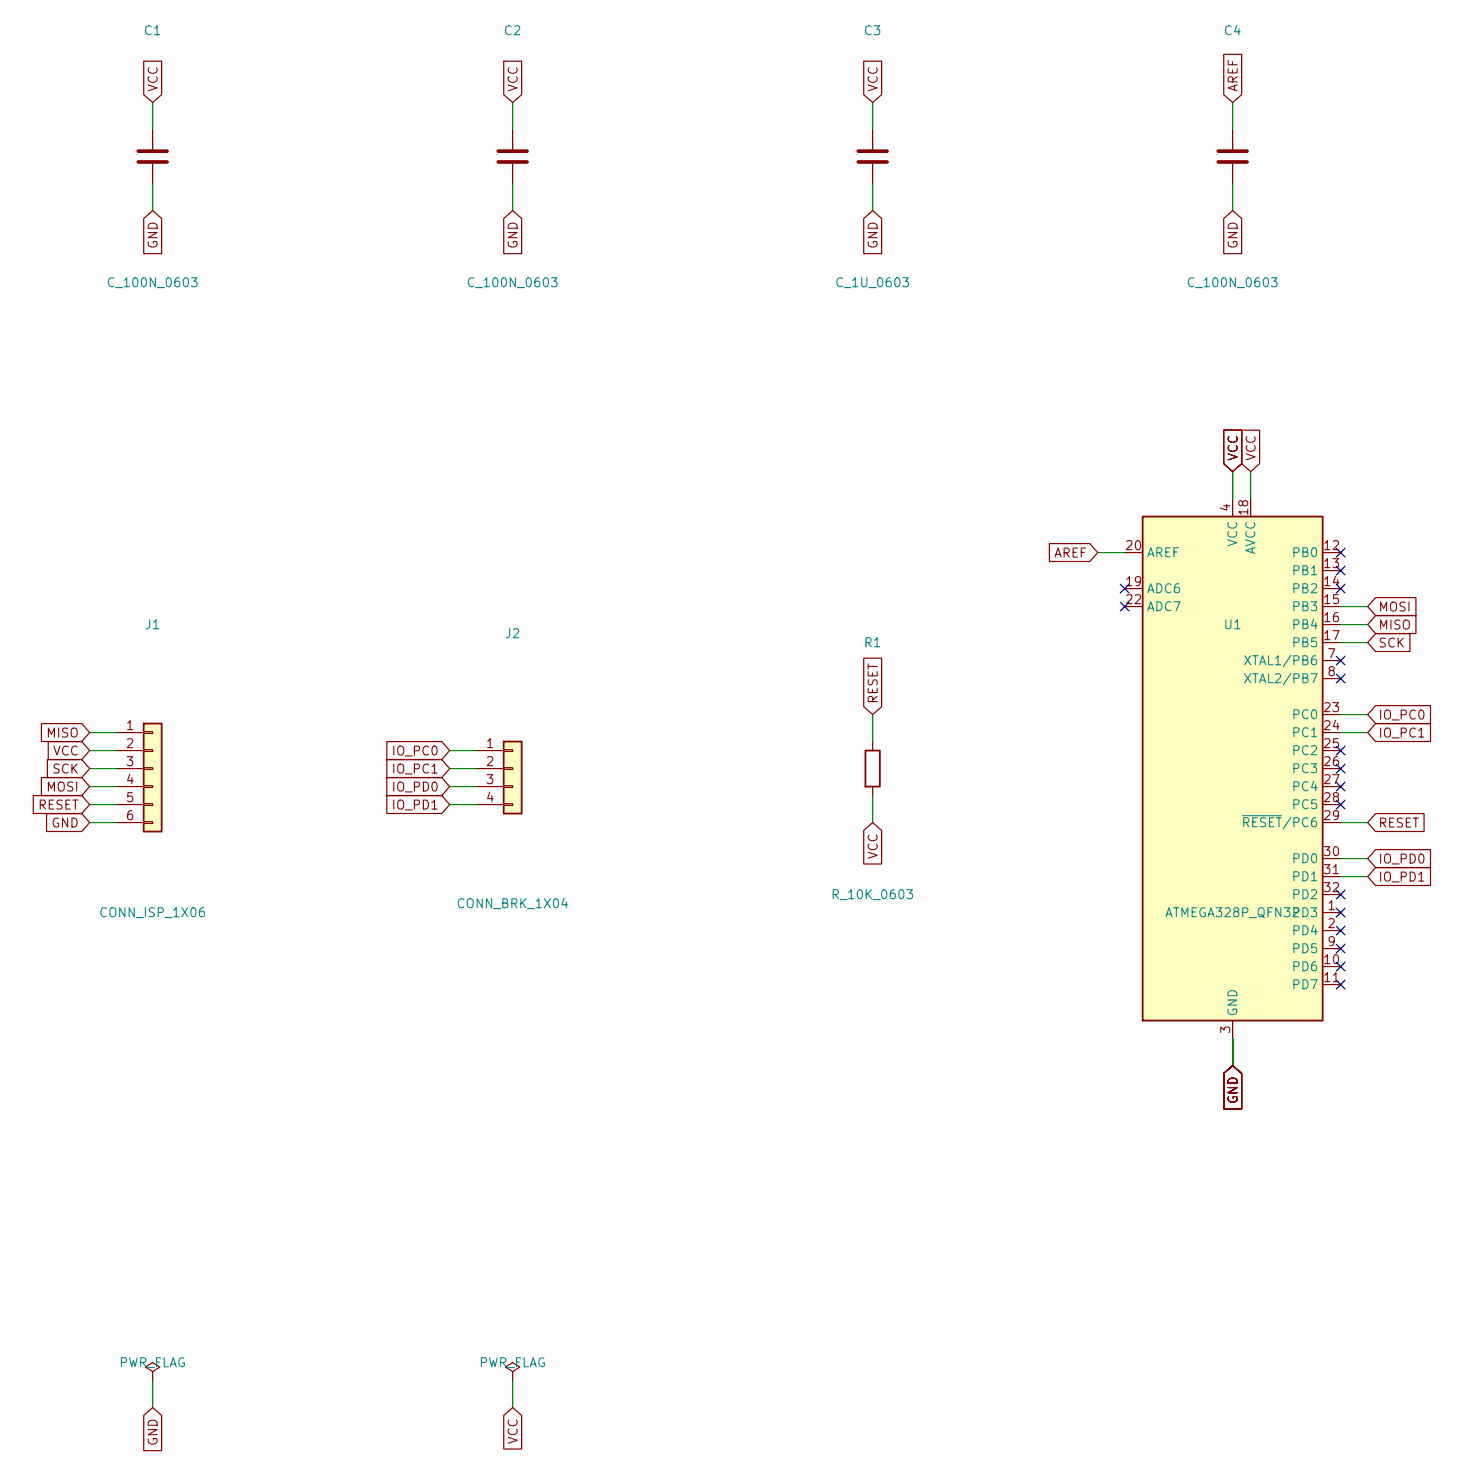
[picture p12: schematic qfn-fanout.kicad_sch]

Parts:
C1, C2, C4: C_100N_0603; C_0603_1608Metric
C3: C_1U_0603; C_0603_1608Metric
J1: CONN_ISP_1X06; PinHeader_1x06_P2.54mm_Vertical
J2: CONN_BRK_1X04; PinHeader_1x04_P2.54mm_Vertical
R1: R_10K_0603; R_0603_1608Metric
U1: ATMEGA328P_QFN32; QFN-32-1EP_5x5mm_P0.5mm_EP3.1x3.1mm

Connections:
AREF: C4.1, U1.20 (AREF)
GND: C1.2, C2.2, C3.2, C4.2, J1.6, U1.3 (GND), U1.5 (GND), U1.21 (GND), U1.33 (GND)
IO_PC0: J2.1, U1.23 (PC0)
IO_PC1: J2.2, U1.24 (PC1)
IO_PD0: J2.3, U1.30 (PD0)
IO_PD1: J2.4, U1.31 (PD1)
MISO: J1.1, U1.16 (PB4)
MOSI: J1.4, U1.15 (PB3)
RESET: J1.5, R1.1, U1.29 (~RESET/PC6)
SCK: J1.3, U1.17 (PB5)
VCC: C1.1, C2.1, C3.1, J1.2, R1.2, U1.4 (VCC), U1.6 (VCC), U1.18 (AVCC)

Board: 2 copper layers, 8 parts (0 on the bottom side), 11 nets, no tracks yet.

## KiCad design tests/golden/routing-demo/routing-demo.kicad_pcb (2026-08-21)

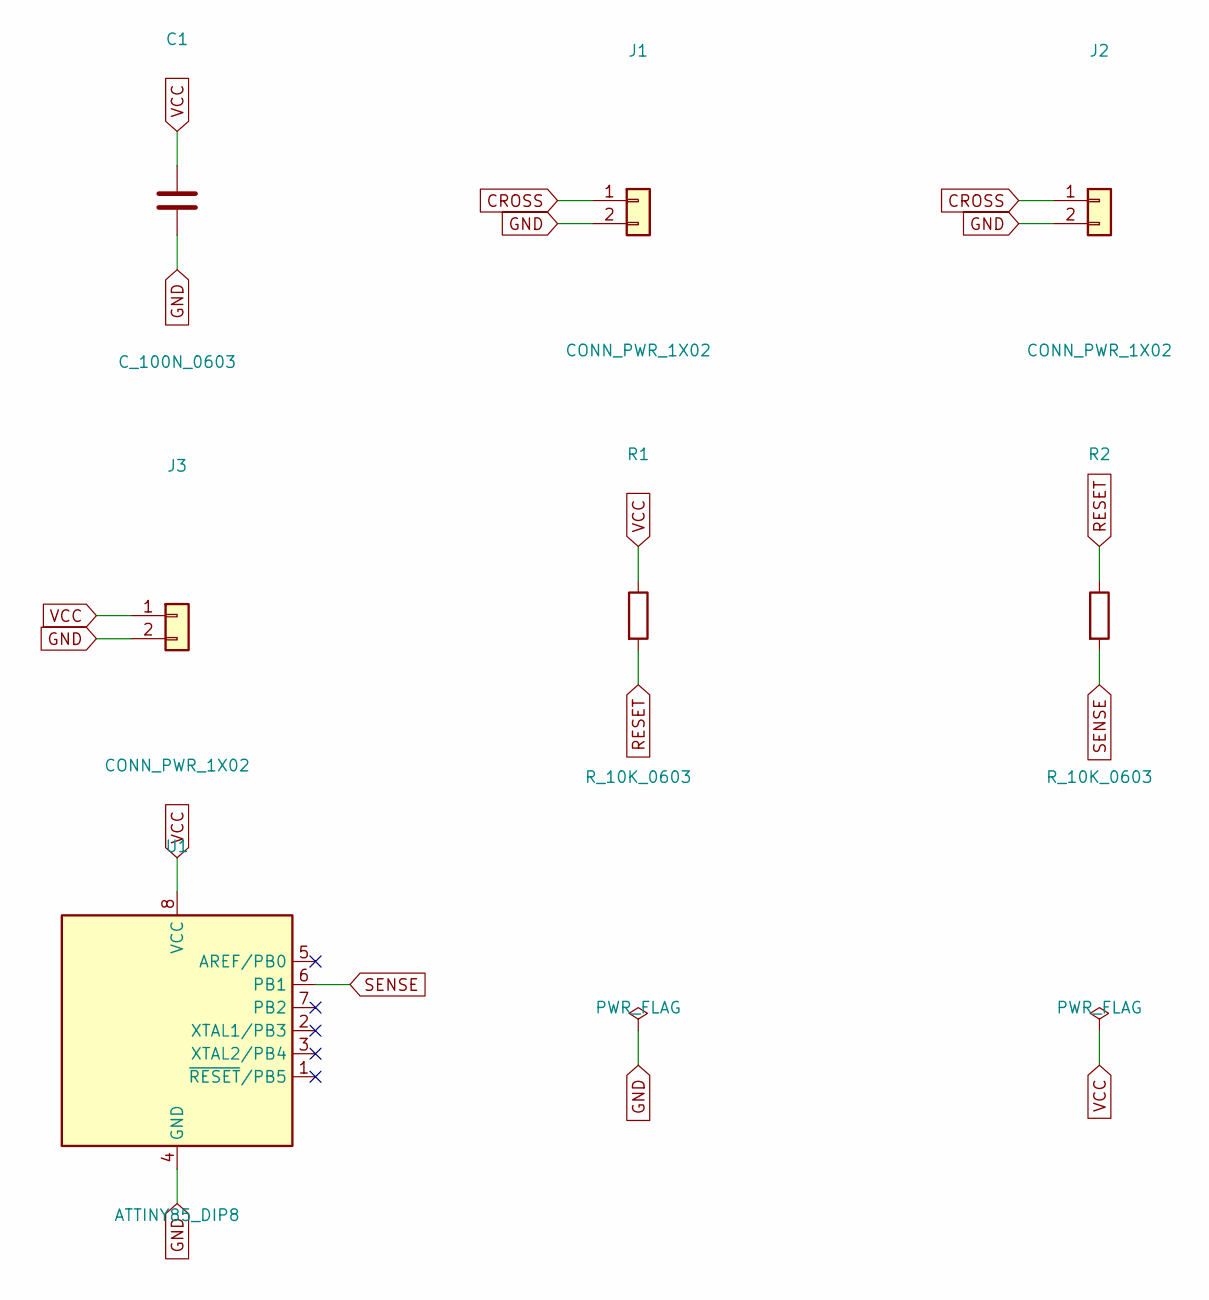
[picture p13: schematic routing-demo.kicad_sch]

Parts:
C1: C_100N_0603; C_0603_1608Metric
J1, J2, J3: CONN_PWR_1X02; PinHeader_1x02_P2.54mm_Vertical
R1, R2: R_10K_0603; R_0603_1608Metric
U1: ATTINY85_DIP8; DIP-8_W7.62mm

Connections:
CROSS: J1.1, J2.1
GND: C1.2, J1.2, J2.2, J3.2, U1.4 (GND)
RESET: R1.2, R2.1
SENSE: R2.2, U1.6 (PB1)
VCC: C1.1, J3.1, R1.1, U1.8 (VCC)

Board: 2 copper layers, 7 parts (0 on the bottom side), 5 nets, no tracks yet.

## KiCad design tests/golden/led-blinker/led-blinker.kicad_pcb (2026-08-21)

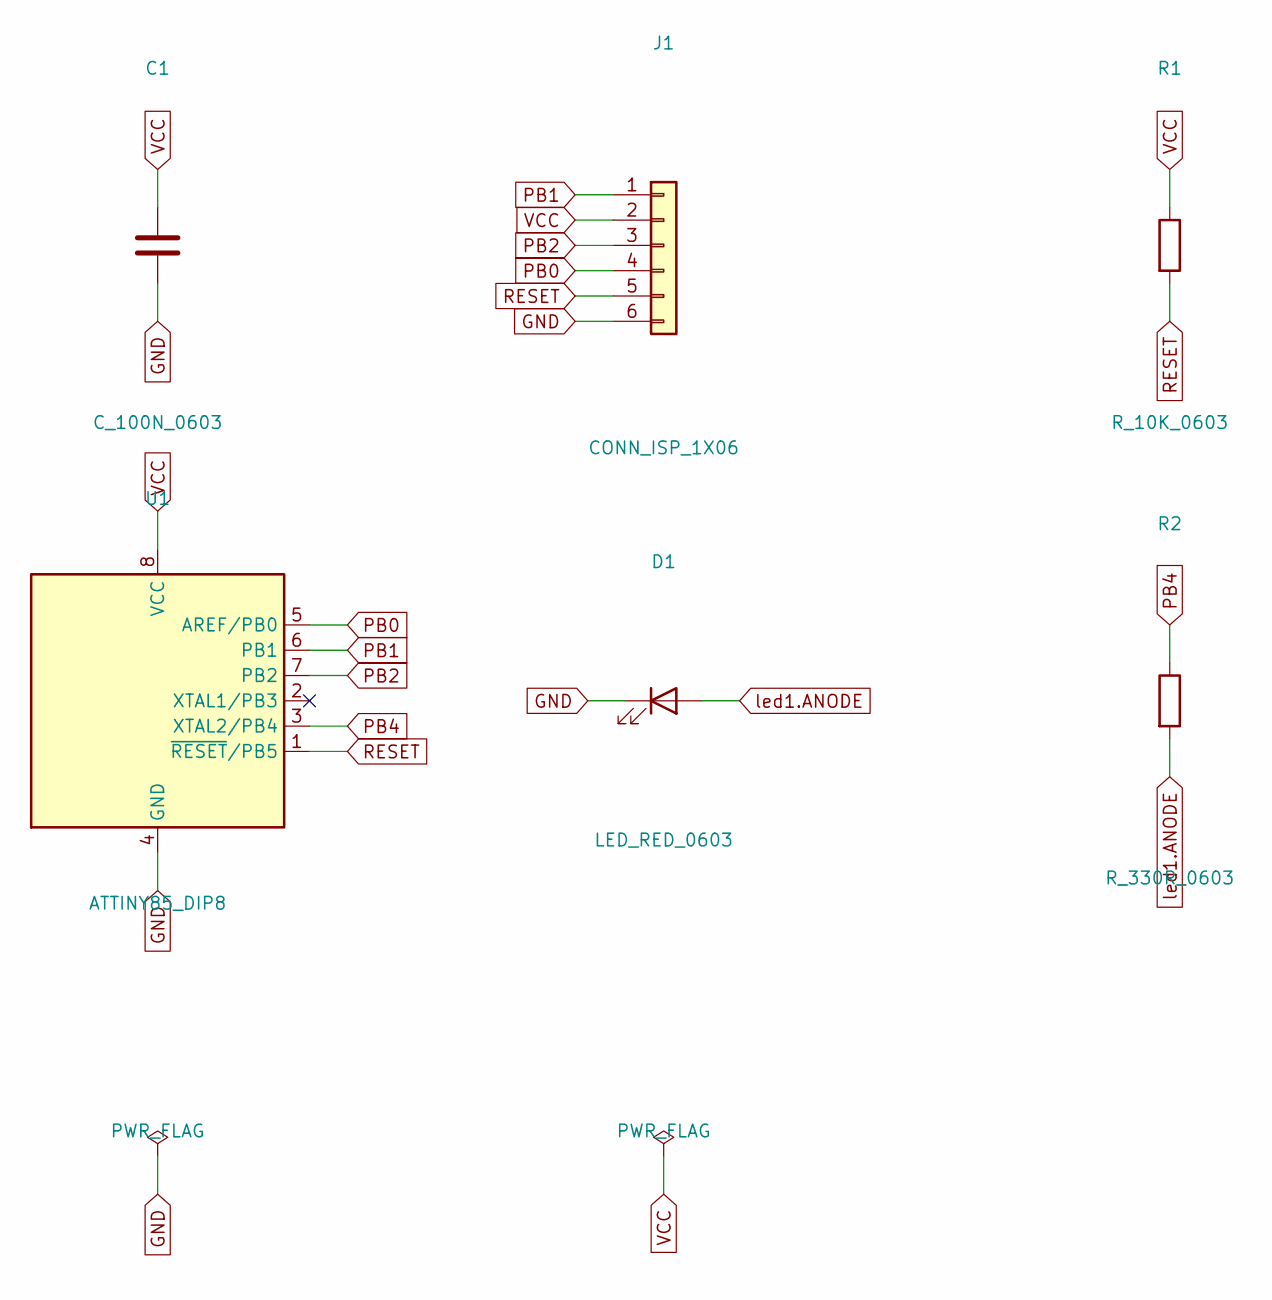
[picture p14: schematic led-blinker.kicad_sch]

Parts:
C1: C_100N_0603; C_0603_1608Metric
D1: LED_RED_0603; LED_0603_1608Metric
J1: CONN_ISP_1X06; PinHeader_1x06_P2.54mm_Vertical
R1: R_10K_0603; R_0603_1608Metric
R2: R_330R_0603; R_0603_1608Metric
U1: ATTINY85_DIP8; DIP-8_W7.62mm

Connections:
GND: C1.2, D1.1 (K), J1.6, U1.4 (GND)
PB0: J1.4, U1.5 (AREF/PB0)
PB1: J1.1, U1.6 (PB1)
PB2: J1.3, U1.7 (PB2)
PB4: R2.1, U1.3 (XTAL2/PB4)
RESET: J1.5, R1.2, U1.1 (~RESET/PB5)
VCC: C1.1, J1.2, R1.1, U1.8 (VCC)
led1.ANODE: D1.2 (A), R2.2

Board: 2 copper layers, 6 parts (0 on the bottom side), 8 nets, no tracks yet.

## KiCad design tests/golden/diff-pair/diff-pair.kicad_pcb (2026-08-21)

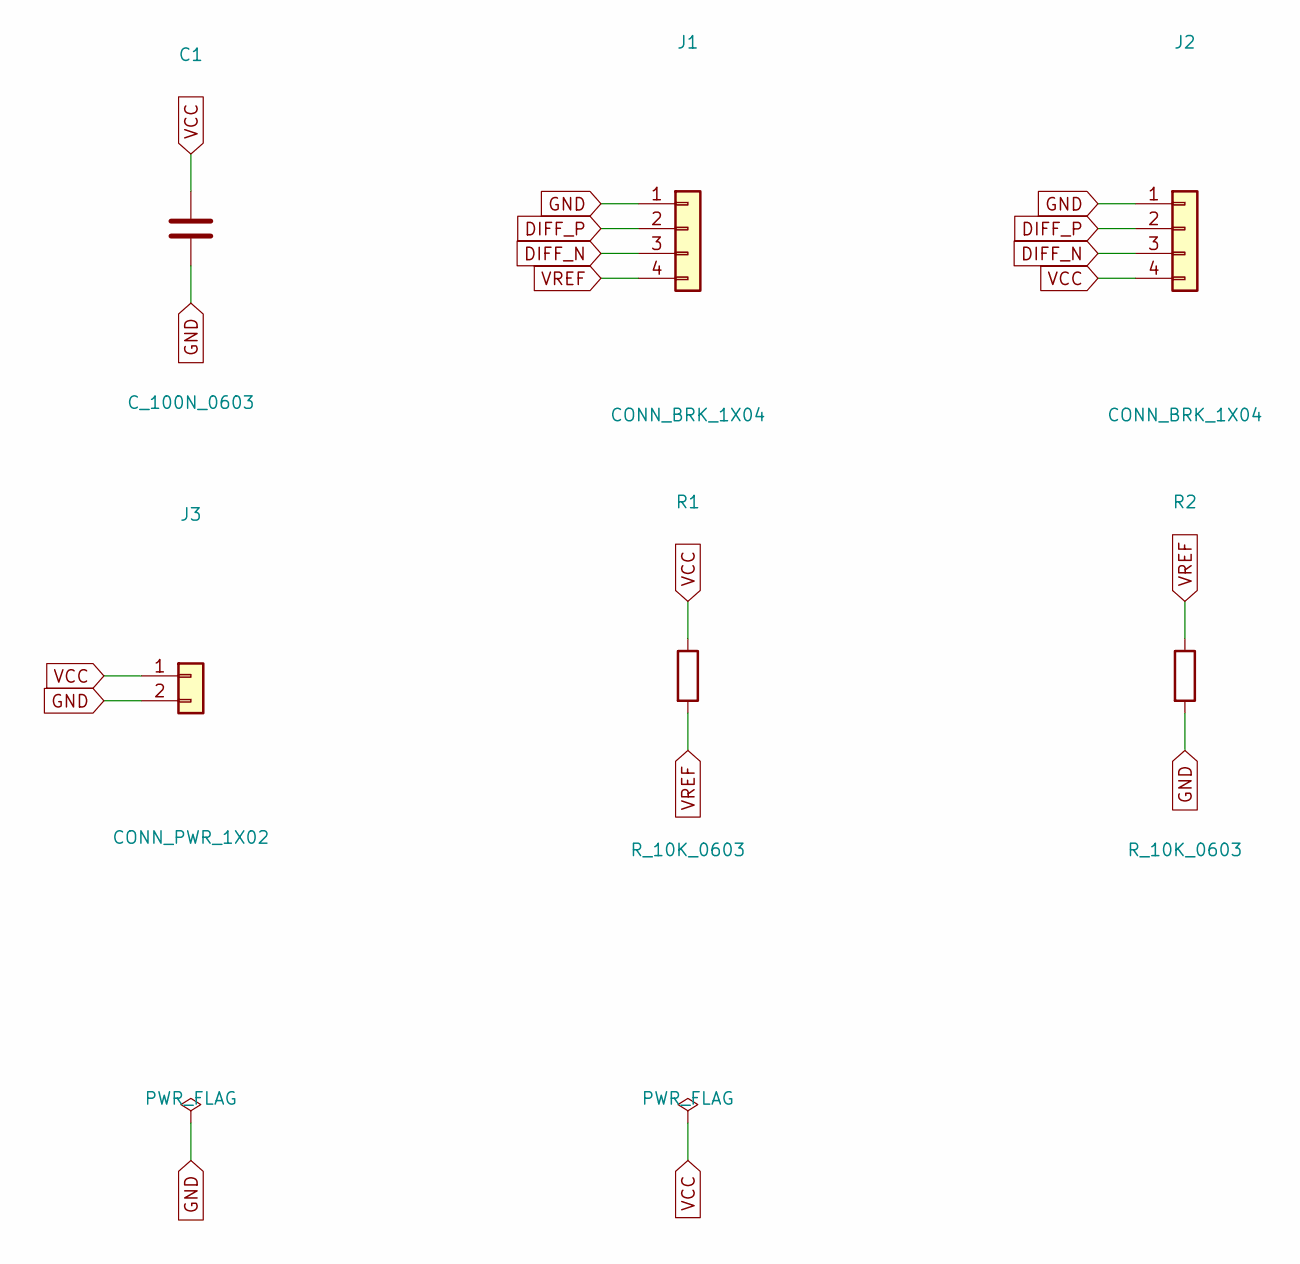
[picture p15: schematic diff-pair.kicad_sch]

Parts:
C1: C_100N_0603; C_0603_1608Metric
J1, J2: CONN_BRK_1X04; PinHeader_1x04_P2.54mm_Vertical
J3: CONN_PWR_1X02; PinHeader_1x02_P2.54mm_Vertical
R1, R2: R_10K_0603; R_0603_1608Metric

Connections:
DIFF_N: J1.3, J2.3
DIFF_P: J1.2, J2.2
GND: C1.2, J1.1, J2.1, J3.2, R2.2
VCC: C1.1, J2.4, J3.1, R1.1
VREF: J1.4, R1.2, R2.1

Board: 2 copper layers, 6 parts (0 on the bottom side), 5 nets, no tracks yet.

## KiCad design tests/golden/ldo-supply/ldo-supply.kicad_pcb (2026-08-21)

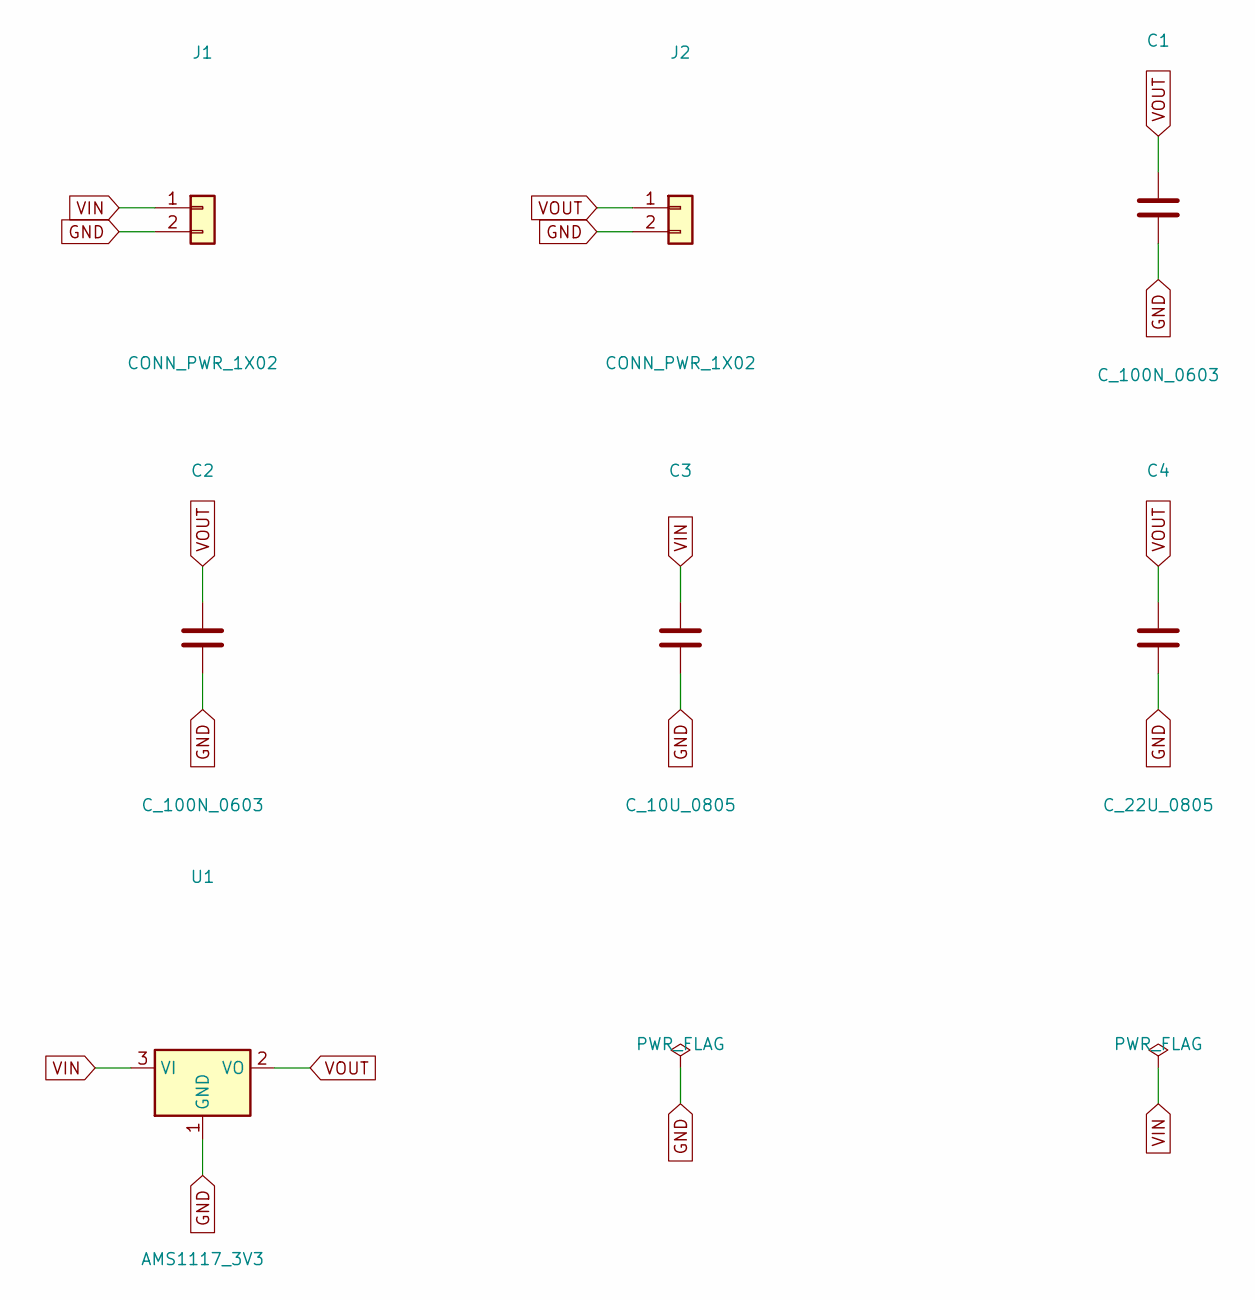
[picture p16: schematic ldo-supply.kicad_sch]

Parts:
C1, C2: C_100N_0603; C_0603_1608Metric
C3: C_10U_0805; C_0805_2012Metric
C4: C_22U_0805; C_0805_2012Metric
J1, J2: CONN_PWR_1X02; PinHeader_1x02_P2.54mm_Vertical
U1: AMS1117_3V3; SOT-223-3_TabPin2

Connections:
GND: C1.2, C2.2, C3.2, C4.2, J1.2, J2.2, U1.1 (GND)
VIN: C3.1, J1.1, U1.3 (VI)
VOUT: C1.1, C2.1, C4.1, J2.1, U1.2 (VO)

Board: 2 copper layers, 7 parts (0 on the bottom side), 3 nets, no tracks yet.

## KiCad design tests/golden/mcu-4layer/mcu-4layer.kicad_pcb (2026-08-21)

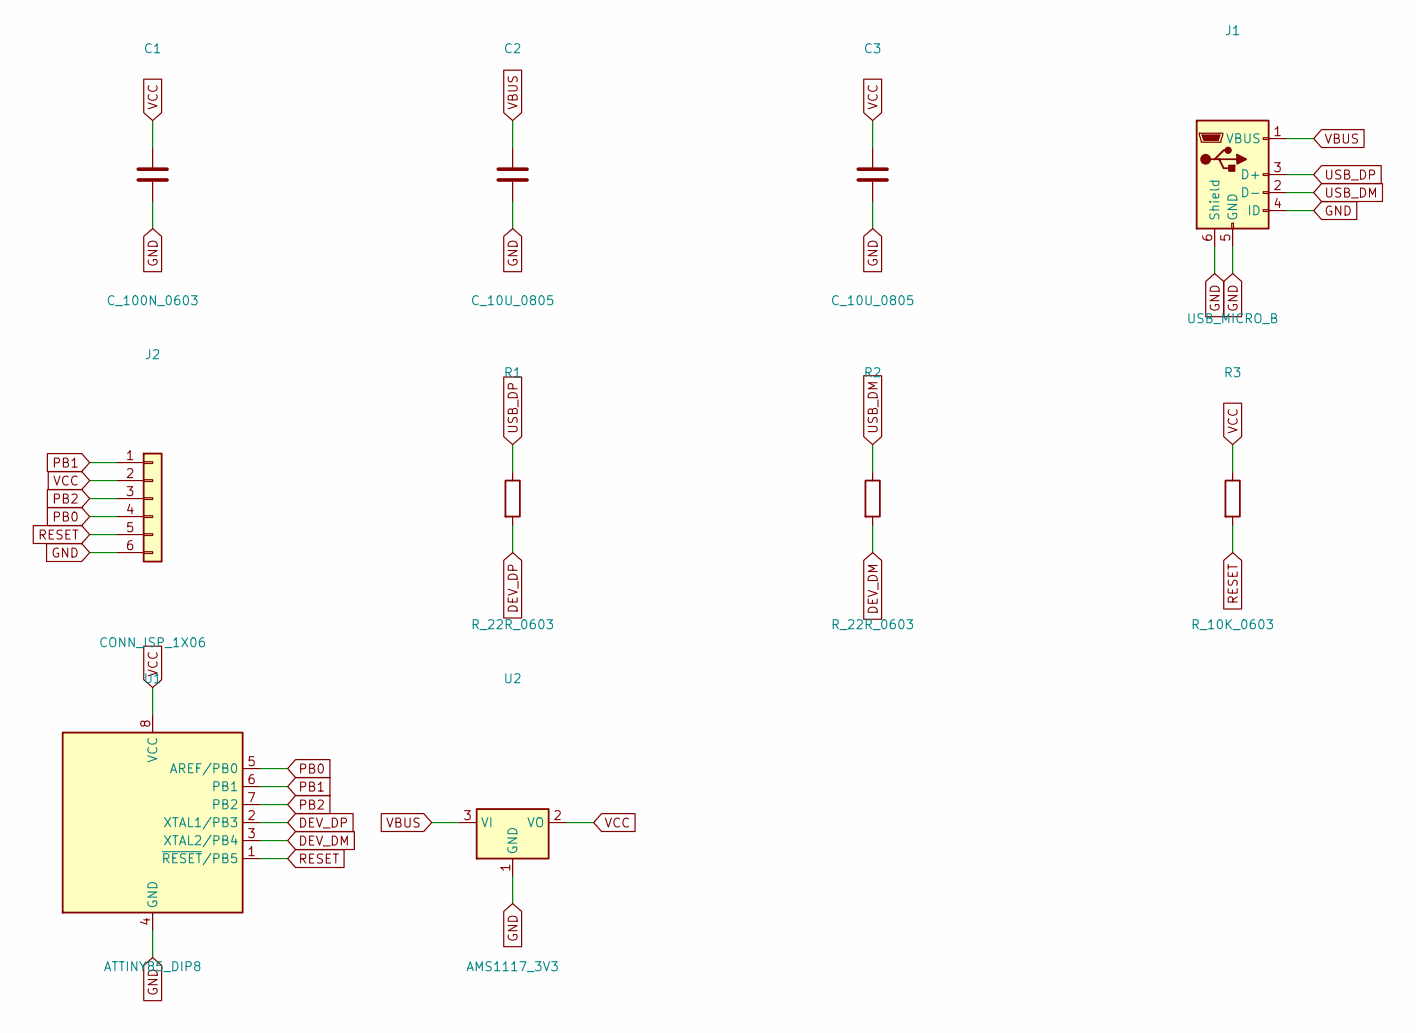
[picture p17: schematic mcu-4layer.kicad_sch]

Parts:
C1: C_100N_0603; C_0603_1608Metric
C2, C3: C_10U_0805; C_0805_2012Metric
J1: USB_MICRO_B; USB_Micro-B_Amphenol_10103594-0001LF_Horizontal
J2: CONN_ISP_1X06; PinHeader_1x06_P2.54mm_Vertical
R1, R2: R_22R_0603; R_0603_1608Metric
R3: R_10K_0603; R_0603_1608Metric
U1: ATTINY85_DIP8; DIP-8_W7.62mm
U2: AMS1117_3V3; SOT-223-3_TabPin2

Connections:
DEV_DM: R2.2, U1.3 (XTAL2/PB4)
DEV_DP: R1.2, U1.2 (XTAL1/PB3)
GND: C1.2, C2.2, C3.2, J1.4 (ID), J1.5 (GND), J1.6 (Shield), J2.6, U1.4 (GND), U2.1 (GND)
PB0: J2.4, U1.5 (AREF/PB0)
PB1: J2.1, U1.6 (PB1)
PB2: J2.3, U1.7 (PB2)
RESET: J2.5, R3.2, U1.1 (~RESET/PB5)
USB_DM: J1.2 (D-), R2.1
USB_DP: J1.3 (D+), R1.1
VBUS: C2.1, J1.1 (VBUS), U2.3 (VI)
VCC: C1.1, C3.1, J2.2, R3.1, U1.8 (VCC), U2.2 (VO)

Board: 4 copper layers, 10 parts (0 on the bottom side), 11 nets, no tracks yet.

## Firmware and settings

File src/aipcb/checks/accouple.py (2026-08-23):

# SPDX-FileCopyrightText: 2026 The aipcb Authors
# SPDX-License-Identifier: Apache-2.0
"""AC-coupling capacitors in a high-speed pair (M11c).

PCIe requires series capacitors on the transmitting end, and a series part in a
differential pair is a discontinuity in the middle of it: the pair stops being a
pair at the capacitors' pads, opens out to whatever pitch two 0402s can sit at,
and closes again on the far side. Nothing about that is avoidable. What *is*
avoidable is doing it asymmetrically, and an asymmetric AC coupling is a skew the
length matcher cannot see, because it is built into the placement rather than into
the copper.

So this is the check: mark the capacitors ``role: ac_coupling``, and aipcb works
out from their own nets which pair they sit in -- the two halves are two declared
differential pairs joined by two capacitors, and the netlist says so without
anybody having to name it twice -- then measures whether they are level with each
other across the pair's direction of travel and whether they face the same way.

**What this does not do**, and the deviation is deliberate: it does not *place*
the capacitors. The placer is M9's, positions are the source's, and a routing-side
generator that moved parts would be a bigger change than M11 asks for. It
validates the placement, measures the discontinuity, and the coupling budget in
the M11e report counts what the capacitors cost.
"""

from __future__ import annotations

import math
from dataclasses import dataclass
from typing import Any

from aipcb.compile.edge import AC_COUPLING_ROLE
from aipcb.compile.frame import frame_for
from aipcb.compile.place import BoardPlacement, component_extents, plan_placement
from aipcb.diagnostics import Report
from aipcb.netlist import Netlist

__all__ = ["AcCoupling", "ac_couplings", "run_ac_coupling_checks"]

Point = tuple[float, float]

#: How far out of line the two capacitors may sit, measured along the pair's own
#: direction of travel, before it is reported. Fifty microns: an order of magnitude
#: below any pair's skew budget, and well inside a pick-and-place machine's
#: accuracy, so a complaint here is about the source and not about the factory.
LEVEL_TOLERANCE_MM = 0.05


@dataclass(frozen=True, slots=True)
class AcCoupling:
    """Two capacitors in series with the two halves of one pair."""

    positive: str
    """The capacitor in the pair's positive half."""
    negative: str
    upstream: tuple[str, str]
    """The pair on the side the capacitors' first pads face."""
    downstream: tuple[str, str]
    at: tuple[Point, Point]
    """Where the two capacitors sit, in KiCad coordinates."""
    axis: Point
    """The pair's direction of travel through them, as a unit vector."""
    pitch_mm: float
    """How far apart the two capacitors sit, across the route."""
    skewed_mm: float
    """How far out of line they sit, along it. Zero is what this wants."""

    @property
    def key(self) -> str:
        return f"{self.upstream[0]}+{self.upstream[1]}"

    def to_dict(self) -> dict[str, Any]:
        return {
            "pair": self.key,
            "capacitors": [self.positive, self.negative],
            "upstream": list(self.upstream),
            "downstream": list(self.downstream),
            "pitch_mm": round(self.pitch_mm, 4),
            "out_of_line_mm": round(self.skewed_mm, 4),
        }


def ac_couplings(netlist: Netlist, placement: BoardPlacement) -> list[AcCoupling]:
    """Every pair of capacitors marked ``role: ac_coupling``, paired up.

    The pairing comes from the netlist rather than from a name in the source: a
    capacitor's two pins are on two nets, and where those nets' partners are the
    two nets of the *other* capacitor, the two capacitors are one coupling. That
    cannot disagree with the schematic, which a written-down pair name could.
    """
    caps = netlist.components_with_role(AC_COUPLING_ROLE)
    by_net: dict[str, str] = {}
    for cap in caps:
        for net in cap.connections.values():
            by_net.setdefault(net, cap.refdes)

    out: list[AcCoupling] = []
    seen: set[str] = set()
    for cap in caps:
        if cap.refdes in seen:
            continue
        nets = [cap.connections.get(pin) for pin in sorted(cap.connections)]
        partners = [
            (netlist.nets[net].attrs.diff_pair if net in netlist.nets else None)
            for net in nets
            if net
        ]
        mates = {by_net.get(p) for p in partners if p}
        mates.discard(cap.refdes)
        mates.discard(None)
        if len(mates) != 1:
            continue
        mate = next(iter(mates))
        assert mate is not None
        first = placement.positions.get(cap.refdes)
        second = placement.positions.get(mate)
        if first is None or second is None:
            continue
        seen.update({cap.refdes, mate})

        # Which net of this capacitor goes with which net of the other is decided
        # by `diff_pair:` and not by pin number: the two capacitors are often
        # mirror images of each other -- that is how their reference designators
        # stay off each other's silkscreen -- so pad 1 of one faces the controller
        # and pad 1 of the other faces the connector.
        other = netlist.components[mate]
        sides: list[tuple[str, str]] = []
        for net in sorted(set(cap.connections.values())):
            partner = (
                netlist.nets[net].attrs.diff_pair if net in netlist.nets else None
            )
            if partner and partner in set(other.connections.values()):
                sides.append((net, partner))
        if len(sides) != 2:
            continue
        upstream, downstream = sides

        axis = _axis(netlist, placement, cap.refdes, sorted(cap.connections))
        across = (-axis[1], axis[0])
        offset = (second.x - first.x, second.y - first.y)
        pitch = abs(offset[0] * across[0] + offset[1] * across[1])
        along = abs(offset[0] * axis[0] + offset[1] * axis[1])
        out.append(
            AcCoupling(
                positive=min(cap.refdes, mate),
                negative=max(cap.refdes, mate),
                upstream=upstream,
                downstream=downstream,
                at=((first.x, first.y), (second.x, second.y)),
                axis=axis,
                pitch_mm=pitch,
                skewed_mm=along,
            )
        )
    return sorted(out, key=lambda c: c.key)
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

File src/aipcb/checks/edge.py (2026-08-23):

# SPDX-FileCopyrightText: 2026 The aipcb Authors
# SPDX-License-Identifier: Apache-2.0
"""Card-edge connector integration checks (M11b).

Everything here is validation and glue. The fingers are the footprint's; the notch
is the footprint's; what this module does is make sure the board the source
describes is the board that footprint needs.

Four checks, in the order a reader wants them:

1. **the footprint is edge-fixed** -- a card edge is mechanical law, not a
   preference, so it wants a ``fixed:`` placement rather than a region;
2. **the outline agrees with the footprint**, segment by segment. The footprint
   draws its own ``Edge.Cuts``: the tongue, the chamfered tip, the keying notch.
   aipcb does not emit that geometry (see :mod:`aipcb.compile.edge`), so the
   ``board:`` block has to reproduce it, and when it does not the error message
   hands back the vertices that are missing, in the source's own frame and in the
   source's own syntax;
3. **the board is the thickness the slot expects** -- a warning, because a
   fabricator will build 1.6 mm and it will very probably work;
4. **the fab note**: the leading-edge bevel is a process step, not geometry aipcb
   can produce, and a card that reaches a fabricator without it on the drawing
   comes back unusable.
"""

from __future__ import annotations

import math
from dataclasses import dataclass

from aipcb.compile.edge import EDGE_ROLE, EdgeConnector, edge_connectors
from aipcb.compile.frame import BoardFrame, frame_for
from aipcb.compile.place import component_extents, plan_placement
from aipcb.diagnostics import Report
from aipcb.netlist import Netlist

__all__ = ["CARD_EDGE_SLOTS", "run_edge_checks"]

Point = tuple[float, float]

#: How far a footprint's own edge geometry may sit from the declared board edge
#: before it counts as missing. Ten microns: tighter than any fabricator's
#: tolerance, and looser than the rounding a hand-typed vertex carries.
EDGE_TOLERANCE_MM = 0.01

#: Card thickness the slot expects, per edge footprint, as ``(nominal, tolerance)``
#: in millimetres. From the connector specifications rather than from KiCad, which
#: says nothing about how thick the card is: PCI Express CEM gives the card edge as
#: 1.57 mm +/- 0.10 mm. A footprint not listed here gets no thickness check and
#: says so, because inventing a tolerance is worse than not having one.
CARD_EDGE_SLOTS: dict[str, tuple[float, float]] = {
    "Connector_PCBEdge:BUS_PCIexpress_x1": (1.57, 0.10),
    "Connector_PCBEdge:BUS_PCIexpress_x4": (1.57, 0.10),
    "Connector_PCBEdge:BUS_PCIexpress_x8": (1.57, 0.10),
    "Connector_PCBEdge:BUS_PCIexpress_x16": (1.57, 0.10),
}


@dataclass(frozen=True, slots=True)
class _Run:
    """A stretch of the footprint's edge geometry the board outline does not have."""

    points: tuple[Point, ...]

    @property
    def box(self) -> tuple[float, float, float, float]:
        xs = [x for x, _ in self.points]
        ys = [y for _, y in self.points]
        return (min(xs), min(ys), max(xs), max(ys))


def run_edge_checks(netlist: Netlist, report: Report) -> None:
    """Every edge-connector check. A no-op on a design with no edge connector."""
    if not netlist.components_with_role(EDGE_ROLE):
        return
    frame = frame_for(netlist)
    if frame is None:
        # `_placement_has_a_frame` already errors on this; a second complaint about
        # the same absence is noise.
        return
    extents, missing = component_extents(netlist)
    if missing:
        return
    placement = plan_placement(netlist, report=None, extents=extents, frame=frame)

    for connector in edge_connectors(netlist, placement, frame):
        _check_fixed(netlist, connector, report)
        _check_outline(netlist, connector, frame, report)
        _check_thickness(netlist, connector, report)
        _fab_note(netlist, connector, frame, report)


# ---------------------------------------------------------------------------
# 1. edge-fixed
# ---------------------------------------------------------------------------


def _check_fixed(netlist: Netlist, connector: EdgeConnector, report: Report) -> None:
    entry = netlist.placement.get(connector.refdes)
    if entry is not None and entry.level == "fixed":
        return
    report.error(
        "edge-connector-not-fixed",
        f"{connector.refdes} has `role: edge_connector` but is not placed with a "
        "`fixed:` position",
        loc=netlist.mech_loc("placement", connector.refdes),
        path=netlist.mech_path("placement", connector.refdes),
        hint="a card edge is mechanical law: its fingers have to coincide with the "
        "board outline, so the placer must not be free to move it. Give it "
        "`fixed: { x: ..., y: ..., rot: ... }`",
        component=connector.refdes,
    )


# ---------------------------------------------------------------------------
# 2. the outline agrees with the footprint
# ---------------------------------------------------------------------------
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

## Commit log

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2026-08-20 M2: compile designs into KiCad schematics that pass ERC
    `aipcb build` emits a .kicad_sch, a .kicad_pro carrying the net classes as KiCad
    design rules, and project-local library tables.
    Connectivity is expressed with net labels on pin stubs rather than routed wires
    (ADR 0003). This decouples correctness from placement: the label text comes
    straight from the net name, so a symbol can sit anywhere without the netlist
    changing. Placement stays as naive as the brief allows — a grid grouped by module
    instance — without putting correctness at risk.
    Acceptance was measured against KiCad 9.0.8 rather than asserted. For all three
    examples: ERC reports 0 violations, PDF export renders, and — th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
    [ldo-supply.kicad_sch, led-blinker.kicad_sch, usb-port.kicad_sch]
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2026-08-20 M4: map KiCad's ERC and DRC findings back to the source
    `aipcb check` builds a design, runs both of KiCad's checkers, and re-expresses
    every violation as an ordinary diagnostic pointing at the line of YAML that owns
    the offending element. Whether a problem came from our schema validator, our
    semantic checks, or KiCad's DRC, it now arrives in one shape with a file, a line,
    a stable code and a hint.
    The mapping is exact rather than heuristic, which is the whole payoff for the
    determinism requirement: every item in a KiCad report carries a UUID, and every
    UUID we emit is a hash of a source path, so recovering the owner is a dictionary
    lookup. No coordinate matching, no parsing description stri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
    [ldo-supply.kicad_pcb, usb-port.kicad_pcb]
2026-08-20 M5: partial reads of a design, for token economy
    `aipcb summary` gives a one-line-per-block overview, and `aipcb query` narrows to
    one module, component, net, net class or role. All take --json, and text and JSON
    render the same structure so they cannot disagree about what a design contains.
    `query module` includes the components on the *other* side of the module's ports.
    A module read in isolation says nothing about what it drives, and that context is
    usually the reason it is being read at all.
    Also fixes automatic designator assignment. Auto-numbered parts inside a module
    took their prefix from the source name, so the LDO's input capacitor became CIN1
    rather than C1. Valid, but BOM tools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
    [ldo-supply.kicad_pcb, ldo-supply.kicad_sch]
2026-08-20 M6: incremental builds that keep manual work, and fabrication export
    `aipcb build` is now incremental. The rule is one sentence: the source owns what
    it declares; everything else belongs to the person who drew it.
    Identity comes from the UUIDs, which are hashes of source paths — the third job
    that scheme does, after diff stability and violation mapping, and the third reason
    ADR 0001 could not accept a library that rewrites them. Whether the source has
    changed its mind comes from a per-footprint fingerprint of the facts that actually
    determine placement: part, footprint, connections, side, and the constraints naming
    it. Match, and a hand-placed part stays where it was put; differ, and the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
    [ldo-supply.kicad_pcb, led-blinker.kicad_pcb, usb-port.kicad_pcb]
2026-08-20 M7a+M7b: topological routing — sketches in source, DRC-clean copper out
    Routes are stored as topology: which obstacles a wire passes and on which side.
    Nothing in the source is a coordinate, so moving a part leaves the sketch true and
    only the tightening re-runs — which is the whole point of the approach (ADR 0006,
    written after reading SURF, Maley, TopoR and the shortest-homotopic-path
    literature).
    Geometry comes from the classical pipeline: inflate obstacles by the clearance the
    net needs, triangulate what is left (constrained Delaunay, via Shapely/GEOS), turn
    the sketch into a crossing sequence, reduce it to a canonical homotopy class, and
    tighten the resulting sleeve with the funnel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
    [ldo-supply.kicad_pcb, routing-demo.kicad_pcb, routing-demo.kicad_sch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]
2026-08-20 M7c: auto-topology weighs corridor width, not only length
    Connections without an explicit sketch now get a topology that charges for
    squeezing through narrow gates. The shortest route otherwise takes the one gap a
    later net had no alternative to, and the later net fails.
    Congestion needs no separate bookkeeping, which is the pleasing part: free space is
    what obstacles and already-laid tracks leave behind, so a gate an earlier route
    used is literally narrower on the next net's triangulation. Measuring the remaining
    corridor measures the congestion.
    The default weight is measured rather than guessed. Across the bundled examples,
    routing for length alone strands one more connection and lays 4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
2026-08-20 M7d: differential pairs routed as pairs, with honest limits
    A pair's impedance comes from the coupling between its halves, so routing them
    independently routes something else with the same netlist. A pair is now tightened
    once, as a single centre-line wide enough for both traces and the gap, then offset
    to either side. The gap is correct everywhere by construction, corners included,
    and the halves come out the same length: 43.00 mm each with 0.000 mm skew on the
    new diff-pair example.
    Where a class gives an impedance but no gap, the gap is estimated from the standard
    edge-coupled microstrip formula and reported as an estimate. Where the target is
    unreachable by spacing at all — a 0.34 mm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
    [diff-pair.kicad_pcb, diff-pair.kicad_sch]
2026-08-21 docs: give the milestone prompts a home and fix their stale references
    The milestone prompts moved into docs/milestones/ and were renamed. They were
    written before that structure existed, so their internal references pointed at
    files that were "attached" rather than at paths in the repo.
    - The orchestrator now reads the three milestone files from docs/milestones/
    rather than expecting them alongside itself, and is explicit that a milestone
    subagent gets the full file content read from disk -- never a summary. Being
    pointed at the orchestrator file is the whole of its input; the rest is in the
    repo.
    - M10/M11/M12 each say what to do when an expected report is missing: reports
    befor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
2026-08-21 docs: recover the missing M8 and M9 delivery reports
    docs/reports/ was empty because the report requirement arrived with M10, so the
    two milestones that had already run left no record of what they delivered --
    which is exactly the context M10 is told to start from.
    m8.md is a reconstruction, assembled from ADR 0007, topology.md,
    routing-costs.md, the M8 specification, the code and the test suite. It says so
    at the top, and it separates numbers recorded during M8 (the via-relaxation
    figures ADR 0007 captured while the work happened) from numbers measured today
    -- which are post-M9 and are labelled as such rather than passed off as the
    originals. The original session's wall-clock and iteratio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
2026-08-21 M8+M9: multilayer routing, and the board's mechanical boundary
    Two milestones in one commit, because the boundary between them is not
    recoverable. M9 was built directly on top of M8 while M8 was still
    uncommitted, and the two sets of changes are interleaved inside the same
    functions -- not merely in the same files.
    The measurement that decided it: of the 40 modified files, 10 carry changes
    from both milestones, and git resolves src/aipcb/route/plan.py -- the file
    both milestones are largely about -- into 3 hunks, 2 of which contain lines
    from each. route_board() alternates between them within one function body:
    step 0 is M9's fanout stage, step 1 is M8's sketch realization operating on
    term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
    [congestion.kicad_pcb, congestion.kicad_sch, enclosure.kicad_pcb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]
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2026-08-21 M10: tighten two claims in the pours findings
    The jobset job-type enumeration said "eleven pcb_export_*"; there are ten, and
    the honest form is the complete identifier set rather than a partial list. Adds
    the sharper piece of evidence found alongside it: ZONE_FILLER appears in KiCad
    9.0.8's shipped libraries only as its SWIG binding, so the Python API is the
    only surface that exposes it at all.
    Suite state in the report now records what was actually run — pytest exit 0 over
    874 collected tests — rather than a pass/skip split quoted from the baseline.
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2026-08-21 decisions: accept ADR 0009 Option 1, and update M12 against measured reality
    ADR 0009 is accepted as Option 1 — fill via a pcbnew subprocess — recorded as a
    deliberate amendment to ADR 0001 rather than a quiet exception, with four binding
    conditions: the rationale, a pcbnew/kicad-cli version lock with no silent
    cross-version fills, an explicit framing as a bridge to be re-measured at each
    KiCad major, and subprocess hygiene (documented interpreter resolution, stderr
    propagated as a check failure, a test for pcbnew being absent).
    M12's framing assumed minutes-to-hours per pair; phase 0 measured 30 s - 2 min.
    Updated the economics, marked phase 0 complete so the milestone agent does not
    r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
2026-08-21 fix: the drill origin every export flag already assumed
    `export` has always asked kicad-cli for fabrication output relative to the
    drill/place file origin -- `--use-drill-file-origin` for Gerbers, `--drill-origin
    plot` for drill. The board writer never emitted an `(aux_axis_origin ...)`, so
    that origin silently defaulted to the page corner and the flags did nothing.
    The result is the worst kind of defect this project exists to prevent: nothing
    fails. The Excellon is well formed and KiCad reads it back perfectly. But every
    coordinate lands in absolute page space with a negated Y, so `examples/mcu-4layer`
    exported holes like `X129.0Y-123.5`. A consumer that parses unsigned coordinates
    -- gerb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
    [congestion.kicad_pcb, diff-pair.kicad_pcb, enclosure.kicad_pcb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]
2026-08-21 fix: name the placement file what a KiCad consumer looks for
    `export` wrote the placement file as `positions.csv`. Every tool that consumes a
    KiCad placement file discovers it by glob -- gerber2ems runs
    `(cwd / "fab").glob("*pos.csv")` in both `importer.py` and `config.py`, and its
    docstring says "files ending with `-pos.csv`". `positions.csv` ends in
    `ions.csv`, so it matched nothing. The consumer then simply carried on: no
    exception, no warning, a simulation with no ports in it. Silence again, which is
    the failure mode this project is meant to make impossible.
    Which side was wrong was checked rather than assumed. KiCad 9's own
    `DIALOG_GEN_FOOTPRINT_POSITION` builds the name from
    `PLACE_FI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
2026-08-21 M10: the stability policy, the findings, and the delivery report
    The byte-identical guarantee is now stated in the one place it is actually true:
    build output. `docs/format.md` and the README say so, and say why -- the fill is
    a derived artefact, deterministic in its geometry but written into a file KiCad
    stamps fresh UUIDs into.
    That correction came from re-measuring. ADR 0009's Finding 3 recorded the whole
    filled file as byte-identical across runs; on the shipping code it is not, and
    exactly twelve lines differ, all of them uuids of properties KiCad's writer adds
    to footprints that lack them. Findings 5 to 10 record that and the five other
    things building this taught -- including that KiC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
2026-08-21 M11a+M11b: controlled-impedance net classes, and the card edge as a footprint
    Two of the five pieces, and the reference board they are for.
    M11a. `impedance_diff_ohm` on a net class derives the pair's trace width from
    the stackup instead of asking for one. The derivation lives in `impedance.py`
    (IPC-2141 for the controlled-impedance path, Hammerstad kept on the M8 path so
    no board built before this changes its geometry) and `highspeed.py` resolves it
    against `layout.stackup.layers` -- a block that has been in the schema since M1
    and was decorative until now. `checks/impedance.py` validates what comes out:
    a target the stackup cannot reach, an explicit width that contradicts it by more
    than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
    [edge.py, highspeed.py]
2026-08-21 M11d+M11e: the three stretcher rules, and the report that says what they found
    M11d, for classes with `impedance_diff_ohm` and for nothing else:
    1. the centre-line is tightened against `clearance x standoff_k` rather than the
    bare minimum. Default 3, and the reference board sets 1.4 with the arithmetic
    written down: a pair leaving a 0.5 mm pad pitch has 0.625 mm to its neighbour
    and a 0.73 mm corridor of its own, so 0.45 mm of standoff does not exist
    there. At k=3 every pair on that board is refused, correctly and loudly.
    2. a coupled run that stays within 3 x its gap of another copper feature for
    longer than 5 x it is re-tightened once with that feature's clearance
    inflat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
    [highspeed.py, loop.py, planes.py]
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2026-08-21 M11: the tests, and the finding that made the via-stub number real
    Seventy-four tests, split the way M10's were: arithmetic that needs only
    numbers, validation that needs only a source, generation asserted off the
    geometry it produced, and the reference board checked once and asserted against
    many times.
    The acceptance tests the specification names, each on a fixture built to make
    the answer knowable:
    * the missing keying notch, which has to fail *helpfully* -- the assertion is
    that the error's hint contains a pasteable `board:` block with the notch's own
    vertices in it;
    * the via transition: two signal vias symmetric about the point the source
    named, the column opened out from the p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
    [pcie-sata.kicad_pcb, pcie-sata.kicad_sch]
2026-08-21 M11: docs, ADR 0010, and the keepout the UUID index had not heard of
    ADR 0010 records the reference stackup and the geometry it implies, the eight
    findings the milestone measured, and the four decisions that shaped it: an
    impedance instead of a width, an outline with one author, a transition column
    that opens out rather than a pair that is refused, and a report that says what
    it is not.
    `docs/format.md` grows three sections and thirty diagnostic codes.
    `docs/roadmap.md` grows a High speed section, and records two things this
    milestone found and did not fix: a board that has no signal layer left to cross
    a lane on, and `_repair` producing a route that crosses another net.
    And a defect the f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
    [mapping.py]
2026-08-21 M11: the delivery report, written and measured in a second pass
    The milestone's implementation session was terminated by an infrastructure
    failure at the moment it said "Now the performance measurements:", with all of
    M11a-M11e, its tests and ADR 0010 already committed and only the report missing.
    This is that report, reconstructed from the repository and measured fresh on a
    quiet machine. It says so at the top, because a reader deserves to know which
    parts are an account and which are archaeology.
    The headline the milestone asked for, measured rather than inferred: eleven of
    eleven pairs on `examples/pcie-sata` route as coupled pairs, nothing is handed
    over, nine of the twelve pair objects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
2026-08-21 M12: the two export gaps that were left, fixed by reading the files back
    `pcb export pos` defaults to absolute page coordinates, so aipcb's placement file
    held the board's position on an A4 sheet with KiCad's downward Y -- `145.500000,
    -122.500000` for a part 45.5 mm from the board's left edge. Naming the file
    `*-all-pos.csv` had made it discoverable; this makes what is in it mean something.
    `--use-drill-file-origin` measures every row from the drill/place origin, which is
    the board's own bottom-left corner.
    The drill export gains `--excellon-separate-th`. Without it KiCad emits one
    `MixedPlating` file called `<board>.drl`, which is valid Excellon that no consumer
    globs for -- gerber2ems lo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
2026-08-21 M12a/M12b/M12c: aipcb simulate, and the silent failure nobody predicted
    One slice per differential pair, cut out of a routed board, solved by openEMS in
    the container ADR 0011 pinned, and turned into the same source-referenced findings
    as every other check.
    The slice is a real `.kicad_pcb` -- same stackup, same pours, same design rules,
    with a tight outline round one pair -- so `kicad-cli` plots it like any other board
    and ADR 0001 still holds: aipcb writes no Gerber itself, not even for a solver.
    Three things in it are not on the real board and each is deliberate: the
    `role: ac_coupling` capacitors become copper bridges (which is what they are at
    4 GHz, and which turns pcie-sata's twelve d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
2026-08-21 M12: a timeout that leaves a sixteen-core solver running is not a timeout
    Found by hitting it. A mesh-convergence run at 25 um overran the 900 s per-pair
    limit; the client was killed, the run was correctly reported as failed, and the
    container carried on solving in the background where nothing was watching it. On an
    unattended batch that is how one slow pair takes the machine down.
    The container is now named and removed on timeout. The limit itself was wrong as
    well: phase 0's 30 s - 2 min came from a two-layer slice with no pour, and the
    boards this milestone actually simulates are four-layer with planes on both sides of
    the signal, where the measured range is 1 to 13 minutes. Half an hour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
2026-08-21 M12: the docs, and ADR 0011 extended with what the integration decided
    `docs/format.md` gains a `simulation:` section: the block, the defaults, what a run
    leaves behind, and -- at the same length -- what it cannot tell you. The three
    approximations in a slice are written down there rather than left in a docstring,
    because a reader deciding whether to trust a number needs them.
    ADR 0011 is extended rather than replaced. Phase 0's findings stand; what is added
    is the reuse-versus-reimplement call on Antmicro's wrapper and the four specific
    reasons for it, why the stackup comes from the source and not from the `.kicad_pcb`,
    why there is no `--parallel` and no scikit-rf, and the three silent fa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
2026-08-21 M12: make a cache hit actually cost nothing
    The digest is a hash of the three files the solver reads, and two of the three are
    produced by slicing, not by plotting. Computing it after the export meant an
    unchanged pair still paid for a zone fill and five runs of kicad-cli before being
    told to skip -- about seven seconds a pair, a minute and a half across pcie-sata,
    for an answer already on disk.
    Slicing and the solver's configuration now come first, the digest is taken there,
    and a hit returns before anything is plotted. A cold run is unchanged; `--dry-run`
    still exports and still reads the Gerbers back, because validating the input path
    without spending a minute on the solver is the whole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
2026-08-21 M12: round the ripple-period trim rather than flooring it, because flooring measured worse
    The impedance band is trimmed to a whole number of standing-wave periods so the
    median lands on the line rather than on a half period. Flooring the count does that
    badly: on the mcu-4layer convergence sweep the band holds 1.9 periods, flooring cut
    it to 1, and throwing away half the samples spread three mesh densities over 6.5%
    where keeping all of them spread them over 5.3%.
    Rounded and clamped to the band, so the trim shortens the sweep only when that gets
    closer to a whole number of periods. Measured, on 0.45 M / 2.05 M / 5.07 M cells of
    the same geometry: 75.96, 74.19, 78.12 ohm.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
2026-08-21 M12: launch the ports across the pair, not along it, and clear the room they need
    Two defects in one construction, both found by looking at the geometry openEMS was
    actually given rather than at the numbers it returned.
    **The launches were welded together.** The direction was the average of the two
    traces' outgoing directions, which on a pair that leaves its pads broadside comes out
    *along* the line joining them: both launches then run on one line, overlap, and short
    P to N. `examples/pcie-sata`'s PCIe lanes leave the controller exactly like that.
    Measured before the fix, on the transmit lane: |Sdd21| of 7.26, a return loss of
    +40 dB and 437 ohm against an 85 ohm target. The rule is now per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
2026-08-22 M13: the copper the obstacle set was losing, and the pour the impedance ignored
    Four things, and the first two are the same class of defect one level apart: a
    number that looked right because nothing was in a position to say otherwise.
    **M13a — `_repair` was obeying an obstacle set that had lost four polygons.** M11
    found it routing PRSNT across two REFCLK tracks and could not explain it, because
    the copper it crossed *was* in the list of finished obstacles. The missing step is
    that the list becomes a dict keyed by obstacle name on the way into the free-space
    calculation, and two pieces of copper that share a name become one. A differential
    pair split across two layers by a via transition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
    [highspeed.py, impedance.py]
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2026-08-22 M13.5: the DRC categories nobody could see, and the energy that never left
    Closes M13's half-open acceptance. Free work first, which is why three of the
    five steps cost no solver time at all.
    **The check-visibility question had two answers.** `check` reports a deliberate
    track crossing as an error and always could -- the crossings M13a fixed only ever
    existed on a board carrying a strap the shipped example leaves off the netlist,
    verified by running the real `check` on the pre-fix tree. What it genuinely cannot
    see is one level down: `kicad-cli pcb drc --severity-all` includes error, warning
    and exclusion and *not* `ignore`, so a rule KiCad holds at `ignore` is dropped
    inside KiCad with not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
    [kicad_reports.py, loop.py]
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2026-08-23 M14: the sheet that could not be reviewed, and the router that was never asked
    Two themes. The generated schematics were electrically correct and unreadable:
    every fact the source knew about *why* a part exists -- `role`, `for:`, the module
    hierarchy, the netlist graph -- died at the sheet boundary, and a capacitor whose
    purpose is to sit at one pin of one IC was placed by its position in a sorted list.
    On pcie-sata that was 157.5 mm from the pin it decouples, on a sheet 594 mm wide.
    And manual routing was something that *happened* to a board rather than something
    the source could declare.
    Placement is now derived in five steps (aipcb/compile/sheet.py): satellites attach
    to what they serve,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
    [congestion.kicad_sch, diff-pair.kicad_sch, enclosure.kicad_sch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]
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2026-08-24 M21: the BOM and the centroid an assembler takes -- and the part that cannot have one
    `aipcb export --bom --cpl --assembly --format jlcpcb|pcbway|generic` writes what an
    assembler needs on top of what a fabricator does. The requirements come from each
    fab's own published documentation, fetched and quoted in ADR 0015 §2, not from
    somebody's exporter.
    The audit answered the brief's own question first: the existing `bom.csv` and
    placement CSV are correct KiCad output and neither is an assembly file. `Supplier`
    has carried `manufacturer` and `mpn` since the beginning and only `datasheet` ever
    reached anything -- the other two were dead fields.
    Three decisions worth the diff:
    * **The centro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
    [pcie-sata-bom-generic.csv, pcie-sata-bom-jlcpcb.csv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]
